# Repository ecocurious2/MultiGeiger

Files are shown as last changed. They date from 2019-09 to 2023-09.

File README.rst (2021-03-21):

MultiGeiger
-----------

The MultiGeiger is a radioactivity measurement device.
It has a lot of interesting properties, which you can find on the first page of the docs.

Der MultiGeiger ist ein Messgerät für Radioaktivität.
Er hat viele interessante Eigenschaften, die man auf der ersten Seite der Doku nachlesen kann.

Documentation
~~~~~~~~~~~~~

https://multigeiger.readthedocs.org/  (english + deutsch)

There is our new, versioned and translated documentation (see the box at the
lower right there to switch languages and documentation versions)!

Dort ist unsere neue, versionierte und übersetzte Doku (siehe die Box
rechts unten, mit der man Sprache und Version umschalten kann)!

Quicklinks
~~~~~~~~~~

* Default Wifi-Password: "ESP32Geiger"
* Multigeiger map / Karte:

  https://multigeiger.citysensor.de/

* Übersichtsseite bei Ecocurious / Ecocurious project overview page (German):

  https://ecocurious.de/projekte/multigeiger-2/

* Online Multigeiger event room with some instruction videos (German) to discover / Online Multigeiger-Raum mit einigen Anleitungsvideos zum Entdecken:

  https://play.wa.binary-kitchen.de/_/global/raw.githubusercontent.com/ecocurious2/rc3_2020/main/main.json

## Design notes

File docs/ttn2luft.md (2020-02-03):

# TTN --> Luftdaten
rxf 2020-02-03

### Payload der LoRa-Sendung

Port | ByteNr | Wert [hex]| Beschreibung | Beispiele
-----|--------|------|------------- | ---------
1    | 0/1/2/3 | 00000107 | Anzahl der Impulse (counts) | => 263
1    | 4/5/6   | 0249F0 | Messzeit [ms] für diese Impulse (sample\_time\_ms) | => 150000
1	   |	  7/8  | 10C0   | Software-Version (software_version)| 1.12.0 (siehe unten)
1	   |	   9   |  16    | Bezeichnung des Zählrohres (tube) |Si**22**G
||||
2	   |	  0/1   | 0107   | BME280 Temperatur in 0.1° (temperature)| 0x107 => 26.3°
2	   |	   2    | 9A     | BME280 Feuchte in 0.5% (humidity)|0x9A => 77.0%
2	   |	  3/4   | 26E0   | BME280 Luftdruck in 0.1 hPa (pressure) | 0x26E0 => 995.2 hPa

Erläuterung zur Software-Version: Die obersten 4 Bit sind die Major-Version (hier 1, max. 15), die folgenden 8 Bit die Minor-Version (hier 0x0C => 12) und die untersten 4 Bit der Patchlevel (hier 0).

Bezeichnung der z. Zt. implementierten Zählrohre:  

Name | Nummer [hex]
-----|-------
SBM-19 | 0x13
SBM-20 | 0x14
Si22G	 | 0x16

Die Daten des BME280 werden nur gesendet, wenn auch ein BME280 vorhanden ist.

### Payload-Decoder
Wir verwenden **keinen** Payload-Decoder.
Sollte es nötig sein, die Daten irgendwie umzuwandeln, dann muss die HTTP-Integration das machen - also das Programm, das da dahinter sitzt.

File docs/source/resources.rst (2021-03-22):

.. include:: global.rst.inc
.. _resources:

Resources
=========

This is a collection of additional resources that are somehow related to MultiGeiger.

Hardware / Parts
----------------
MultiGeiger supported counter tubes:
 -  Si22G, SBM-20, SBM-19

MultiGeiger supported ESP32 boards:

- Heltec WiFi Kit 32 (WiFi-only, infos from board manufacturer)
  https://heltec.org/project/wifi-kit-32/

- Heltec Wireless Stick (WiFi+LoRa, infos from board manufacturer)
  https://heltec.org/project/wireless-stick/

Software
--------

- Windows driver for the USB -> UART chip CP2102:
  http://esp32.net/usb-uart/#SiLabs

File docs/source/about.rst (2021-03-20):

About
-----

The **MultiGeiger** is a project of Ecocurious, your community for environment, nature and technology, see https://ecocurious.de/projekte/multigeiger/.

The goal is to establish a citizen measurement network for radioactivity in Germany.

The **MultiGeiger** hardware and software was designed by Jürgen Böhringer (http://www.boehri.de).

Reinhard/rexfue has further developed the software, the board, and is taking care of the integration of the sensors into our map https://ecocurious.de/multigeiger-karte/.

We have started the first workshops where you can assemble the components and the case with our support.

Workshop dates can be found here:
 * https://www.meetup.com/de-DE/Ecocurious-deine-Umwelt-Natur-und-Technik-Community/
 * https://ecocurious.de/events/

Does this sound interesting to you? Then join us, we cordially invite you!

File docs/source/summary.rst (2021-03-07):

Overview
========

What is MultiGeiger?
--------------------

The MultiGeiger is a radioactivity measurement device.

Main features
~~~~~~~~~~~~~

**multiple use cases supported**

 * fixed location stations (data transfer via network)
 * mobile operations (using the OLED display and speaker)
 * (more are planned)

**multiple 400V Geiger-Mueller tubes supported**

 * big, sensitive tubes, like the Si21g or Si22g (for measurement stations)
 * smaller, less sensitive tubes, like the SBM21 (good for finding hot spots)

**Hardware**

 * low parts count, simple to assemble
 * inexpensive, but still good parts
 * using ESP32, a modern and fast 32bit micro controller
 * with WiFi (WPA2) or with WiFi + LoRA
 * with OLED display

**Firmware**

 * implemented in C
 * using the popular arduino API
 * over-the-air firmware updates

**Network and Community**

 * this is an Ecocurious citizen science project
 * web-based geo map for publishing measurements
 * web-based archive of historic radiation data

**Free and Open**

 * GPL v3 licensed
 * open development and issue tracking on GitHub

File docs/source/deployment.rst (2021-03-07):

.. include:: global.rst.inc
.. highlight:: none
.. _deployment:

Deployment
==========

When deploying the MultiGeiger measurement station, you need to consider some things.

Of course, for us private persons, there rarely will be a 100% perfect deployment place.
But still, we can be aware of the parameters which may have a negative impact.

Requirements for the deployment place
#####################################

+--------------------------------------------------------------------------------------------+--------------------+
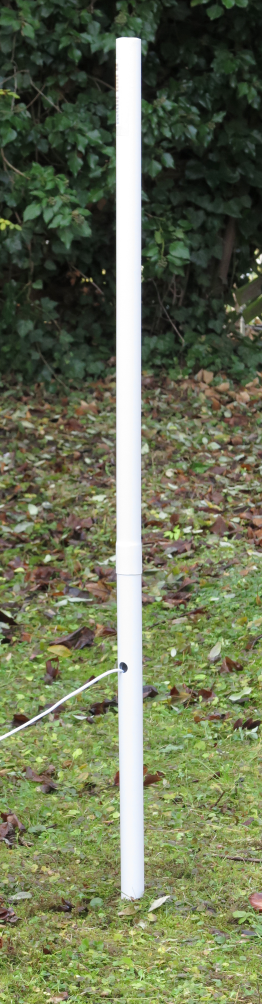
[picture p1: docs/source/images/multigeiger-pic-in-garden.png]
| In any case we need this at the deployment place:                                          |         |
|                                                                                            |                    |
| - WiFi or LoRa reception for data transmission (A)                                         |                    |
|                                                                                            |                    |
|   WiFi can come from inside the house, LoRa from some TTN LoRa gateway.                    |                    |
|                                                                                            |                    |
| - Power: 5 V / ~ 100 mA (B)                                                                |                    |
|                                                                                            |                    |
|   Power can come from inside the house via a 5V cable or from other power supply.          |                    |
|                                                                                            |                    |
| - Irrigation area (C)                                                                      |                    |
|                                                                                            |                    |
|   E.g. some lawn, meadow or similar that gets some rainfall, potentially including fallout.|                    |
+--------------------------------------------------------------------------------------------+--------------------+



Choosing a deployment place
###########################

We want to measure radioactive substances (dust), also known as "fallout".
They come from e.g. nuclear explosions or reactor desasters.

In a very weak variant, they also naturally come from the atmosphere due to the decay of the radioactive noble gas radon.
This "radon fallout" causes a small, but measurable peak on our devices, which degrades with a half life of 45 minutes.

With the help of these "radon peaks", we can see whether our device is deployed to a good place and is sensitive also for "real" fallout.

Irrigation area
---------------

We need a bigger irrigation area in the direct vicinity of the measurement station.
This area should also have the capability to hold and store radioactive particles.

A lawn or a meadow is perfect for this.

On the other hand, some asphalt can not do that, because particles are washed away directly after raining down. 

Wind direction
--------------

The area should be unobstructed from the main wind direction by other buildings, bushes or trees.

Sun light
---------

The power supply cable as well as the MultiGeiger device itself, should be in the shadows most of the time.

Direct sunlight can have two negative influences:

- Heat:
  The temperature inside the device can rise to up to 60 deg celsius in direct sunshine (45 deg celsius in the shadows).
  We did practical temperature tests showing that the device works ok up to 70 deg celsius.
  But the GM tube is only specified to up to 50 deg celsius.

- UV damage:
  Over time, the cable and case can be damaged by UV radiation and get porous.

Examples
########

Examples of good and bad deployment places:

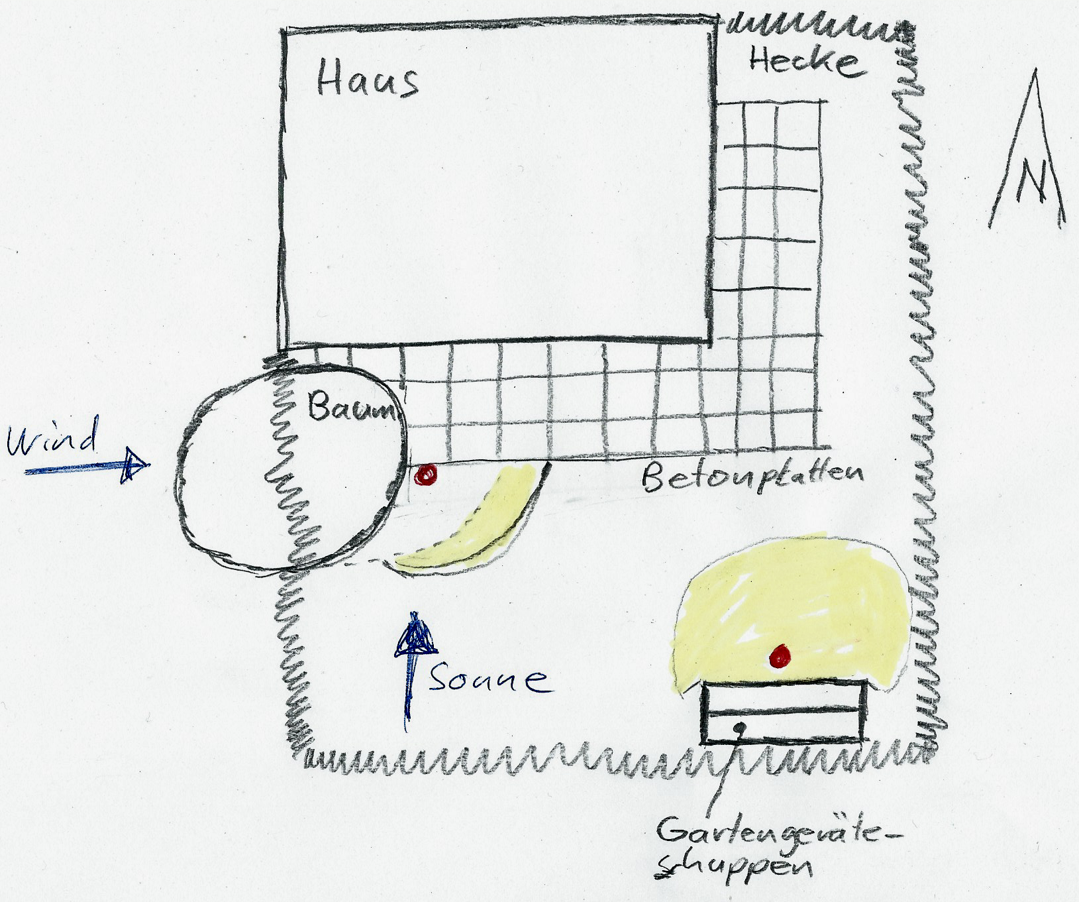
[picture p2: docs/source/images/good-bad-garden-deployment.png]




Comparison of two deployment places. Yellow is the "usable irrigation area".

Bad deployment place (red dot at the left)

Reasons:

- Meadow: a bit part of the area around the GM device is made of concrete platter. Incapable of holding/storing fallout.
- Wind: the main wind direction is from the west and the tree obstructs fallout raining down close to the device.
- Sun: Sunlight comes primarily from the south and strongly shines on the devices.

Good deployment place (red dot at the right) 

Reasons:

- Meadow: a big part of the area around the GM device is meadow, which can hold/store fallout.
- Wind: no obstruction
- Sun: the GM device is in the shadow due to the garden shack.

More Information
################

Description of the BFS-ODL measurement network (german):

- `Messnetz <https://www.bfs.de/SharedDocs/Downloads/BfS/DE/broschueren/ion/radioaktivitaetsmessnetz.pdf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>`_
- `ODL-Sonde <https://odlinfo.bfs.de/DE/themen/wie-wird-gemessen/odl-sonde.html>`_

Video interview about the BFS-ODL measurement network (german):

- `Interview über das BFS-ODL-Netzwerk <https://www.bfs.de/SharedDocs/Videos/BfS/DE/kt-interview-umweltueberwachung.html>`_

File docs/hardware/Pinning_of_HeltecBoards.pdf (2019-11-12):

### Table 1

PIN | Wifi Kit 32 (new) | Wireless Stick | WirelessStick Lite | Legend
0 | SPEAKER | SPEAKER | SPEAKER
1 | NOT AVAILABLE | NOT AVAILABLE | NOT AVAILABLE
2 | GMZ_CNT | GMZ_CNT | GMZ_CNT
3 | NOT AVAILABLE | NOT AVAILABLE | NOT AVAILABLE
4 | OLE_SDA | OLE_SDA | free
5 | free | LoRa_SCLK | LoRa_SCLK
6 | NOT AVAILABLE | NOT AVAILABLE | Flash_CLK
7 | NOT AVAILABLE | NOT AVAILABLE | Flash_SD3
8 | NOT AVAILABLE | NOT AVAILABLE | Flash_SD1 | | used by Geiger
9 | NOT AVAILABLE | NOT AVAILABLE | free | | internally used by chip
10 | NOT AVAILABLE | NOT AVAILABLE | free | | pin not broken out
11 | NOT AVAILABLE | NOT AVAILABLE | Flash_SD2 | | unused pins
12 | SPEAKER | SPEAKER | SPEAKER
13 | free | free | Power_Detect
14 | free | LoRa_RST | LoRa_RST
15 | OLED_SCL | OLED_SCL | free
16 | OLED_RST | OLED_RST | Flash_CS
17 | free | free | Flash_SD0
18 | free | LoRa_CS | LoRa_CS
19 | free | LoRa_MISO | LoRa_MISO
20 | NOT AVAILABLE | NOT AVAILABLE | NOT AVAILABLE
21 | free | V_SPI_HD | Vext_Control
22 | HV_CAP_FUL | HV_CAP_FUL | HV_CAP_FUL
23 | HV_FET_OUT | HV_FET_OUT | HV_FET_OUT
24 | NOT AVAILABLE | NOT AVAILABLE | NOT AVAILABLE
25 | LED | LED | LED
26 | free | LoRa_DIO0 | LoRa_DIO0
27 | free | LoRa_MOSI | LoRa_MOSI
28 | NOT AVAILABLE | NOT AVAILABLE | NOT AVAILABLE
29 | NOT AVAILABLE | NOT AVAILABLE | NOT AVAILABLE
30 | NOT AVAILABLE | NOT AVAILABLE | NOT AVAILABLE
31 | NOT AVAILABLE | NOT AVAILABLE | NOT AVAILABLE
32 | XTAL_32 | XTAL_32 | XTAL_32
33 | XTAL_32 | XTAL_32 | XTAL_32
34 | free - IN _ NO_PUP | LoRa_DIO2 | LoRa_DIO2
35 | free - IN _ NO_PUP | LoRa_DIO1 | LoRa_DIO1
36 | GPIO36 - IN _ NO_PUP | GPIO36 - IN _ NO_PUP | GPIO36 - IN _ NO_PUP
37 | GPIP37 - IN _ NO_PUP | GPIP37 - IN _ NO_PUP | GPIP37 - IN _ NO_PUP
38 | GPIO38 - IN _ NO_PUP | GPIO38 - IN _ NO_PUP | GPIO38 - IN _ NO_PUP
39 | GPIO38 - IN _ NO_PUP | GPIO38 - IN _ NO_PUP | GPIO38 - IN _ NO_PUP

1

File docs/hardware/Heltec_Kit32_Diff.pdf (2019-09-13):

# Unterschied Heltec Wifi 32:

Zwei neue Boards mit identischer Bezeichnung wie die alten (Heltec WiFi Kit 32) am 10.9.2019 bei Amazon gekauft. Leider unterscheiden diesen beiden sich von den alten (bei Ali gekauften) Boards:
Alt: | Neu:

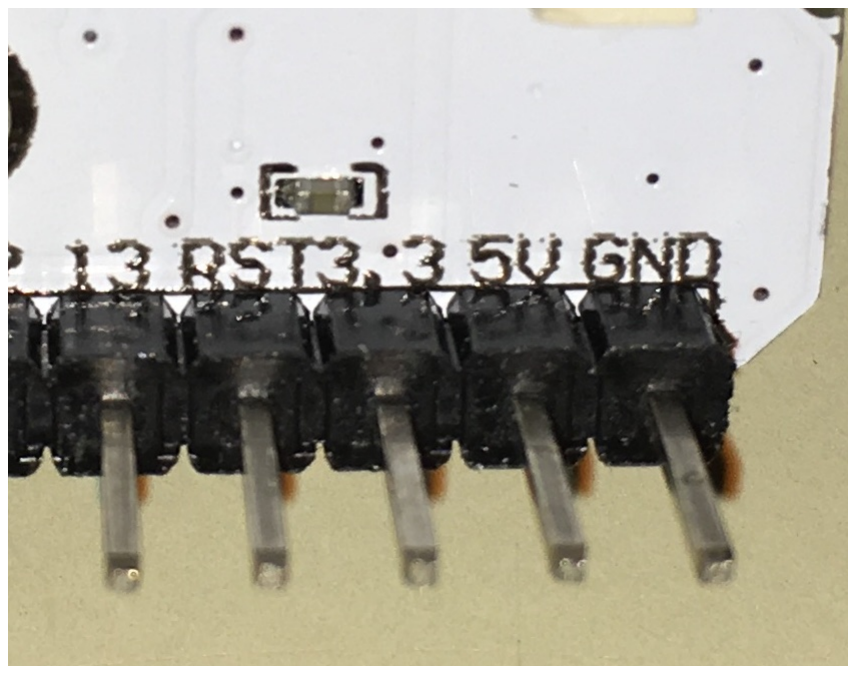
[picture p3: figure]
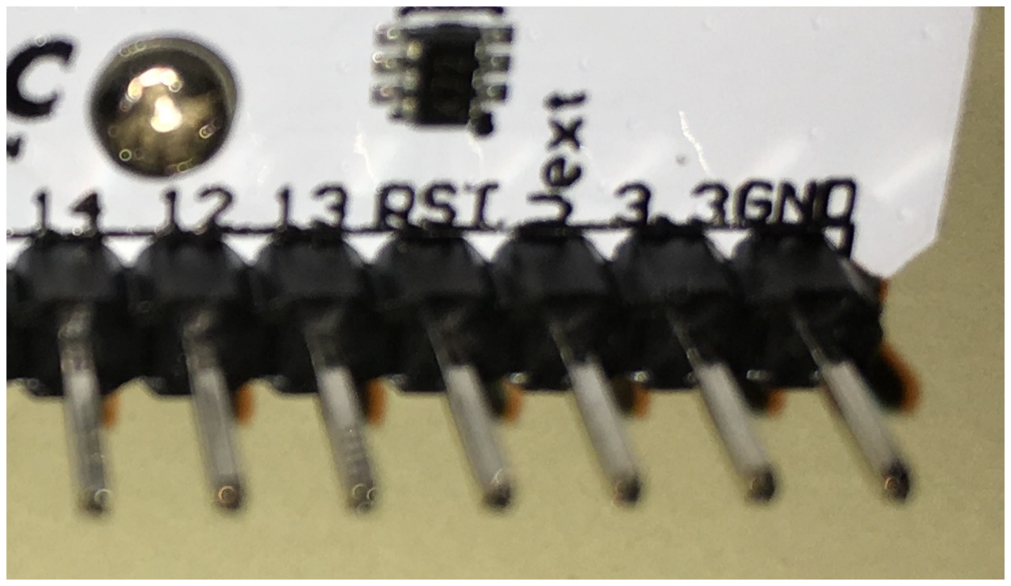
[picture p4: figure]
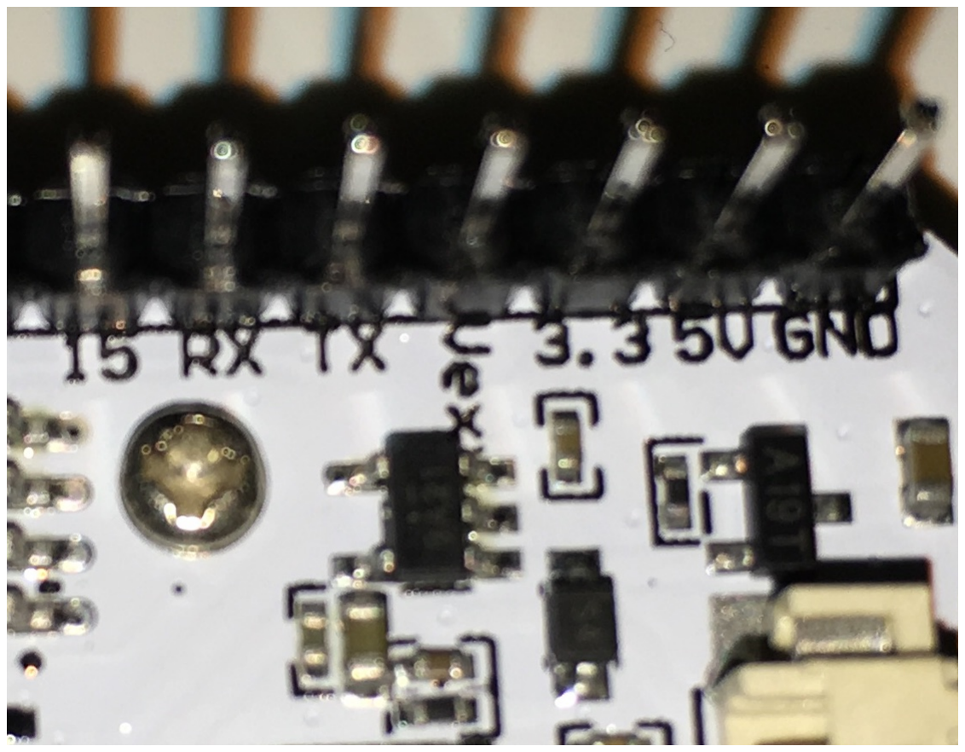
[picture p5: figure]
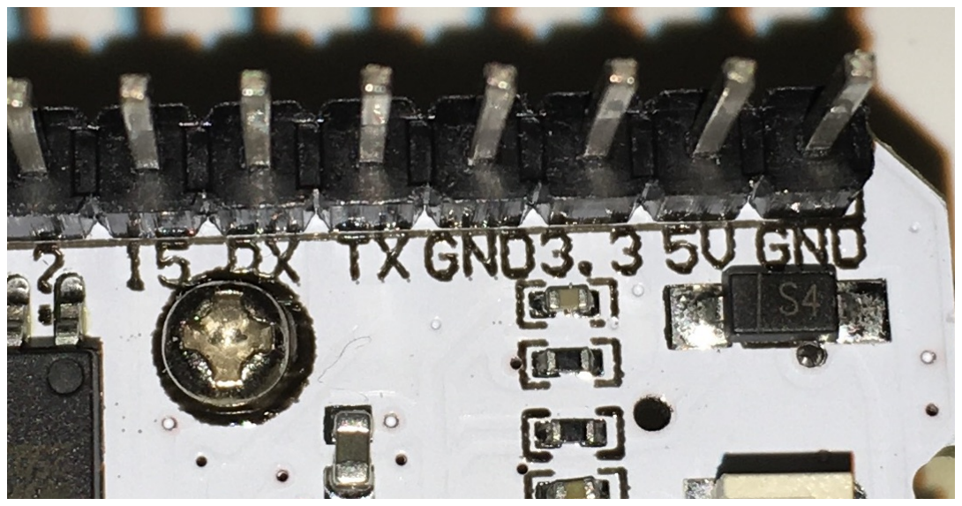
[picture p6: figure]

Die beiden Borads unterscheiden sich in den Power-Anschlüssen. Insbesondere ist der zweite GND-Anschluss am alten Board (Bild unten links neben dem TX-Pin) gefährlich, da damit auf dem neuen Board die Versorgung Vext auf Ground gelegt wird !!!

Das Problem kann durch eine Layout-Änderung behoben werden.

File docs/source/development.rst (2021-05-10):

.. include:: global.rst.inc
.. highlight:: bash
.. _development:

Development
===========

This chapter will get you started with |project_name| development.

|project_name| is written in C using Arduino-ESP32.

Contributions
-------------

... are welcome!

Some guidance for contributors:

- discuss about changes on github issue tracker

- make your PRs against the ``master`` branch

- do clean changesets:

  - focus on some topic, resist changing anything else.
  - do not do style changes mixed with functional changes.
  - run the automatic code formatter before committing
  - try to avoid refactorings mixed with functional changes.
  - if you need to fix something after commit/push:

    - if there are ongoing reviews: do a fixup commit you can
      merge into the bad commit later.
    - if there are no ongoing reviews or you did not push the
      bad commit yet: edit the commit to include your fix or
      merge the fixup commit before pushing.
  - have a nice, clear, typo-free commit comment
  - if you fixed an issue, refer to it in your commit comment

- make a pull request on github and check on the PR page
  what the CI system tells about the code in your PR

- wait for review by other developers

Building a development environment
----------------------------------

TODO

Automatic Code Formatter
------------------------

We use astyle_ for automated code formatting / formatting checks.

Run it like this:

::

  astyle --options=.astylerc 'multigeiger/\*'

.. _astyle: http://astyle.sourceforge.net/

Documentation
-------------

Building the docs with Sphinx
~~~~~~~~~~~~~~~~~~~~~~~~~~~~~

Documentation is written in English and translated to other languages from that source (initially German).

The documentation (in reStructuredText format, .rst) is in ``docs/source/``,
``index.rst`` is the starting point there.

To build the docs, you need to have Sphinx_ installed and run:

::

  cd docs/
  make html

Then point a web browser at ``docs/build/html/index.html``.

The website is updated automatically by ReadTheDocs through GitHub web hooks on the
main repository.

After changes of the (english) master docs, the translation master files (``*.pot``)
need updating (adding/removing/updating strings in there):

::

  cd docs/build/gettext
  sphinx-build -b gettext ../../source .

Then, these changes need to get pushed to transifex, so translators can comfortably
translate on the web:

Translation is organised via [transifex](https://www.transifex.com/thomaswaldmann/multigeiger/), 
you need to have an account or at least login there and fire a "join team" request. 
Then translate the missing parts and notify the developers (e.g. via issue tracker).

::

  tx push --source

Later, after translators did their part, updated translations need to get pulled
from transifex:

::

  tx pull --all --force

Now we have changes in our git workdir and we need to commit them:

::

  git add locales/
  git commit -m "updated translations"
  git push

This will trigger a build of the docs and their translation(s) on readthedocs.io.

.. _Sphinx: https://www.sphinx-doc.org/

Flashing devices / creating binaries
------------------------------------

Arduino IDE:

- do a git checkout of the wanted release, e.g. ``git checkout V1.13.0``
- use the default userdefines.h (available as userdefines-example.h)
- IDE settings:

  - Device: Heltec WiFi Stick  (always use this, even if you have a WiFi Kit 32)
  - Flash size: 4MB (32Mb)
  - Partition scheme: minimal SPIFFS (large APPS with OTA) - this fits onto 4MB devices.
- ``Arduino IDE -> Sketch -> Upload``

  This is to test whether the compiled code actually works after USB-flashing to your device.
- ``Arduino IDE -> Sketch -> Export compiled binary``

  This creates a .bin file for OTA updating. Test whether OTA updating using that file works.

.. _releasing:

Creating a new release
----------------------

Checklist:

- make sure all issues for this milestone are closed or moved to the
  next milestone
- check if there are any pending fixes for severe issues
- check whether some CA certificate (see ``ca_certs.h``) will expire soon and
  whether we already can add their next valid cert.
- find and fix any low hanging fruit left on the issue tracker
- close release milestone on Github
- update ``docs/source/changes.rst``, based on ``git log $PREVIOUS_RELEASE..``
- ``bump2version --new-version 1.23.0 release`` - this will:

  - update versions everywhere
  - auto-create a git tag
  - auto-create a git commit
- review the automatically generated changeset
- create a github release for this tag:

  - create a binary (see above) and attach to the github release
  - add a link to the relevant ``changes.rst`` section to the github release

- ``bump2version --no-tag --current-version 1.23.0 minor`` - this will:

  - update versions everywhere (now to: 1.24.0-dev)
  - not quite correctly update changes.rst, will need manual fixing afterwards
  - after fixing: git commit --amend

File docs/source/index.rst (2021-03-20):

.. MultiGeiger documentation master file, created by
   sphinx-quickstart on Sat Jan 18 21:31:55 2020.
   You can adapt this file completely to your liking, but it should at least
   contain the root `toctree` directive.

.. include:: global.rst.inc
.. highlight:: none

MultiGeiger Documentation
=========================

.. include:: summary.rst

.. toctree::
   :maxdepth: 2

   about
   assembly
   setup
   setup_lora
   usage
   deployment
   faq
   resources
   changes
   development
   authors

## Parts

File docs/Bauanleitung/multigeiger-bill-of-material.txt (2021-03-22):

TEIL	ANZAHL 	BESCHREIBUNG	Artikelbezeichnung	LINK
T1	1	N-MOS-Transistor BSP125,	BSP125H6433XTMA1	https://www.digikey.ch/product-detail/de/BSP125H6433XTMA1/BSP125H6433XTMA1CT-ND/8416918
R1	1	kOhm Widerstand, braun-schwarz-orange-gold, Kohleschicht, 0411, 500 mW, 5%	z.B. RD12JN103T52	https://www.reichelt.de/ch/de/widerstand-kohleschicht-10-kohm-0411-500-mw-5--k-o-rd12jn103t52-p237431.html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
R2, R5	2	1,0 Mohm Widerstand, braun-schwarz-grün-gold, Kohleschicht, 0207, 250 mW, 5%	z.B. CFR-25JT-52-1M	https://www.reichelt.de/ch/de/widerstand-kohleschicht-1-0-mohm-0207-250-mw-5--1-4w-1-0m-p1316.html?&nbc=1
R3, R4	2	4,7 Mohm Widerstand, gelb-violett-grün-gold,  Kohleschicht, 0207, 250 mW, 5%	z.B. CFR-25JT-52-4M7	https://www.reichelt.de/ch/de/widerstand-kohleschicht-4-7-mohm-0207-250-mw-5--1-4w-4-7m-p1426.html?&nbc=1
D1, D2	2	Z-Diode, ZY 200	ZY200 oder BZX85C200	https://www.reichelt.de/ch/de/zenerdiode-200-v-2-w-do-41-zy-200-dio-p219675.html?&nbc=1 oder https://www.reichelt.de/ch/de/zenerdiode-200-v-2-w-do-204al-do41-zy-200-p23258.html?&nbc=1
D3	1	Z-Diode, 3,3 V, 0,5 W, DO-35	BZX55C3V3	https://www.reichelt.de/ch/de/zenerdiode-3-3-v-0-5-w-do-35-bzx-55c3v3-vis-p219425.html?&nbc=1
D4	1	Gleichrichterdiode, 1000 V, 1 A, SOD-57	BYV26E	https://www.reichelt.de/ch/de/gleichrichterdiode-1000-v-1-a-sod-57-byv-26e-p216750.html?&nbc=1
D6	1	Gleichrichterdiode GP10Y, 1.6 kV, 1 A	GP10Y-E3/54	https://www.digikey.ch/product-detail/de/GP10Y-E3%2f54/GP10Y-E3%2f54GICT-ND/3026056
C1	1	ELKO Elektrolytkondensator 100 uF, 16 V	SKR101M1CE11VM	https://www.reichelt.de/ch/de/elko-radial-100-f-16-v-rm-2-5-85-c-20--jam-skr101m1ce11-p229977.html?&nbc=1
C2	1	Folienkondensator, 10nF, 100V, FKP2-100 10N, "0.01  100-"	FKP2D021001I00HSSD	https://www.reichelt.de/ch/de/folienkondensator-10nf-100v-rm5-fkp2-100-10n-p172454.html?&nbc=1
C3	1	Folienkondensator, 100nF, 630V, MKP4-630 100N, "0.1  630-"	MKP4J031004D00KSSD	https://www.reichelt.de/ch/de/folienkondensator-100nf-630v-rm15-mkp4-630-100n-p173032.html?&nbc=1
C4	1	Folienkondensator, 100pF, 1000V, FKP2-1000 100P, "100/1000-"	FKP2O101001D00HSSD	https://www.reichelt.de/ch/de/folienkondensator-100pf-1000v-rm5-fkp2-1000-100p-p31949.html?&nbc=1
L1	1	Spule, 150 uH, "154J"	11P-154J-50	https://www.reichelt.de/ch/de/stehende-induktivitaet-11p-ferrit-150m-l-11p-150m-p73012.html?&nbc=1
Pz1	1	Piezo-Lautsprecher	AL-60SP05	https://www.reichelt.de/ch/de/elektromagnetischer-summer-summer-tdb-05-p35918.html?&nbc=1
X1, X2	2	Zählrohrhalter		
	1	Zählrohr SBM-20, SBM-19 oder Si22G, (andere möglich, wobei Umrechnungsfaktor muss in Firmware angepasst werden muss)	 SBM-20, SBM-19 oder Si22G	diverse, z.B. ebay, häufig russische oder ukranische Verkäufer
	2	Buchsenleiste, Fassung für Microcontroler-Modul

Optional Parts
TEIL	ANZAHL 	BESCHREIBUNG	Artikelbezeichnung	LINK
S2	1	DIP-Schalter, 4-polig, Piano-Dip Ausführung	DP 04	https://www.reichelt.de/index.html?ACTION=446&LA=0&nbc=1&q=dp%2004

R6, R7, R8, R9	4	10k Ohm SMD Widerstand, 0805	RND 0805 1 10K	https://www.reichelt.de/smd-widerstand-0805-10-kohm-125-mw-1--rnd-0805-1-10k-p183251.html?&trstct=pos_12&nbc=1

I2C	1	Stiftleiste Micro JST 1.5mm, ZH 4-Pin,

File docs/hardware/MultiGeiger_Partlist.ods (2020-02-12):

Reference-Designator | Quantity | Name | Order-No | Source | Notes
 | 1 | Heltec-Module „WIFI KIT 32“ with 0.96”OLED Bluetooth | WIFI KIT 32 | https://heltec.org/project/wifi-kit-32/
 | 0 | Heltec-Module „Wireless Stick (Gecko Board)“, 868 MHz | Wireless Stick (Gecko Board), 868 MHz | https://heltec.org/project/wireless-stick/ | alternatively: if LoRa-WAN is required
 | 1 | Platine Multigeiger V 1.4 jb/rxf 2019-09 |  | Reinhard
Ro1 | 1 | Geiger Tube, our Standard | SI-22G = CI-22G | EBAY (gut: "any-devices", "alexer1", “sovtube“): oftmals sind Röhren defekt – jedoch wird das Geld auf anfrage zurückerstattet!
 | 2 | Fassung für uC-Modul, Buchsenleiste | BL 1X20G8 2,54 | www.reichelt.de
X1, X2 | 2 | Sicherungshalter für 6,3 x 32 mm | SCH 80400001 . Alternativ: EBAY, Sicherungshalter Clip für 6,3x32mm Feinsicherungen/Glassicherungen, liebstoeckl-2015 Alternativ: www.pollin.de, Nummer: 94-260594 | www.reichelt.de
Pz1 | 0 | Piezo-Signalgeber 98 dB | 1365793 - 62 | conrad.de | alternatively: bigger - but cheper
Pz1 | 1 | Piezo-Signalgeber 98 dB | SUMMER EPM 121 | www.reichelt.de
L1 | 1 | Stehende-Induktivität, 11P, Ferrit, 150M | L-11P 150M | www.reichelt.de | L=150 mH
T1 | 1 | N-MOS-Transistor BSP125 |  | EBAY, Shop: elektronikposten, rs-components.de
D1, D2 | 2 | Zenerdiode, 200 V, 2 W, DO-41 | ZY 200 | www.reichelt.de
D3 | 1 | Zenerdiode, 3,3 V, 0,5 W, DO-35 | BZX 55C3V3 VIS | www.reichelt.de
D4 | 1 | BYV 26E | BYV 26E | www.reichelt.de | in Glas Housingboth Diodes in series, D4 a towards the Coil
D6 | 1 | GP10Y | 567595 (Conrad-Nr.) | www.conrad.de, EBAY, rs-components.de EBAY: pollinelectronic | in Plastic Housing, both Diodes in series, , D4 b towards the Capacitor
R1 | 1 | 1/4W 10K Widerstand, Kohleschicht, 10 kOhm, 0207, 250 mW, 5% | 1/4W 10K | www.reichelt.de
R2, R5 | 2 | 1/4W 1,0M Widerstand, Kohleschicht, 1,0 MOhm, 0207, 250 mW, 5% | 1/4W 1,0M | www.reichelt.de
R3, R4 | 2 | 1/4W 4,7M Widerstand, Kohleschicht, 4,7 MOhm, 0207, 250 mW, 5% | 1/4W 4,7M | www.reichelt.de
C1 | 1 | Elko radial, 100 uF, 16 V, 105°C, low ESR | RAD FR 100/16 | www.reichelt.de
C2 | 1 | Folienkondensator, 10nF, 100V, RM5 | MKP2-100 10N | www.reichelt.de
C3 | 1 | Folienkondensator, 100nF, 630V, RM15 | MKP4-630 100N | www.reichelt.de
C4 | 1 | Folienkondensator, 100pF, 1000V, RM5 | FKP2-1000 100P | www.reichelt.de
 | 1 | CE-zertifiziertes Netzteil mit Hohlstecker (5,5 / 2,1 mm) | SNT 1000 5V | www.reichelt.de
 | 1 | 10 m Verlängerungskabel Hohlstecker (5,5 / 2,1 mm) | DC CAB 21 10M | www.reichelt.de
 | 1 | Adapter Hohlstecker (5,5 / 2,1 mm) => Micro-USB | RPI DC-MICRO USB | www.reichelt.de
 | 1 | Installationsrohr starr M40 grau 3m | EAN 8027788360043 | www.hornbach.de
 | 0,25 | Tehalit Kabelkanal 20x35 mm reinweiß 2m | EAN 4012740327541 | www.hornbach.de
 | 0,1 | Silikon-Kleber Fix All Crystall 80 Gramm | EAN 5411183085084 | www.hornbach.de
 | 0,03 | Haupa 262604 Kabelbinder UV-beständig 142x2,5 mm Nylon schwarz 100 Stück | Art. 7459016 EAN: 4011923099107 | www.hornbach.de
 | 0,02 | Haupa 262618 Kabelbinder UV-beständig 250x4,8 mm Nylon schwarz 100 Stück | Art. 6094001 EAN: 4011923099190 | www.hornbach.de
 | 2 | aponorm® Schraubdeckel-Dose 30 g / 35 ml | ??? | Apotheke / Pharmacy
 | 1 | Warnaufkleber Hochspannung |  | Juergen
 |  | Lötzinn
 |  | etwas Flexible Litze (für Masseanschluss des Zählrohrs)

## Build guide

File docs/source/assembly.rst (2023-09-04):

.. include:: global.rst.inc
.. _assemblyguide:

Assembly
========

.. Die erste Version dieser Anleitung stammte von einem Handout von Jürgen Böhringer mit dem Titel ``Wie baue ich einen Multigeiger?`` (damals: HW-Version V1.4 jb/rxf 2019-09  -  Handout-Version 2021-03-03)

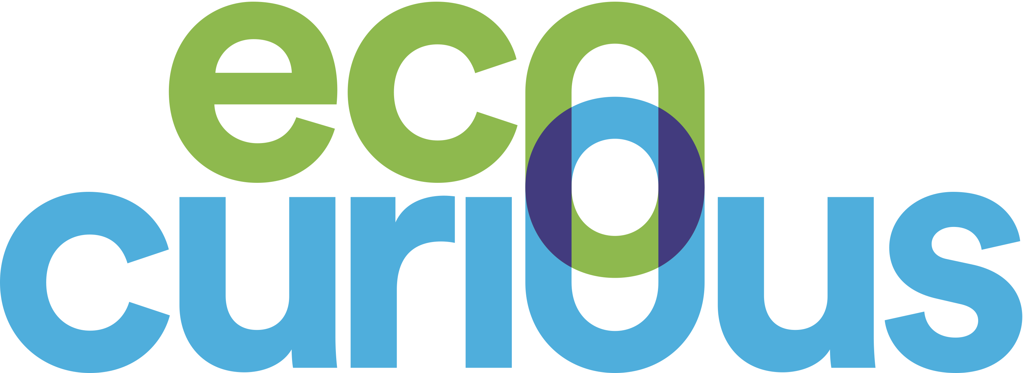
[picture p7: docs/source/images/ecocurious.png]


Ergebnis
########
Das Multigeigerprojekt ist eine Idee der `Ecocurious-Initiative <https://ecocurious.de/projekte/multigeiger-2/>`_.
Das dazugehörige Open-Source Multigeigermessgerät zum Messen radioaktiver Gammastrahlung wird von der Community entwickelt.
Die Echtzeitdaten der stationären Geräte werden per LoRaWAN oder WiFi/WLAN an einen Server gefunkt und auf einer `Karte <https://ecocurious.de/multigeiger-karte/>`_ visualisiert.
So entsteht ein Radioaktivitätsmessnetz in Bürgerhand, das wir hiermit aufbauen wollen.
Herzliche Einladung zum Mitmachen!

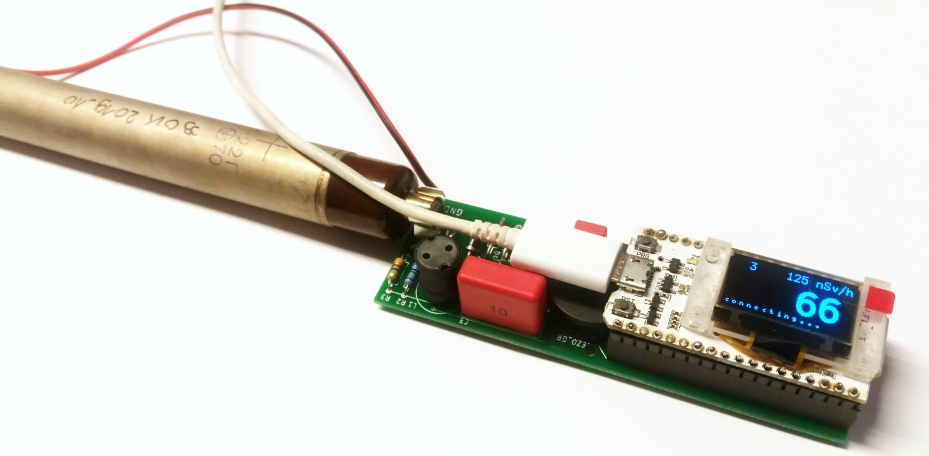
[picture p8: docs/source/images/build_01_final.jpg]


Bauteile
########

Elektronikbauteile aus (s. `Stückliste <https://github.com/ecocurious2/MultiGeiger/blob/master/docs/hardware/MultiGeiger_Partlist.ods?raw=true>`_) zunächst sortieren und auf Vollständigkeit prüfen:



































+-------+---+------------------------------------+------------------------------------------+
| ID(s) | # | Bild                               | Typ                                      |
+=======+===+====================================+==========================================+
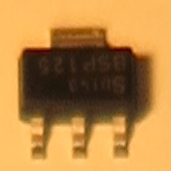
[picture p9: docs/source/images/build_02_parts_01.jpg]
| T1    | 1 |                           | N-MOS-Transistor BSP125                  |
+-------+---+------------------------------------+------------------------------------------+
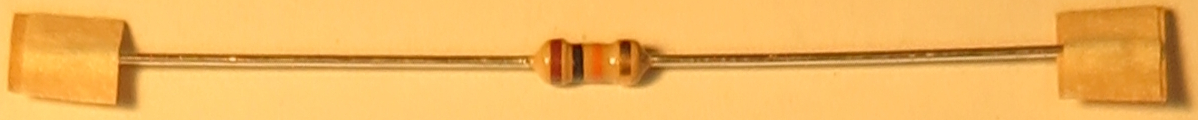
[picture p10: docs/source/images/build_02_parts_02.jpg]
| R1    | 1 |                           | 10K Widerstand braun-schwarz-orange-gold |
+-------+---+------------------------------------+------------------------------------------+
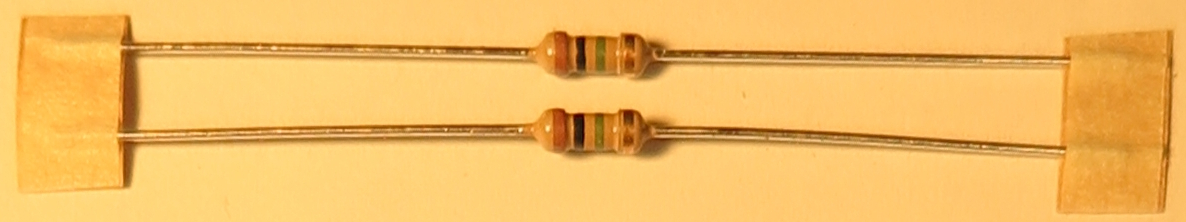
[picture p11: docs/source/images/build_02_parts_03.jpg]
| R2 R5 | 2 |                           | 1,0M Widerstand braun-schwarz-grün-gold  |
+-------+---+------------------------------------+------------------------------------------+
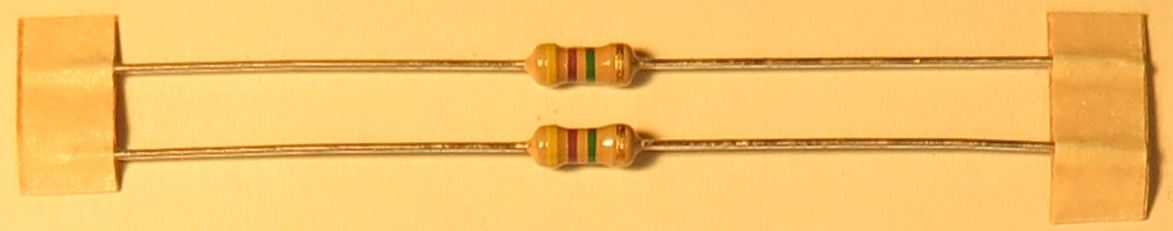
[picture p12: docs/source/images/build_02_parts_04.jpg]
| R3 R4 | 2 |                           | 4,7M Widerstand gelb-violett-grün-gold   |
+-------+---+------------------------------------+------------------------------------------+
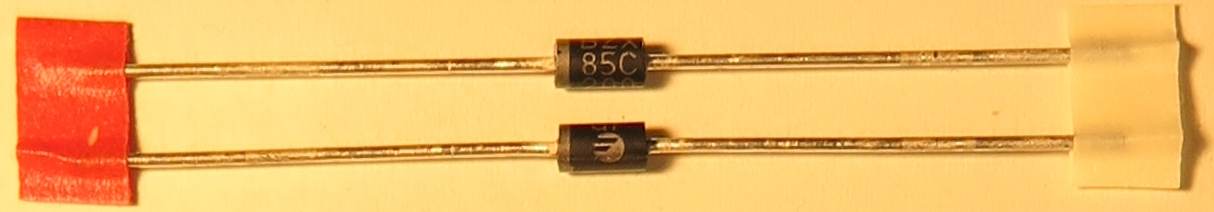
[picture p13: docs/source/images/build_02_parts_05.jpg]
| D1 D2 | 2 |                           | Z-Diode ZY 200                           |
+-------+---+------------------------------------+------------------------------------------+
| D3    | 1 |                           | Z-Diode BZX55C3V3                        |
+-------+---+------------------------------------+------------------------------------------+
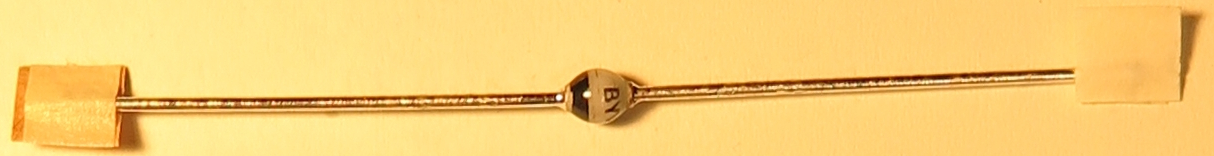
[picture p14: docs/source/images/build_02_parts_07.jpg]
| D4    | 1 |                           | Gleichrichterdiode BYV 26E               |
+-------+---+------------------------------------+------------------------------------------+
| D6    | 1 |                           | Gleichrichterdiode GP10Y                 |
+-------+---+------------------------------------+------------------------------------------+
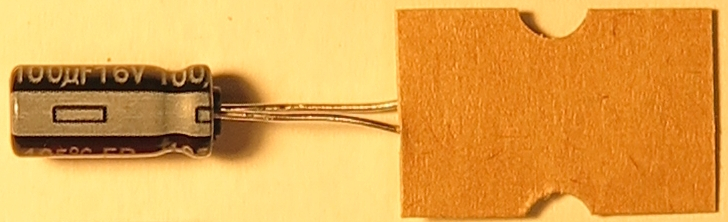
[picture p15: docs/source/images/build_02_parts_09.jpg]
| C1    | 1 |                           | ELKO Elektrolytkondensator 100 uF, 16 V  |
+-------+---+------------------------------------+------------------------------------------+
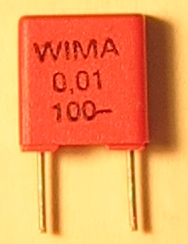
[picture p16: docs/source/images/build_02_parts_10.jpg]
| C2    | 1 |                           | Folienkondensator 10nF, 100V 0.01  100-  |
+-------+---+------------------------------------+------------------------------------------+
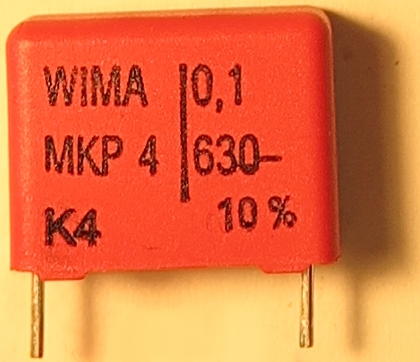
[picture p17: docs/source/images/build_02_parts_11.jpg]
| C3    | 1 |                           | Folienkondensator 100nF, 630V 0.1  630-  |
+-------+---+------------------------------------+------------------------------------------+
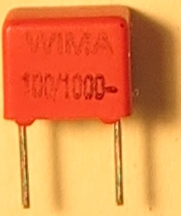
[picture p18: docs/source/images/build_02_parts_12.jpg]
| C4    | 1 |                           | Folienkondensator 100pF, 1000V 100/1000- |
+-------+---+------------------------------------+------------------------------------------+
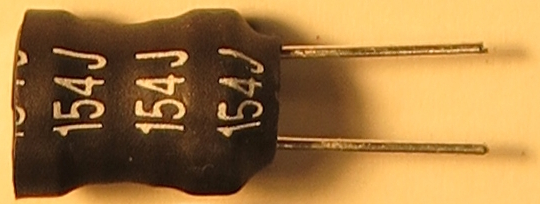
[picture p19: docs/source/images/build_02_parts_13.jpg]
| L1    | 1 |                           | Spule 150mH 154J                         |
+-------+---+------------------------------------+------------------------------------------+
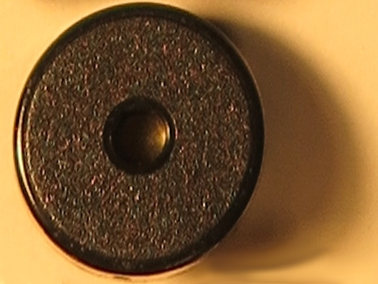
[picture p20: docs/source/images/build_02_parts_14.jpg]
| Pz1   | 1 |                           | Piezo-Lautsprecher                       |
+-------+---+------------------------------------+------------------------------------------+
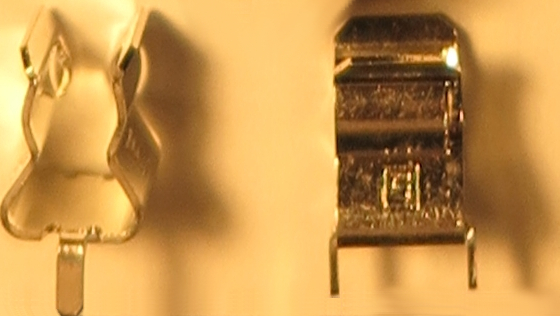
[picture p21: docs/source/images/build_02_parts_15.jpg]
| X1 X2 | 2 |                           | Zählrohrhalter                           |
+-------+---+------------------------------------+------------------------------------------+
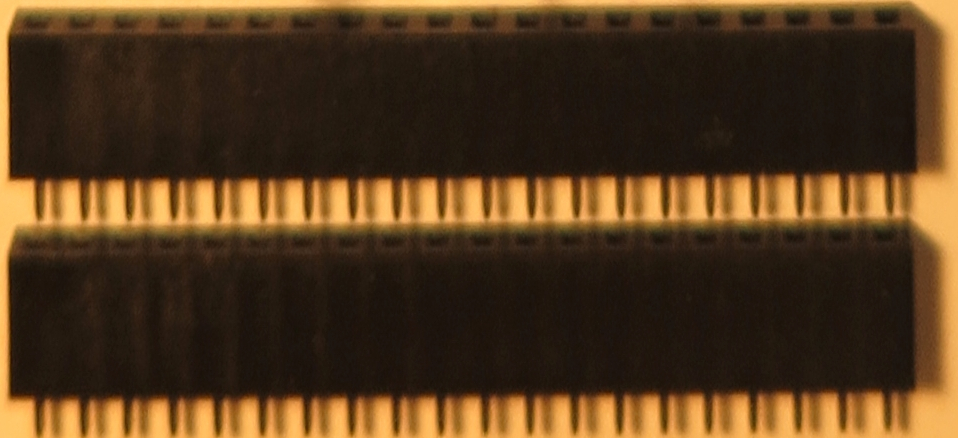
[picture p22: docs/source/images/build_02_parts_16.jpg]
|       | 2 |                           | Buchsenleiste Microcontroler-Modul       |
+-------+---+------------------------------------+------------------------------------------+
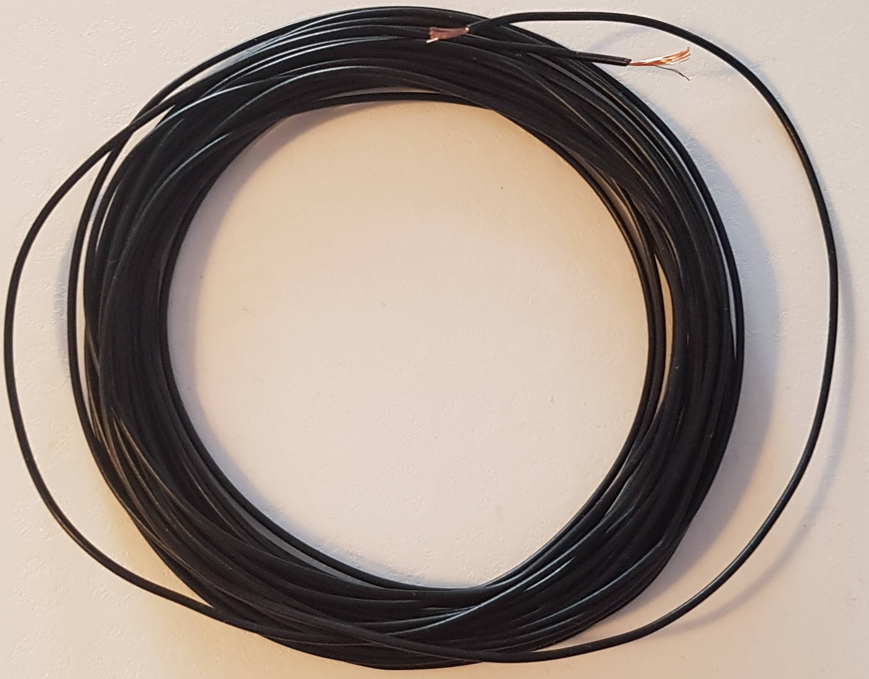
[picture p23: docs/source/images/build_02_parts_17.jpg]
|       | 2 |                           | Je 30 cm isolierte Kupferlitze           |
+-------+---+------------------------------------+------------------------------------------+
|       | 1 |                                    | Micro-USB Stromversorgung                |
+-------+---+------------------------------------+------------------------------------------+

Lötarbeiten
###########

Feldeffekt-Transistor T1
------------------------

Als erstes Bauteil wird das einzige Bauteil im SMD-Bauform montiert.
Mit Klebeband (Kreppband hat sich bewährt) wird er so auf die Platine geklebt, so dass die drei Pins sichtbar sind.
Dann werden die vorderen Anschlüsse verlötet, das Klebeband vorsichtig entfernt und der hintere Anschluss verlötet.

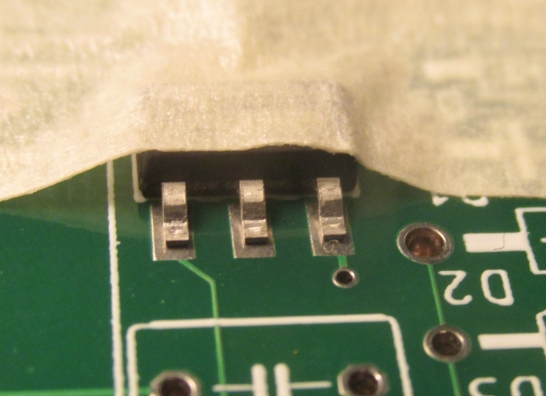
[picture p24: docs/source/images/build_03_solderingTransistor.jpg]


Widerstände und Dioden
----------------------

Die Widerstände und Dioden werden alle in einer Abbiegevorrichtung (oder entsprechend mit der Hand oder einer kleinen Zange) gebogen.
Die Breite ist immer vier Einheiten – sprich ca. 10 mm.

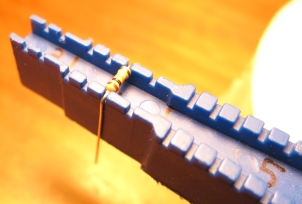
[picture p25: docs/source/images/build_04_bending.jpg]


Anschließend wird die Platine mit den Widerständen und Dioden bestückt.
Bei den Dioden unbedingt auf die Polarität achten! Die Kathode (Minus-Pol) ist mit einem Strich auf Platine und Bauteil markiert.

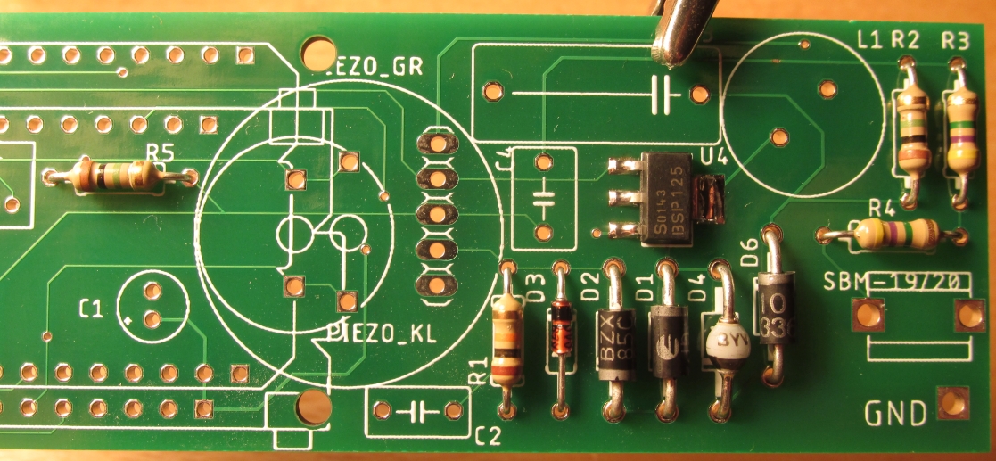
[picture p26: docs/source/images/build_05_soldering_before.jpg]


Vor dem Löten der Unterseite werden die Bauteile auf der Oberseite mit Klebeband fixiert, oder die Beinchen der Bauteile durch leichtes Auseinanderbiegen verklemmt.
Dann Bauteile anlöten, Klebeband entfernen und überschüssigen Draht abschneiden.

.. note:: Verletzungsgefahr: Beim Abschneiden darauf achten, dass der davonfliegende Draht niemanden verletzten kann.
   Möglichst festhalten beim Abschneiden!

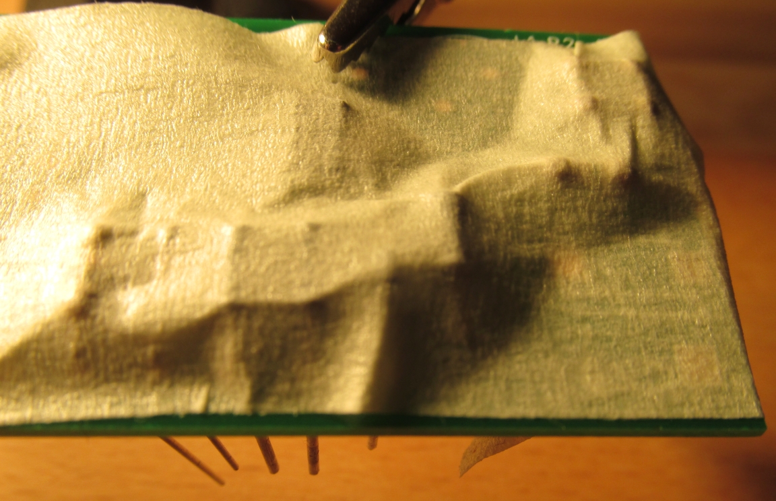
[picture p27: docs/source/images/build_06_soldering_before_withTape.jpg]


Kondensatoren und restliche Bauteile
------------------------------------

Der Elektrolytkondensator (Elko) wird vorher mit einer Flachzange angewinkelt. Beim Elko unbedingt auf die Polung achten:
Auf dem Elko ist der „–“-Pol markiert, auf der Platine der „+“-Pol. Die Beschriftungen müssen sich gegenüber liegen.
Der Zählrohrhalter muss so herum eingesetzt werden, dass das Zählrohr nach außen steht kann – am besten testen!
Dann die Bauteile mit Klebeband fixieren, anlöten und den überschüssigen Draht abschneiden.

Kondensatoren, Zählrohrhalter, Spule, Piezo-Lautsprecher sind bestückt:

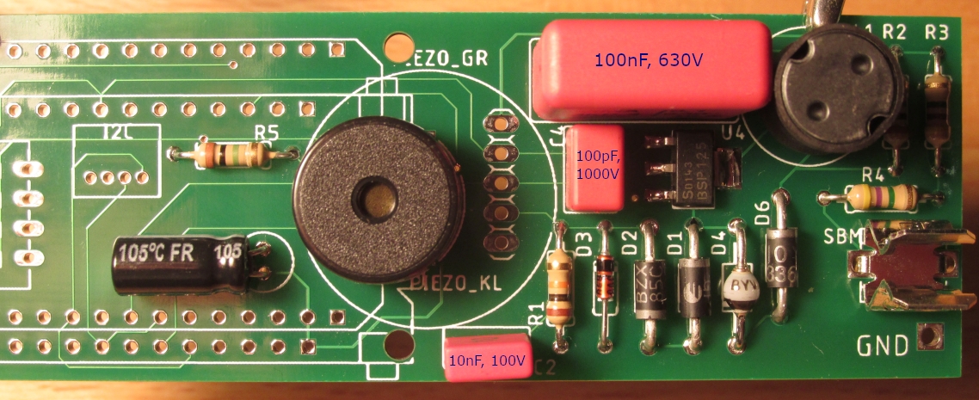
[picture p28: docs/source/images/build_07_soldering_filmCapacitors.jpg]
Kondensatoren, Zählrohrhalter, Spule, Piezo-Lautsprecher sind bestückt


Buchsenleisten und Mikrocontroller-Modul
----------------------------------------

Die Buchsenleiste muss vorher evtl. noch gekürzt werden.

.. note:: Dabei muss der Seitenschneider genau auf dem **letzten nicht mehr benötigten Kontakt** angesetzt werden – **nicht dort wo man ihn eigentlich kürzen will** – ansonsten kann sie splittern.
   Beim Abschneiden wegfliegende Teile möglichst festhalten!

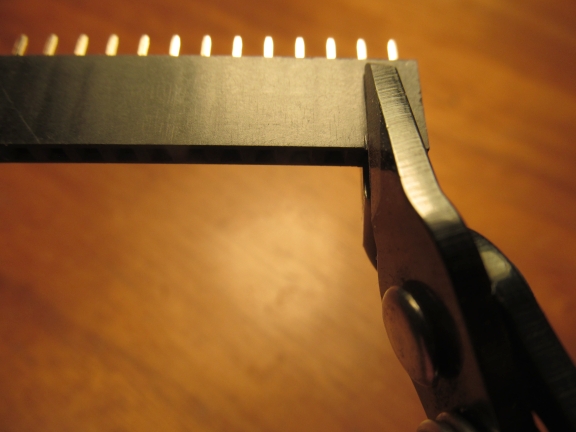
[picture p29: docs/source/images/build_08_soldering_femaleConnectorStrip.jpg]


Wird der große Piezo-Lautsprecher verwendet, so sollte die Buchsenleiste mit einer Feile etwas abgefeilt werden (vorher ausprobieren).
Am einfachsten geht das an der originalen, nicht bearbeiteten Seite der Buchsenleiste.
Je nachdem, welches Mikrocontroller-Board verwendet wird, müssen die Buchsenleisten an den entsprechenden Stellen bestückt werden.

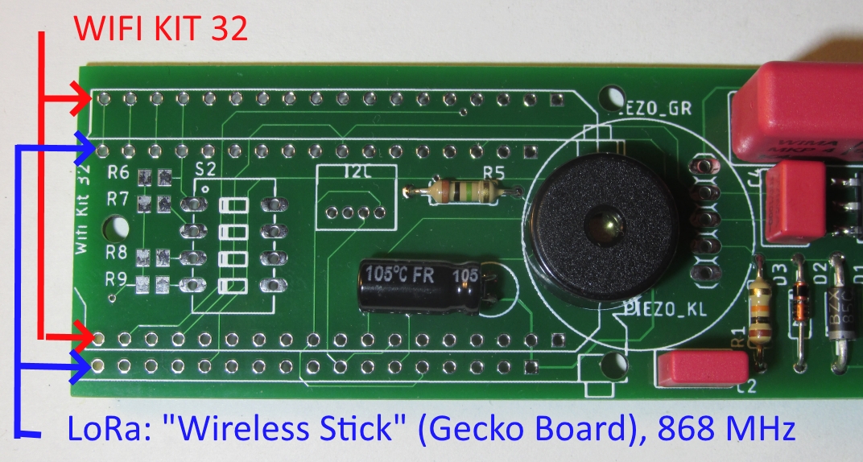
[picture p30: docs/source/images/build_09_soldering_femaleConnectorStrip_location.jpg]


Die Winkel der Buchsenleiste sollten genau stimmen. Daher am besten so vorgehen:

* Die erste Buchsenleiste einstecken.
* Von unten her eine Lötstelle in der Mitte löten, die Lötstelle nochmals heiß machen und gleichzeitig die Buchsenleiste justieren (rechter Winkel, alle Pins richtig).
* Die zweite Buchsenleiste einstecken.
* In beide Buchsenleisten die Stiftleiste aus dem Mikrocontroller-Modul-Set einstecken, so dass deren längerer Teil der Stiftleiste in der Buchsenleiste steckt.
* Das Mikrocontroller-Modul aufstecken, so dass das Display sichtbar ist und die Mikro-USB-Buchse über dem Piezo-Lautsprecher liegt.
* Alles mit einem schmalen Klebeband fixieren (siehe Bild unten), so dass alle Lötstellen zugänglich sind.
* Nun können alle Kontakte gelötet werden.

.. note:: Das OLED-Grafikdisplay ist über eine dünne Flex-Leitung angeschlossen, die nicht zu heiß werden darf.
   Im Zweifel lötet man die Pins in der Nähe der Flex-Leitung nicht an – sie werden nicht benötigt.

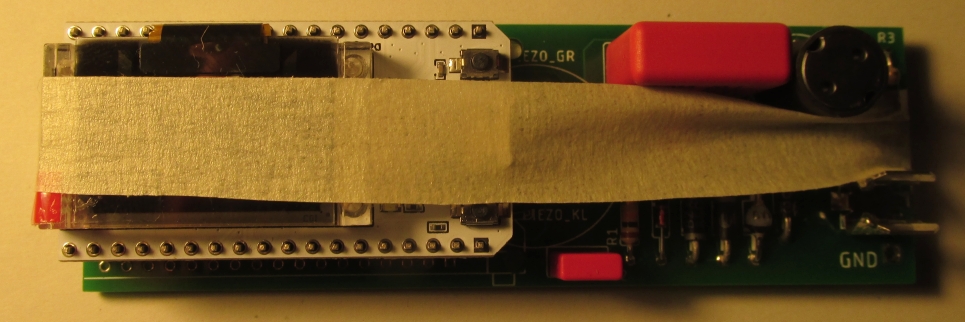
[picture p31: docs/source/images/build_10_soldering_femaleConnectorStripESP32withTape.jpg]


Nach dem Löten kann das Mikrocontroller-Modul mit wippenden Bewegungen vorsichtig abgezogen werden.

* Beim Mikrocontroller-Modul sind Pin-Beschriftungsaufkleber mit dabei.
  Diese können jetzt seitlich aufgeklebt werden.
  Welcher Pin wo ist, steht auf der Unterseite des Mikrocontroller-Moduls.
* Das Kabel für den Anschluss der Zählrohr-Kathode (Minus-Anschluss) an Klammer und Platine anlöten.
* Kabel mit jeweils einem Tropfen Heißkleber sichern (Zugentlastung).
* Sichtkontrolle (hast du Lötstellen vergessen, sind Lötbrücken entstanden, ...).
* Mikrocontroller-Modul wieder aufstecken.
* Zählrohr anklemmen: der Plus-Pol (Anode) ist markiert und muss in Richtung Platine zeigen.
* Eine erste Funktionskontrolle ist nun möglich, s. `Inbetriebnahme`_.

Fertige Geigerzähler- und Mikrocontrollerplatine:

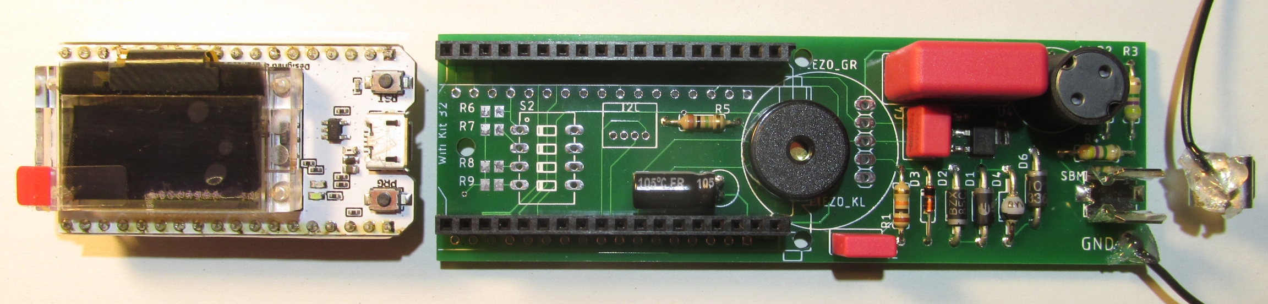
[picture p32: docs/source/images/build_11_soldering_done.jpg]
Fertige Geigerzähler- und Mikrocontrollerplatine


.. note:: Das dünne Glas des OLED-Grafikdisplays ist empfindlich.
          Bitte keine Kraft auf das Display ausüben, sondern nur auf die Mikrocontrollerplatine!

.. warning:: Verletzungsgefahr: Auf der Geigerzählerplatine wird eine **Spannung von 400 Volt** erzeugt.
   Diese hält sich auch noch längere Zeit **nach dem Ausschalten des Geräts**.
   Bei Berührung kann es zu kleineren Stromschlägen kommen, die normalerweise harmlos sind.
   Dennoch sollten sie vermieden werden!

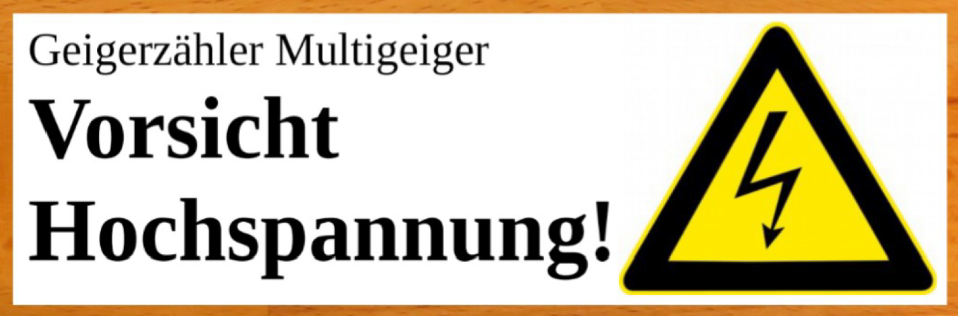
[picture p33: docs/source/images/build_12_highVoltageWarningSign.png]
   

   **Man sollte vor dem Arbeiten an der Schaltung den Kondensator entladen.**
   Am einfachsten macht man dies mit einer zweiten, ca. 30 cm langen Leitung, mit der man Anode und Kathode des Zählrohrs für etwa eine Sekunde kurzschließt.
   Dies schützt nicht nur vor unangenehmen Stromschlägen, sondern schützt auch die empfindliche elektronische Schaltung.

Optional: I2C Schnittstelle
---------------------------

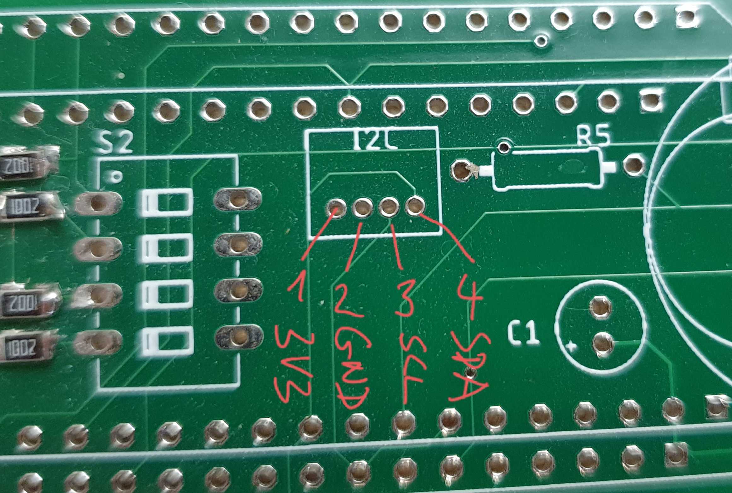
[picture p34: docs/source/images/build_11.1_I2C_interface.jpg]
Platinenausschnitt mit Beschriftung der I2C-Schnittstelle


Optional kann der MultiGeiger über die I2C-Schnittstelle mit zusätzlichen Sensoren ausgestattet werden.

.. table:: Belegung
   :widths: auto
   :align: center

   === ======== ===================
    #   Kürzel   Beschreibung
   === ======== ===================
    1   3V3      Spannung 3.3 Volt
    2   GND      Masse
    3   SCL      I2C clock
    4   SDA      I2C data
   === ======== ===================

Aktuell unterstützt werden

* `Bosch BME280 <https://www.bosch-sensortec.com/products/environmental-sensors/humidity-sensors-bme280/>`_: Temperatur (°C), relative Luftfeuchtigkeit (%), Luftdruck (Pa)
* `Bosch BME680 <https://www.bosch-sensortec.com/products/environmental-sensors/gas-sensors/bme680/>`_: Temperatur (°C), relative Luftfeuchtigkeit (%), Luftdruck (Pa), Indoor Air Quality (IAQ) Index (25 gut .. 500 schlecht)

Gehäuse
#######

Funktionen des Gehäuses
-----------------------

* Es schützt die Elektronik vor Umwelteinflüssen (z. B. Regen) und Insekten (daher sollte kein Zugang von außen zur Elektronik größer sein als 0,5 mm).
* Es hält das Zählrohr in einer Höhe von 1 m über der Wiese – somit sind unsere Messwerte (bestmöglich) vergleichbar zu denen des amtlichen `ODL-Messnetzes <https://odlinfo.bfs.de/DE/index.html>`_.

Rohre
-----

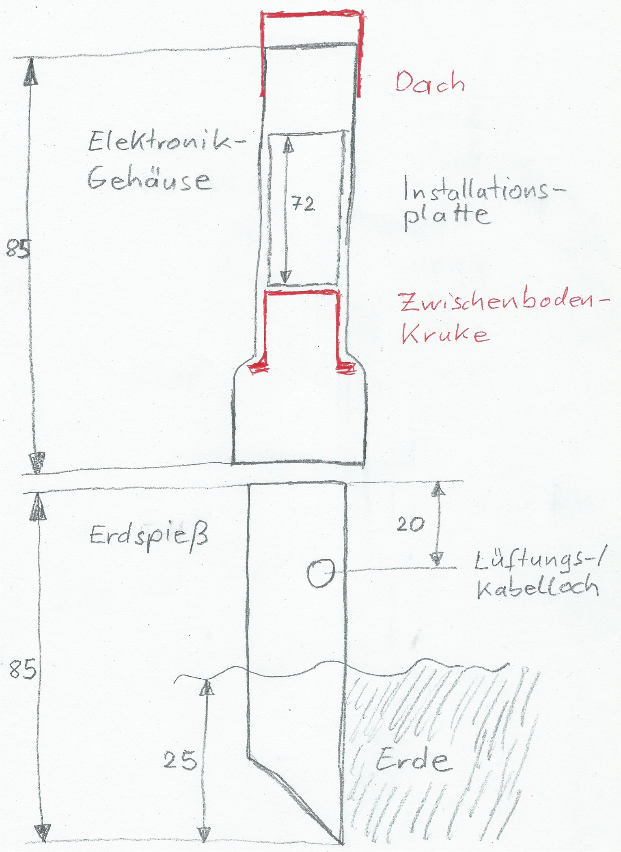
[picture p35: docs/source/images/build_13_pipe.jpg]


* Rohr für das Elektronikgehäuse: Zunächst wird das Rohr mit einer Säge auf entsprechende Länge abgesägt.
  Die Muffe (Aufweitung) zeigt nach unten.
* Rohr für den Erdspieß: Der noch umgesägte Teil des Restes ist das obere Ende des Erdspießes.
  Unten wird der Erdspieß auf entsprechende Länge abgesägt im 45-Grad-Winkel.
  Mit diesem schrägen Anschnitt lässt sich der Erdspieß später mit leichten Drehbewegungen gut in die Erde bohren.
  Alternativ kann man diesen Teil des Rohrs kurzhalten (ca. 15 cm) und in einem verzinkten Sonnenschirmhalter mit Erdspieß (Ø40mm) festklemmen.
* Lüftungs-/Kabelloch bohren: Mit einem Reißnagel o. ä. wird das Loch seitlich im Erdspieß vorgestochen.
  Anschließend wird es aufgebohrt. Zuletzt wird es mit einem großen Bohrer / Schälbohrer auf etwa 17 mm Durchmesser aufgebohrt.

.. note:: Verletzungsgefahr: Mit der Klinge/dem Bohrer immer nach außen, d. h. vom Körper weg, schneiden oder bohren!

Dach und Zwischenboden
----------------------

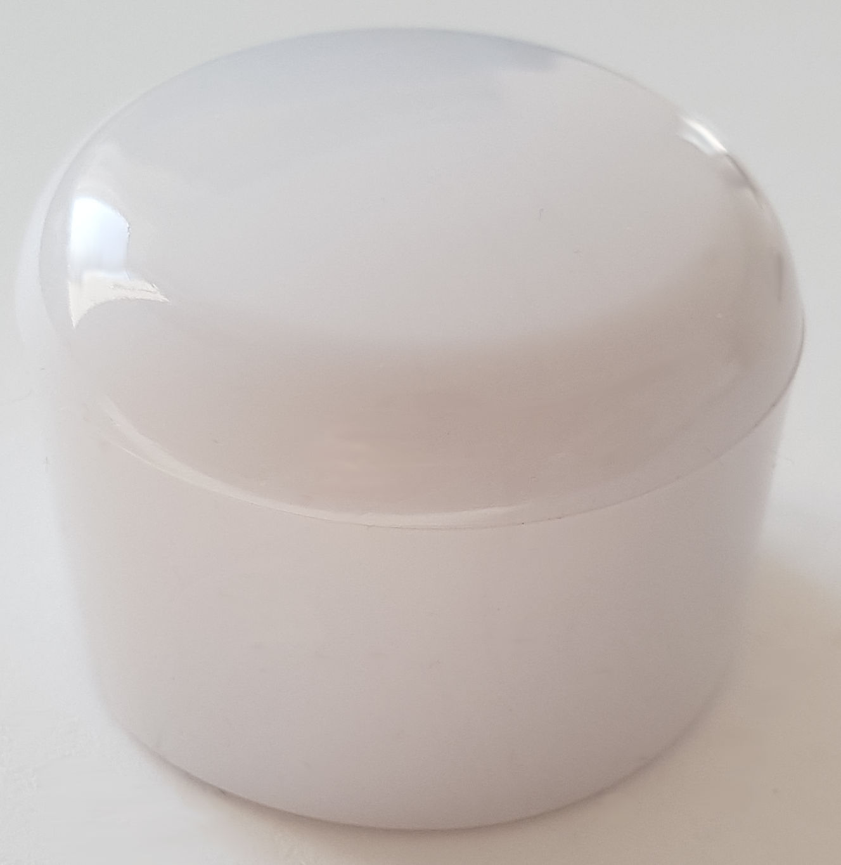
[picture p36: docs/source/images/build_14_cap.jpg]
Deckel


Für das Dach kann man einen Rohrabschlussstopfen oben vorsichtig über das Rohr schieben, s. Bild rechts.

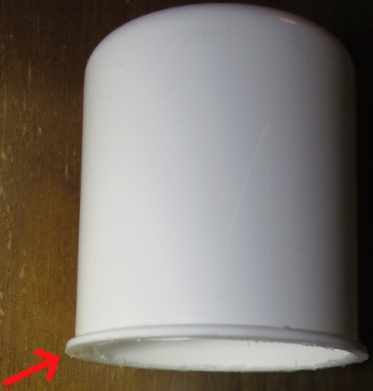
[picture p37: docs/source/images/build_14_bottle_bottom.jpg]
Zwischenboden


Als Zwischenboden verwenden wir eine Kruke, also eine Plastikdose, die in Apotheken zum Abfüllen von Salben verwendet wird.
Der rote Deckel kann als Material für eine kabeldurchführungsverkleinernde Zwischenbodenauflage dienen.

Für den Zwischenboden wird lediglich das Gewinde vorsichtig mit der Säge abgesägt, s. Bild links.
Der „Kragen“ muss bestehen bleiben, da er als Anschlag dient.

In den Zwischenboden wird in der Mitte ein Loch zur Kabeldurchführung mit 10 mm gebohrt.
Der Stecker des Kabels muss durch das Loch passen.

.. Auskommentiert, da die Variante mit Deckel viel einfacher ist
  Bei Verwendung einer Kruke als Dach wird der „Kragen“ unter dem Gewinde mit abgesägt, so dass die Dachkruke oben genau in das Rohr hineinpasst:

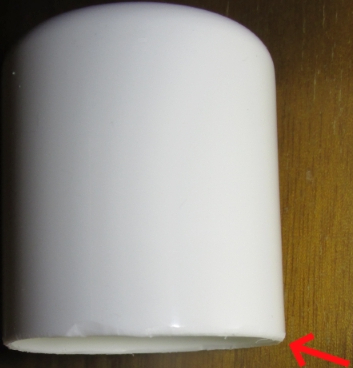
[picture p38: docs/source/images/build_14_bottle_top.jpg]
Deckel zum Einkleben
  

  Das obere Viertel der Dachkruke wird seitlich mit Silikonklebstoff benetzt und in das obere Teil des Elektronikgehäuses geschoben.
  Die Fuge wird weiterhin mit Silikonklebstoff abgedichtet.

  Auch der obere Rand der Dachkruke wird mit Klebstoff benetzt (s. Skizze).
  Um ein Hereinrutschen zu verhindern, kann man sie von unten mit einem langen Gegenstand fixieren.
  Die Silikonfuge kann man glätten, indem man einen Finger mit Spülmittel benetzt und damit das „Dach“ glättet.

.. Ab hier nicht mehr auskommentiert die Anleitung zur Auflage:

Eine Zwischenbodenauflage dient zum Schutz vor Insekten, da sie das Loch der Kabeldurchführung verkleinert.
Man kann dafür z. B. den roten Deckel der Kruke oder ein ähnliches Stück Kunststoff verwenden.

Es wird die Mitte markiert und dort ein Loch mit dem Durchmesser des Stromkabels (ca. 5 mm) gebohrt.
Anschließend werden die Ecken abgeschnitten.
Zusätzlich wird ein Verbindungsschlitz von außen zum Loch geschnitten.

Aufbau der Zwischenbodenauflage (in zwei Arbeitsschritten):

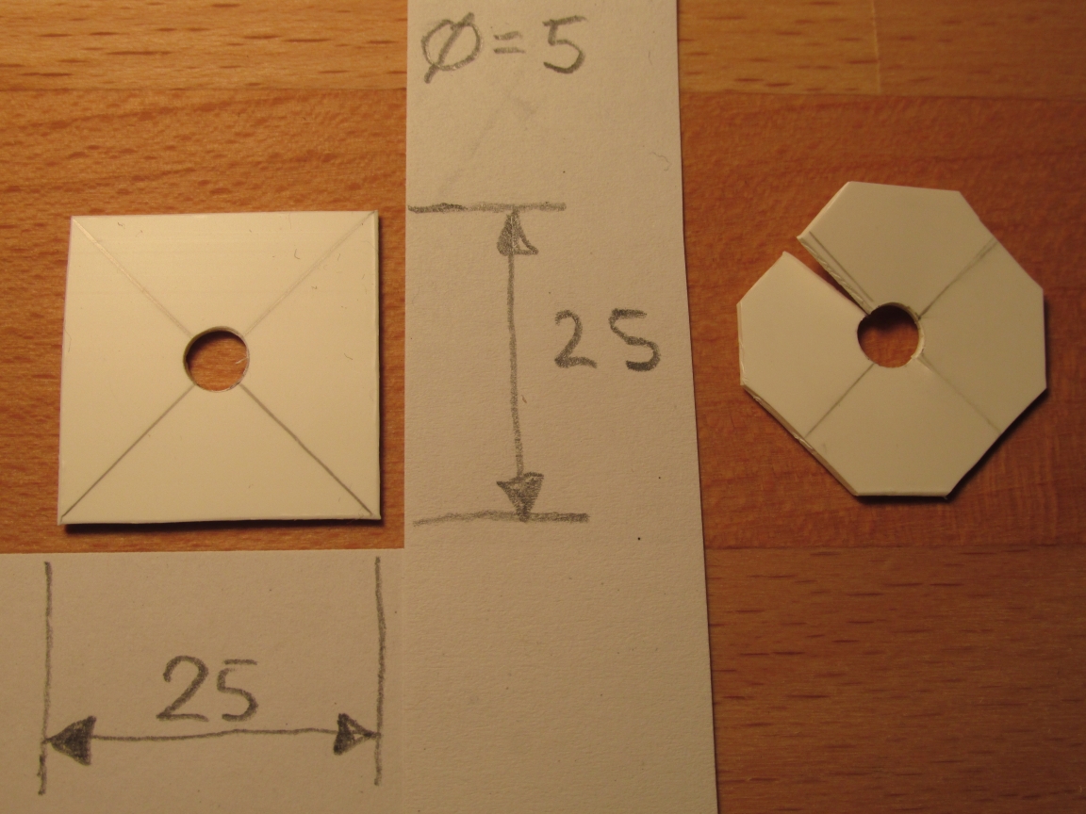
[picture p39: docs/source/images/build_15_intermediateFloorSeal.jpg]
Aufbau der Zwischenbodenauflage (in zwei Arbeitsschritten)


Installationsplatte
-------------------

* Die Installationsplatte kann aus dem Ober- oder Unterteil eines Kabelkanals gefertigt werden.
  Dazu werden die Seitenteile vorsichtig mit einem Messer abgeschnitten.
  Danach wird der dadurch entstandene, biegsame Kunststoffstreifen auf die richtige Länge gebracht.
  Hierzu kann eine starke Schere verwendet werden.
* Löcher durch Installationsplatte bohren: Elektronik und Zählrohr werden so mit Kabelbindern auf Installationsplatte fixiert, dass das Zählrohr sich auf 1 m Höhe befindet, wenn der Erdspieß 25 cm in der Erde steckt.
  Das Zählrohr zeigt nach unten.
  Die Löcher werden mit dem Reißnagel vorgestochen und dann auf 3 mm aufgebohrt, s. Bild „Bohrplan Installationsplatte“.
* Die Platine wird lediglich mit einem Kabelbinder auf der Platte montiert, der durch beide Löcher gezogen wird.
  Er verläuft unterhalb des USB-Steckers.

Bohrplan Installationsplatte:

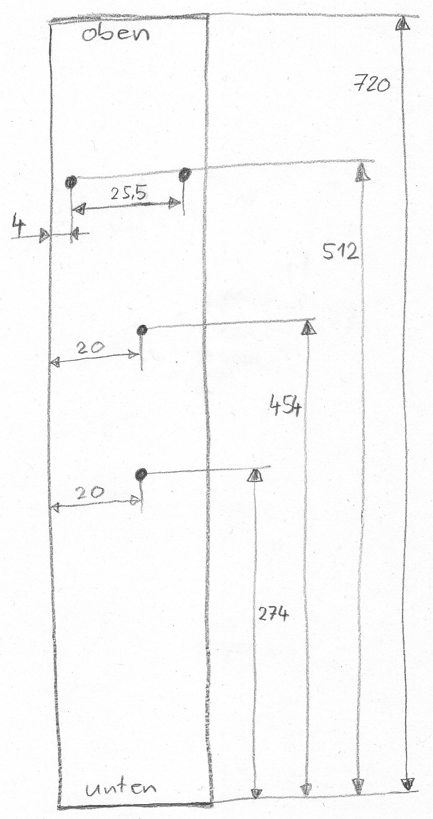
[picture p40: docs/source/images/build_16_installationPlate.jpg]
Bohrplan Installationsplatte


Einbau
------

Einbau des Geräts (die roten Pfeile markieren Kabelbinder):

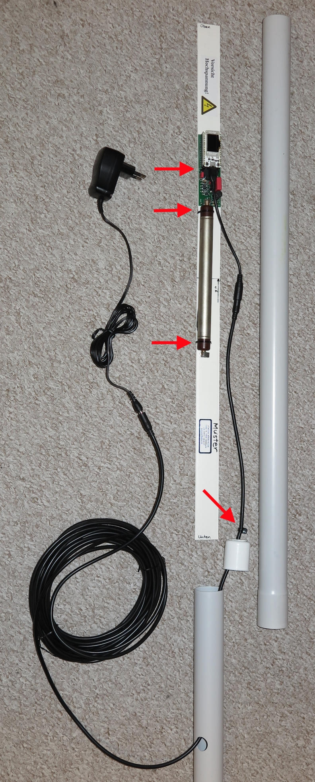
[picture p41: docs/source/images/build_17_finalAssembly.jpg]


* Platine und Zählrohr werden mit Kabelbinder auf die Installationsplatte montiert.
* In die Micro-USB-Buchse wird der passende Adapter gesteckt.
* Das „10 m Verlängerungskabel“ wird richtig herum zunächst durch den Erdspieß und dann durch den Zwischenboden gefädelt.
  Anschließend wird er mit dem Adapter verbunden.
* Danach wird die Zwischenbodenauflage oberhalb des Zwischenbodens vorsichtig auf das Kabel geschoben.
* Oberhalb der Zwischenbodenauflage wird ein Kabelbinder auf das Kabel gezurrt, so dass eine Zugentlastung entsteht.
* Erster Test des Gehäuses: Wir schieben erst vorsichtig die Installationsplatte in das Elektronikgehäuse.
  Anschließend folgen Zwischenboden und der Erdspieß.
* Wenn alles passt wird noch die Zwischenbodenauflage mit Silikon-Kleber auf den Zwischenboden geklebt und mit Kreppband (bis zum Aushärten) fixiert.
* Der Warn-Aufkleber „Vorsicht Hochspannung“ wird auf die Installationsplatte geklebt.

Inbetriebnahme
##############
WLAN-Variante: Das Gerät baut einen eigenen WLAN-Accesspoint (AP) auf.
Die SSID des AP lautet ESP32-xxxxxxxx, wobei die xxx die Chip-ID des WLAN-Chips sind (Beispiel: ESP32-51564452).
Bitte diese Nummer notieren, sie wird später für die Anmeldung benötigt, z. B. bei https://devices.sensor.community/.
Der Access-Point bleibt für 30 s aktiv. Danach versucht das Gerät, sich mit dem (früher) eingestellten WLAN zu verbinden.
Dieser Verbindungsversuch dauert ebenfalls 30 s. Kommt keine Verbindung zustande, wird wieder der eigene AP für erzeugt.
Das standardmäßig vergebene WLAN-Kennwort ist „*ESP32Geiger*“ und sollte zeitnah geändert werden.

Weitere Informationen: :ref:`deployment` und :ref:`usage`.

**Wir wünschen viel Freude mit dem neu gebauten Gerät und hoffen dass es niemals unnatürliche bzw. gesundheitsschädliche Ausschläge messen wird!**

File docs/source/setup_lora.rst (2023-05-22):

.. include:: global.rst.inc
.. _setup_lora:

Setup (LoRA)
------------

The MultiGeiger can be connected with the followng steps to TTN_V3 (“The
Things Network”):

-  Create the TTN device in your profile at *The Things Network*
-  Transfer the parameters to the MultiGeiger
-  Login at *sensor.community*
-  Webhook integration

Creating a TTN device
~~~~~~~~~~~~~~~~~~~~~

The device must be registered with TTN. To do this, an account must
first be created at TTN (if one does not already exist).

Create TTN account
^^^^^^^^^^^^^^^^^^

At https://account.thethingsnetwork.org/register you must enter a
**USERNAME**, the **EMAIL ADDRESS** and a **PASSWORD**. Then click on
**Create account**.  After that you can log in to
the console with the new data at
https://account.thethingsnetwork.org/users/login.

Create application
^^^^^^^^^^^^^^^^^^

After logging in click on your name (upper right corner) and select **Console**.
On the next screen select **Europe 1** and click on **Continue as <your name>**. Then select **Applications** from the top menue, 
after that click on **+ Add application** (right blue button).

The following fields must be
filled in:

**Owner:**
  This is prefilled with your login name and need not to be changed.
**Application ID:**
   Any name for this application, but it must not yet exist in the
   network (e.g.: geiger_20220105).
**Application name**  
  Choose an arbitrary name for your application.
**Description:**
   Any description of the application can be entered here.

Now create the application by clicking the **Create application** button.

Create device
^^^^^^^^^^^^^

On the next page you can now create a new device.  Press the button **+ Add end device**.
Now select **Manually** from the menue directly under **Register end device**.
Then the following fieds must be filled in:

**Frequency plan**
  Select **Europe 863-870 MHz (SF9) for RX2 - recommended)**.
**LoRaWan version**
  Select **MAC V1.02**.
**Regional Parameters version**
  Select **PHY V1.0.2 REV B**.

For each of the next three entries select **Generate** or **Fill with zeros**. Please write down these three values, 
you will need them later on.

The last field (**End device ID**) will be filled in automatically.
Now press **Register end device**.

Enter the LoRa parameters into the MultiGeiger
~~~~~~~~~~~~~~~~~~~~~~~~~~~~~~~~~~~~~~~~~~~~~~

-  After the registration was completed, the LoRa parameters need to be entered into the form on the MultiGeiger configuration
   page (see above).
-  Now go through the configuration on the configuration page until the settings of the LoRa  parameters are displayed
   and enter them here. Type in the 3 parameters from the TTN console (**APPEUI, DEVEUI, APPKEY**). 
   
   Enter the HEX values  **without** spaces as they appear in the TTN. Example:

The TTN console reads

::

   Device EUI    00 D0 C0 00 C3 19 7C E8

Then the following must be entered:

::

   00D0C000C3197CE8

This is also applies to **APPEUI** and **APPKEY**.
After entering these parameters, please restart the Multigeiger.

Logging data to sensor.community
~~~~~~~~~~~~~~~~~~~~~~~~~~~~~~~~
If you want to transfer the data from Multigeiger to sensor.community, you have to 
register at sensor.community. The registration process is similar to the description 
above ("Login to sensor.community").  In the following, only the changes are
explained:

**Sensor ID:**
   Enter the last 4 bytes of the DEVEUI in left to right order (e.g. if
   the DEVEUI is *00 D0 C0 00 C3 19 7C E8*, so enter *C3197CE8*), but
   converted to decimal, not in HEX (finally: 3273227496).
**Sensor Board:**
   Select **TTN**, to select use the small arrow on the right.

Webhook integration
~~~~~~~~~~~~~~~~~~~~

To get the data via TTN to *sensor.community*, the Webhook integration at TTN has to be activated.

At the Application tab select **Integrations** from the left menue. Select **Webhooks**, then **+ Add webhook**. 
Scroll down and select **Custom webhook**.

Fill in the following fields:

**Webhook ID**
  Enter an arbitrary name for this hook
**Webhook format**
  Select **JSON**
**Base URL**
  Enter **https://ttn2luft.citysensor.de**
**Downlink API key**
  This remains empty

Then click at **+ Add header entry** to add a special Header. Enter **X-SID** in the left field and your 
sensor id (the number, you received from sensor.community, **not** the chip ID) in the right field.
Enable **Uplink message**, all other selections remain disabled. Now click **Add webhook** (or **save changes**).

TTN payload (example)
~~~~~~~~~~~~~~~~~~~~~

In order to get readable values in the TTN console instead of solely data bytes, a small script can be inserted as payload decoder.
Go to the TTN website, log in, click **Applications** to find the application you created above. 
From the left menu select **Payload formatters** and then **Uplink**.

At **Formatter type** select **Javascript** and in **Formatter paramater** paste following code (replace existing code):

::

  function decodeUplink(input) {
    var data = {};
    if(input.fPort === 1) {
      var minor = ((input.bytes[7] & 0xF) << 4) + (input.bytes[8] >> 4) ;
      data.counts = ((input.bytes[0] * 256 + input.bytes[1]) * 256 + input.bytes[2]) * 256 + input.bytes[3];
      data.sample_time = (input.bytes[4] * 256 + input.bytes[5]) * 256 + input.bytes[6];
      data.tube = input.bytes[9];
      data.sw_version = "" + (input.bytes[7] >>4 ) + "." + minor + "." + (input.bytes[8] & 0xF);
    }
    if(input.fPort === 2) {
      var t = input.bytes[0] * 256 + input.bytes[1];
      if (input.bytes[0] & 0x80) {
        t |= 0xFFFF0000;
      }
      data.temp = t / 10 + "°C";
      data.humidity = input.bytes[2] / 2 + "%";
      data.press = ((input.bytes[3] * 256 + input.bytes[4]) / 10 ) + "hPa";
    }
    return  {
      data: data,
      warnings: [],
      error: []
    };
  }

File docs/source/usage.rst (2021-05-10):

.. include:: global.rst.inc
.. highlight:: none
.. _usage:

Usage
=====

OLED display
############

Top line
--------

Left: Time since power-on (not shown on small displays).

Right: Overall average radiation since power-on.

Middle area
-----------

Current CPM (counts per minute) displayed using a rather big font.

Bottom line
-----------

This is a status display with 8 positions, numbered 0..7:

Rules of thumb:

- ``.`` usually means "off" or "unused".
- if you see some *number* (``0`` .. ``7``) within the status display line, something went wrong.

Positions:

- 0: WiFi

  - ``A``: AccessPoint active
  - ``w``: WiFi client trying to connect
  - ``W``: WiFi client connected
  - ``0``: some error happened
- 1: sensor.community transmission

  - ``.``: off (not configured, not enabled)
  - ``?``: init (enabled, before 1st transmission)
  - ``S``: sending
  - ``s``: idle (shown after successful sending)
  - ``1``: sending failed (shown after trying to send)
- 2: madavi transmission

  - ``.``: off (not configured, not enabled)
  - ``?``: init (enabled, before 1st transmission)
  - ``M``: sending
  - ``m``: idle (shown after successful sending)
  - ``2``: sending failed (shown after trying to send)
- 3: TTN ("The Things Network")

  - ``.``: off (not configured, not enabled, no LoRa hardware)
  - ``?``: init (enabled, before 1st transmission)
  - ``T``: sending
  - ``t``: idle (shown after successful sending)
  - ``3``: sending failed (shown after trying to send)
- 4: BLE (Bluetooth® Low Energy)

  - ``.``: off (not enabled)
  - ``?``: init (enabled, before setup of BLE service)
  - ``B``: connected and sending notifications, if requested by connected device
  - ``b``: connectable (advertising and ready to connect)
  - ``4``: BLE error
- 5: unused
- 6: unused
- 7: High-Voltage Capacitor charging

  - ``H``: OK
  - ``7``: failure to charge HV capacitor

ESP32 buttons
#############

The MultiGeiger ESP32 microcontroller board has 2 buttons:

- RST: reset (restarts device)
- PRG: program (press and hold PRG, press RST momentarily, upload firmware)

Often, using PRG is not needed for flashing firmware, because it "just works" when using the right tools.

DIP Switches
############

Optionally, the MultiGeiger can be equipped with a 4-contact DIP switch under the ESP32 microcontroller board.

The firmware makes use of these 4 switches as defined in the ``Switches`` data type in ``switches.h``:

- SW0: Speaker on
- SW1: Display on
- SW2: LED on
- SW3: BLE on

BLE - Bluetooth® Low Energy
###########################

BLE Heart Rate Service
----------------------

The MultiGeiger provides a Bluetooth® Low Energy (BLE) service to allow the collection of the Geiger-Mueller count rate via a `GATT Heart Rate Service <https://www.bluetooth.com/specifications/gatt/services/>`_ (Service UUID 0x180D). The following characteristics are used:

- 0x2A37 ('Heart Rate Measurement Characteristic'):

  - The first byte is a collection of status flags, according to the service's standard
  - 'Heart Rate Measurement' as 16 bit value (little endian), corresponds to Geiger-Mueller counts per minute (CPM)
  - 'Energy Expenditure' as 16 bit value (little endian), represents a rolling packet counter
- 0x2A38 ('Heart Rate Sensor Position Characteristic')

  - 'Sensor Position' as 8 bit value, corresponds to TUBE-TYPE, allowing the conversion of CPM to radiation rate
- 0x2A39 ('Heart Rate Control Point Characteristic')

  - Write characteristic, required by service's standard to reset Energy Expenditure to 0. Writing 0x01 resets the rolling packet counter to 0.

Testing BLE
-----------

Any decent Bluetooth® scanning app should be able to connect to the device and show the notification values.

The `MultiGeiger companion app <https://github.com/t-pi/multigeiger_companion>`_ was specifically made for the MultiGeiger.

There are also some generic apps:

- `nordic® nRF Connect app <https://www.nordicsemi.com/Software-and-Tools/Development-Tools/nRF-Connect-for-mobile>`_
- `HRM heart rate monitor app <https://f-droid.org/de/packages/st.wow.git.hrm/>`_

Any other heart monitor app / device should be able to connect to the MultiGeiger, too.

- Figure 1: Connect to the MultiGeiger with the name 'ESP32-<id>', where <id> should be the same ID (7 to 8 digits) as with the access point to set the device up initially.

- Figure 2: Find the correct service (UUID 0x180D) and, if needed, load / open characteristics.

- Figure 3: Find the Heart Rate Measurement Characteristic (UUID 0x2A37) and click on the icon to start notifications.

While testing, please keep in mind that an update packet is sent only every ~10s (along with a display refresh, if enabled). If a WiFi transmission is blocking display and BLE updates, the interval may be even longer. So it might take a while until a reaction with actual data can be seen in the app.





+----------+----------+----------+
| *Fig. 1* | *Fig. 2* | *Fig. 3* |
|          |          |          |
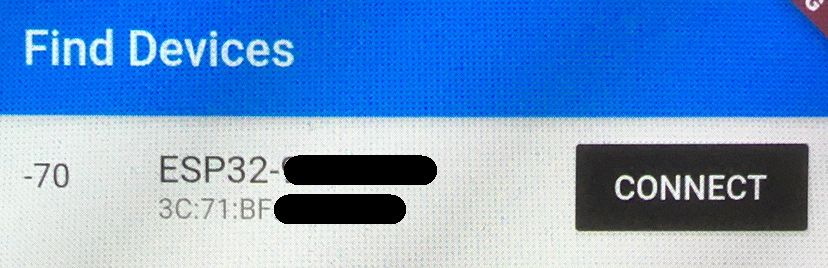
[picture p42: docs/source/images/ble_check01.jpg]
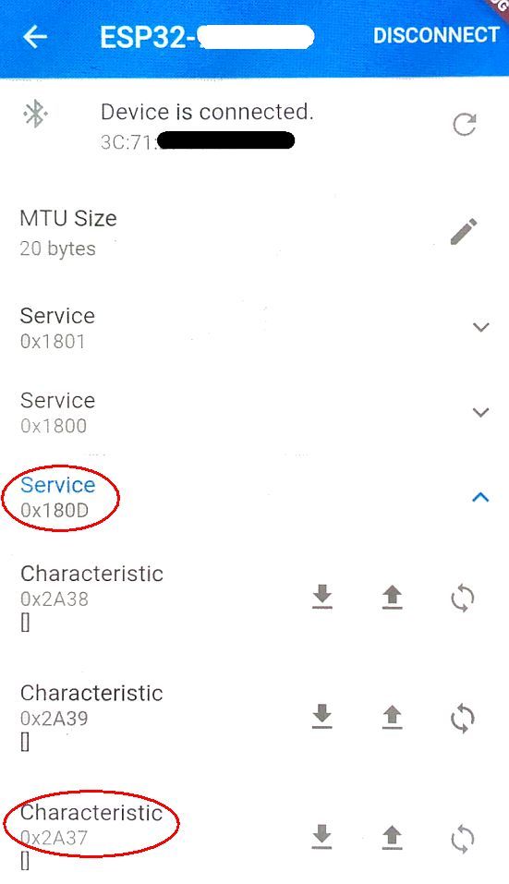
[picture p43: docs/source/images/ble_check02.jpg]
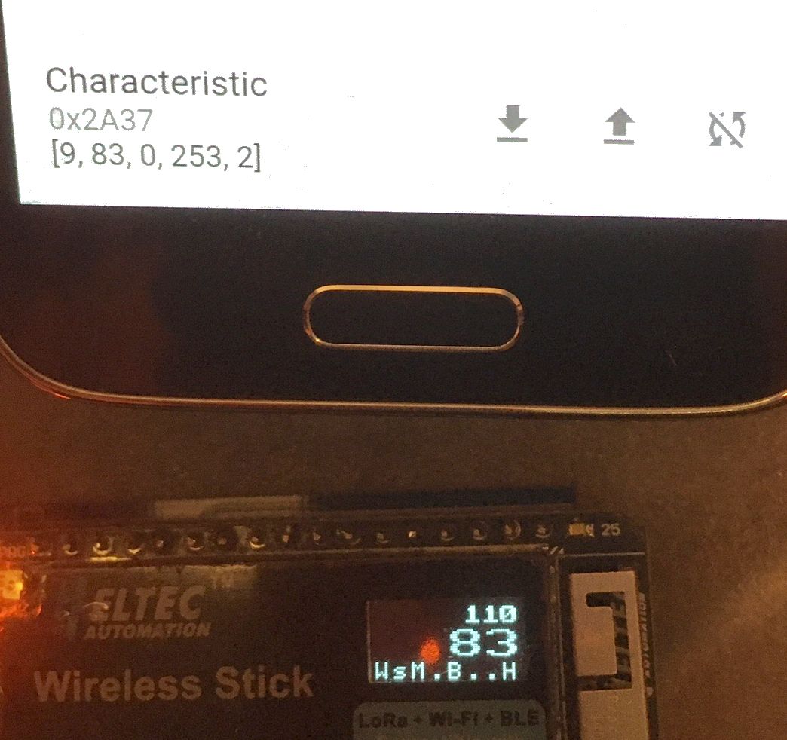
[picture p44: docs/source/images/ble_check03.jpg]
|    |    |    |
+----------+----------+----------+

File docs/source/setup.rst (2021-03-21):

Setup
-----

Download and unpack the latest release from GitHub (
https://github.com/ecocurious/MultiGeiger/releases ) as source code
(zip) or source code (tar.gz). In the new directory, open the directory
*multigeiger* and load the file *multigeiger.ino* with the Arduino IDE.

The board supports two different Heltec devices, different counting
tubes and optionally a sensor for ambient temperature, air pressure, and
humidity (BME280 or BME680). The software can send data via network to
different services.

-  **Heltec WiFi Kit 32** This MCU has WiFi, a large display and plugged
   into the longer female connectors on the board.

-  **Heltec Wireless Stick** This MCU has a very small display, and
   provides LoRa beside WiFi. It must be plugged into the shorter female
   headers on the board.

To select the Heltec boards in the Arduino IDE, the following steps must
be taken: 

-  Add the file: https://raw.githubusercontent.com/espressif/arduino-esp32/gh-pages/package_esp32_dev_index.json in Preferences->Additional Boards Manager URLs. 
-  Then, the ESP32 boards (name “esp32 by Espressif Systems”) can be installed under Tools->Board->Boards Manager. Choose the correct Heltec board under Tools->Board.  
-  Select the **Heltec wireless Stick** for **both** boards. 
-  If you use arduino-esp32 >= 1.0.5, you might need to apply a patch to get back the "partition scheme" menu
   needed in the next step, see the ``misc/arduino-esp32/paritition-menu-*.*`` files in our git repo.
-  Select under Tools **Flash size: “4MB(32Mb)”** and **Partition Scheme: “Minimal SPIFFS (Large APPS with OTA)”**. The software recognizes automatically which board is equipped.

Various software settings can be made via the following files (see
comments inside):

-  **./multigeiger/userdefines.h** (always necessary, an example is
   provided in userdefines-example.h)
-  **./platformio.ini** (only for platformio, an example is provided in
   platformio-example.ini)

All external libraries are required, which are listed in the file

::

   platformio-example.ini

under the section

::

   lib-deps =

Please install the latest version via platform.io / Libraries.

**Caution:** If the Arduino IDE is used, please check that in the file project_config/lmic_project_config.h (in the top level in this library) the correct configurations are set. The file must look like this:

::

   // project-specific definitions
   #define CFG_eu868 1
   //#define CFG_us915 1
   //#define CFG_au921 1
   //#define CFG_as923 1
   // #define LMIC_COUNTRY_CODE LMIC_COUNTRY_CODE_JP /* for as923-JP */
   //#define CFG_in866 1
   #define CFG_sx1276_radio 1
   //#define LMIC_USE_INTERRUPTS

The specified versions of the libraries are the minimum requirements. We
always test with the latest versions too, so please always install and
use the latest versions. If the compiler reminds other libraries, please
install them in the Arduino IDE via *Sketch -> Include Library -> Manage
Libraries ..*.

Procedure after startup
#######################

The device establishes its own WiFi access point (AP). The SSID of the AP is **ESP32-xxxxxx**, where the xxx are the chip ID (or MAC address) of the WiFi chip (example: **ESP32-51564452**). **Please write down this number, it will be needed later.** 
This access point remains active for 30 sec. After that the device tries to connect to the (previously) defined WiFi netwword. 
This connection attempt also takes 30sec. If no connection could be established, the own AP is created again and the process starts again and again.

Configuring the device via WiFi
###############################

After the WiFi AP of the device appears on your cell phone or computer, connect to it. The connection asks for a password, it is **ESP32Geiger**. 
The start page of the device opens usually **automatically**.
If the start page does not appear, you have to call the address **192.168.4.1** with a browser. The start page appears, where you can’t miss the link to the **configure page** , click on it and you enter the settings page.

The settings page has the following lines: 

-  Geiger accesspoint SSID
   This is the SSID of the built-in AP and can be changed. If the sensor was already registered with this number at sensor.community, a new registration is mandatory.
-  Geiger accesspoint password
   This is the password for the built-in AP. It **MUST** be changed the first time. If desired, the default password **ESP32Geiger** can be used again. The field must not be left blank. Save the password to your favourite password manager.
-  WiFi client SSID
   Here you have to enter the SSID of the WLAN you want to connect for network/internet access. 
-  WiFi client password And here the corresponding password.

For more security, it is recommended to use a separate WiFi network (e.g. guest network) to ensure an isolated communication from the normal network.

If everything is entered, press **Apply** and the data are stored in the internal EEPROM. Leave this page via **Cancel**, because only in this way the program closes the Config-Mode and connects to the local WiFi network.
If there is no **Cancel** Button, go back to the WiFi settings
of the device and type in the normal home network parameters again.

**CAUTION**. **When updating to version 1.13, the WiFi settings must be
re-entered**. In future versions this step shall become obsolete.

Furthermore, the following options can be defined on the settings page:

-  Start melody, speaker tick, LED tick and display on/off.
-  Send data to sensor.community or/and to madavi.de
-  If LoRa hardware is available: the LoRa parameters (DEVEUI, APPEUI
   and APPKEY) can be entered here.

The firmware on the MultiGeiger can be updated with the link **Firmware update** at the End of the settings page. Download the .bin file, select it via **Browse…** and click **Update**. It will take roughly 30sec for uploading and flashing the firmware. If you see **Update Success! Rebooting…**, the MultiGeiger will reboot and the new firmware will be active.

If **Update error: …** appears, the update did not work. The previous firmware is still active.

The settings page can be called up from your own WiFi at any time. To do this, just enter in the address bar of the browser: http://esp32-xxxxxxx (xxxxx is the chip ID – see above). 
If it does not work with this hostname, use the IP address of the Geiger counter instead. The Ip address can be found in the devices list in your router.
If successful, the login page appears. 
Enter **admin** as username and the chosen password (see above). Now you will see the settings page as described.

Server for measured data
########################

The pulses are counted for one measuring cycle at a time, from which the “counts per minute” (cpm) are calculated. After each cycle the data is sent to the servers at *sensor.community* and at *madavi.de*.

At *sensor.community* the data is stored and made available for retrieval the next day as CSV file.
This file can be found at http://archive.sensor.community/DATE/DATE_radiation_si22g_sensor_SID.csv), where DATE = date in format YYYY-MM-DD (both times equal) and SID is the sensor number of the sensor (**not** the ChipID). For other sensors, replace the counting tube name **si22g** with the corresponding name (e.g.: sbm-20 or sbm-19).

At *madavi* the data is stored in a RRD database and can be accessed directly as a graph via this link: https://www.madavi.de/sensor/graph.php?sensor=esp32-CHIPID-si22g.
Here CHIPID is the ChipId (the digits of the SSID of the internal access point).

During the transmission of the data to the servers, the name of the server is briefly shown in the status line (bottom line) of the display.

Login to sensor.community
#########################

In order to send the measuered data to sensor.community, it is mandatory to have a valid account and the sensor is registered. Both can be done at https://devices.sensor.community. Create an account if you do not have one via the *Register* button and log in. To register a new sensor click *Register new sensor*. Fill in the form: 

-  Sensor
   ID: Enter the number (only the numbers) of the SSID of the sensor (e.g. for the sensor ESP-51564452 enter 51564452).
-  Sensor Board: Select *esp32* (by the small arrows on the right)
-  Basic information:
   Enter the address and the country. The internal name of the sensor can be assigned arbitrarily, but must be entered. Please check **Indoor sensor** as long as the sensor operates not outdoor.
-  Additional information:
   Can be left blank, but its nice to provide further information. 
-  Hardware configuration:
   Select the sensor type **Radiation Si22G** (or accordingly). The value for the second sensor can remain DHT22, as it is irrelevant in this context.
-  Position:
   Please enter the coordinates as accurate as possible. You can use the right button to calculate the coordinates. They are needed to show your sensor on the map.

Finish the settings by clicking *Save settings*. At the overview page for this sensor go to *Data*. Here you see amongst others the ID of the sensor. Please remember: the ID mandatory for the queries at
sensor.community or multigeiger.citysensor.de.

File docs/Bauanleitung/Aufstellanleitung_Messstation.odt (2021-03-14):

Aufstellung der

Multigeiger-Messstation

Dies ist nicht die aktuellste Version dieser Anleitung.
Die aktuellste Version findet sich auf: https://multigeiger.readthedocs.io/

Jürgen Böhringer, 2020-01- (https://multigeiger.readthedocs.io/)25 (https://multigeiger.readthedocs.io/)

(https://multigeiger.readthedocs.io/)

Bei der Aufstellung der (https://multigeiger.readthedocs.io/)Multigeiger-Messtation (https://multigeiger.readthedocs.io/)sind einige Punkte zu beachten. (https://multigeiger.readthedocs.io/)Natürlich wird es, bei uns Privatleuten, selten einen 100 %ig perfekten Aufstellort geben. Dennoch sollten wir uns bewusst sein welche Parameter (https://multigeiger.readthedocs.io/)negative Einflüsse haben können. (https://multigeiger.readthedocs.io/)

(https://multigeiger.readthedocs.io/)

(https://multigeiger.readthedocs.io/)

(https://multigeiger.readthedocs.io/)

Versorgung mit WLAN und Strom (https://multigeiger.readthedocs.io/)


(https://multigeiger.readthedocs.io/)

Auf jeden Fall brauchen wir am Aufstellort: (https://multigeiger.readthedocs.io/)

- WLAN-Versorgung: (https://multigeiger.readthedocs.io/)z. B. (https://multigeiger.readthedocs.io/) aus dem Haus heraus (https://multigeiger.readthedocs.io/)(Fritzbox o. ä.) (https://multigeiger.readthedocs.io/). (https://multigeiger.readthedocs.io/)Aus Sicherheitsgründen sollte man den Multigeiger in das s. g. „Gastnetz“ hängen. Dies kann in der Fritzbox eingeschaltet werden (https://multigeiger.readthedocs.io/) (https://multigeiger.readthedocs.io/)=========================> (https://multigeiger.readthedocs.io/)

(https://multigeiger.readthedocs.io/)

(https://multigeiger.readthedocs.io/)

(https://multigeiger.readthedocs.io/)

(https://multigeiger.readthedocs.io/)

(https://multigeiger.readthedocs.io/)

(https://multigeiger.readthedocs.io/)

(https://multigeiger.readthedocs.io/)

(https://multigeiger.readthedocs.io/)

(https://multigeiger.readthedocs.io/)

- Stromversorgung: 5 V / (https://multigeiger.readthedocs.io/)ca. (https://multigeiger.readthedocs.io/)100 mA, (https://multigeiger.readthedocs.io/)z. B. (https://multigeiger.readthedocs.io/) (https://multigeiger.readthedocs.io/)aus dem Haus durch (https://multigeiger.readthedocs.io/)5 V-Leitung (https://multigeiger.readthedocs.io/)=========================> (https://multigeiger.readthedocs.io/)

(https://multigeiger.readthedocs.io/)

(https://multigeiger.readthedocs.io/)

(https://multigeiger.readthedocs.io/)

(https://multigeiger.readthedocs.io/)

- Abregnenfläche: z. B. (https://multigeiger.readthedocs.io/)Rasen, Wiese o. ä. (https://multigeiger.readthedocs.io/)=========================> (https://multigeiger.readthedocs.io/) (https://multigeiger.readthedocs.io/)

Wahl des Aufstellungsorts (https://multigeiger.readthedocs.io/)

(https://multigeiger.readthedocs.io/)

Was wir mit unserem Gerät nachweisen wollen sind radioaktive (https://multigeiger.readthedocs.io/)Stoffe (Stäube) (https://multigeiger.readthedocs.io/), die man auch "Fallout" nennt. Sie entstehen (https://multigeiger.readthedocs.io/)z. B. (https://multigeiger.readthedocs.io/)bei Atombomben-Explosionen und Reaktor-Katastrophen. (https://multigeiger.readthedocs.io/)

(https://multigeiger.readthedocs.io/)

In sehr schwacher Form entstehen sie natürlicherweise auch in der Atmosphäre auch durch den (https://multigeiger.readthedocs.io/)Zerfall (https://multigeiger.readthedocs.io/) des radioaktiven Edelgases Radon. Auch dieser "Radon-Fallout" erzeugt bei unseren Geräten einen kleinen, (https://multigeiger.readthedocs.io/)aber messbaren, Ausschlag (https://multigeiger.readthedocs.io/), der sich (https://multigeiger.readthedocs.io/)in etwa (https://multigeiger.readthedocs.io/) mit einer Halbwertszeit von (https://multigeiger.readthedocs.io/)45 (https://multigeiger.readthedocs.io/) Minuten wieder abbaut. Anhand diese (https://multigeiger.readthedocs.io/)r (https://multigeiger.readthedocs.io/) (https://multigeiger.readthedocs.io/)s. g. (https://multigeiger.readthedocs.io/)„Radon-Peaks“ können wir sehen (https://multigeiger.readthedocs.io/)ob (https://multigeiger.readthedocs.io/) unser Gerät gut aufgestellt ist und auch für „ (https://multigeiger.readthedocs.io/)echten“ (https://multigeiger.readthedocs.io/) Fallout empfindlich ist. (https://multigeiger.readthedocs.io/)

(https://multigeiger.readthedocs.io/)

(https://multigeiger.readthedocs.io/)

Abregenfläche (https://multigeiger.readthedocs.io/)

Wir (https://multigeiger.readthedocs.io/)brauchen in direkter Umgebung der Messtation eine (https://multigeiger.readthedocs.io/)größere (https://multigeiger.readthedocs.io/) Fläche auf die (https://multigeiger.readthedocs.io/)es (https://multigeiger.readthedocs.io/)abregnen kann. Diese Fläche sollte auch die Möglichkeit haben radioaktive Partikel (https://multigeiger.readthedocs.io/)fest (https://multigeiger.readthedocs.io/)zuhalten. Rasen oder Wiese (https://multigeiger.readthedocs.io/)ist hierfür perfekt (https://multigeiger.readthedocs.io/). (https://multigeiger.readthedocs.io/)Eine (https://multigeiger.readthedocs.io/)Asphaltfläche (https://multigeiger.readthedocs.io/)dagegen kann dies nicht (https://multigeiger.readthedocs.io/), da die Partikel direkt nach dem Abregnen (https://multigeiger.readthedocs.io/)sofort abgespült (https://multigeiger.readthedocs.io/) werden. (https://multigeiger.readthedocs.io/)

(https://multigeiger.readthedocs.io/)

(https://multigeiger.readthedocs.io/)

Windrichtung (https://multigeiger.readthedocs.io/)

Das Gelände sollte von der Hauptwindrichtung her unverbaut sein. Auch Büsche/Bäume sollten sich dort keine befinden. (https://multigeiger.readthedocs.io/)

(https://multigeiger.readthedocs.io/)

(https://multigeiger.readthedocs.io/)

Sonnenlicht (https://multigeiger.readthedocs.io/)

Sowohl das 5 V-Kabel, als auch das Gerät selbst, sollten sich (https://multigeiger.readthedocs.io/)möglichst (https://multigeiger.readthedocs.io/)die meiste Zeit des Tages (https://multigeiger.readthedocs.io/)im Schatten befinden. (https://multigeiger.readthedocs.io/)Denn d (https://multigeiger.readthedocs.io/)irektes Sonnenlicht (https://multigeiger.readthedocs.io/)kann gleich (https://multigeiger.readthedocs.io/)zweierlei negative Auswirkungen haben: (https://multigeiger.readthedocs.io/)

- Erwärmung des Geräts: (https://multigeiger.readthedocs.io/)Die Temperatur im Gerät kann in der Sonne auf bis zu 60 (https://multigeiger.readthedocs.io/)° (https://multigeiger.readthedocs.io/)C ansteigen (bei 45 (https://multigeiger.readthedocs.io/)° (https://multigeiger.readthedocs.io/)C im Schatten) warm werden. Zwar haben unsere Temperaturtests gezeigt dass das Gerät bei 70 (https://multigeiger.readthedocs.io/)° (https://multigeiger.readthedocs.io/)C noch einwandfrei funktioniert. Jedoch ist das Zählrohr nur bis 50 (https://multigeiger.readthedocs.io/)° (https://multigeiger.readthedocs.io/)C spezifiziert. (https://multigeiger.readthedocs.io/)
- Schädigung des (https://multigeiger.readthedocs.io/)Kabels und des (https://multigeiger.readthedocs.io/)Gehäuses durch UV-Strahlung: Direktes (https://multigeiger.readthedocs.io/)S (https://multigeiger.readthedocs.io/)onnenlich (https://multigeiger.readthedocs.io/)t (https://multigeiger.readthedocs.io/) kann unser Gehäuse im (https://multigeiger.readthedocs.io/)L (https://multigeiger.readthedocs.io/)aufe der (https://multigeiger.readthedocs.io/)Jahre (https://multigeiger.readthedocs.io/) porös machen und (https://multigeiger.readthedocs.io/)dadurch (https://multigeiger.readthedocs.io/)schädigen. (https://multigeiger.readthedocs.io/)

(https://multigeiger.readthedocs.io/)

(https://multigeiger.readthedocs.io/)

(https://multigeiger.readthedocs.io/)

(https://multigeiger.readthedocs.io/)

Beispiel Aufstellort (https://multigeiger.readthedocs.io/)

Hier ein Beispiel (https://multigeiger.readthedocs.io/)hafter Vergleich (https://multigeiger.readthedocs.io/) ein (https://multigeiger.readthedocs.io/)es (https://multigeiger.readthedocs.io/) gute (https://multigeiger.readthedocs.io/)n (https://multigeiger.readthedocs.io/) und (https://multigeiger.readthedocs.io/)eines (https://multigeiger.readthedocs.io/)schlechte (https://multigeiger.readthedocs.io/)n (https://multigeiger.readthedocs.io/) Aufstellungsort (https://multigeiger.readthedocs.io/)s (https://multigeiger.readthedocs.io/): (https://multigeiger.readthedocs.io/)

(https://multigeiger.readthedocs.io/)


Vergleich zweier Aufstellorte. Gelb ist die „Nutzb (https://multigeiger.readthedocs.io/)a (https://multigeiger.readthedocs.io/)re Abregenfläche“ (https://multigeiger.readthedocs.io/)

(https://multigeiger.readthedocs.io/)

(https://multigeiger.readthedocs.io/)

Links: Schlechter Aufstellungsort (https://multigeiger.readthedocs.io/)(roter Punkt) (https://multigeiger.readthedocs.io/),
Gründe: (https://multigeiger.readthedocs.io/)

- Wiese: Ein Großteil der Fläche um den Geigerzähler (https://multigeiger.readthedocs.io/)besteht (https://multigeiger.readthedocs.io/) aus Waschbetonplatten. Hier kann kein abgeregneter Fallout gespeichert werden. (https://multigeiger.readthedocs.io/)
- Wind: Die (https://multigeiger.readthedocs.io/)Hauptwindrichtung (https://multigeiger.readthedocs.io/) ist West der Baum erschwert dass bei Wind der Fallout in der Nähe des Zählrohr abgeladen werden kann. (https://multigeiger.readthedocs.io/)
- Sonne: Die Sonne kommt hauptsächlich von Süden und bestrahlt das den (https://multigeiger.readthedocs.io/)Multigeiger (https://multigeiger.readthedocs.io/) stark. (https://multigeiger.readthedocs.io/)

(https://multigeiger.readthedocs.io/)

(https://multigeiger.readthedocs.io/)

Rechts: Guter Aufstellungsort (https://multigeiger.readthedocs.io/)(roter Punkt) (https://multigeiger.readthedocs.io/),
Gründe: (https://multigeiger.readthedocs.io/)

- Wiese: Ein Großteil der Fläche um den Geigerzähler (https://multigeiger.readthedocs.io/)besteht (https://multigeiger.readthedocs.io/) aus Wiesenfläche, die gut abgeregneten Fallout speichern kann. (https://multigeiger.readthedocs.io/)
- Sonne: Der Geigerzähler wird gut vom Gartengeräteschuppen verschattet. (https://multigeiger.readthedocs.io/)

(https://multigeiger.readthedocs.io/)

Weitere (https://multigeiger.readthedocs.io/)Literatur / Info-Material des BFS: (https://multigeiger.readthedocs.io/)

Beschreibung des BFS-ODL-Netzes: (https://multigeiger.readthedocs.io/)

- https://www.bfs.de/SharedDocs/Downloads/BfS/DE/broschueren/ion/radioaktivitaetsmessnetz.pdf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 (https://multigeiger.readthedocs.io/)
- https://odlinfo.bfs.de/DE/themen/wie-wird-gemessen/odl-sonde.html (https://multigeiger.readthedocs.io/)

(https://multigeiger.readthedocs.io/)

Video, Beschreibung des BFS-ODL-Netzes: (https://multigeiger.readthedocs.io/)

- https://www.bfs.de/SharedDocs/Videos/BfS/DE/kt-interview-umweltueberwachung.html (https://multigeiger.readthedocs.io/)

(https://multigeiger.readthedocs.io/)

(https://multigeiger.readthedocs.io/)

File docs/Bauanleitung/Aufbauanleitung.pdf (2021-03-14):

Dies ist nicht die aktuellste Version dieser Anleitung.
Die aktuellste Version findet sich auf: https://multigeiger.readthedocs.io/

HW-Version V1.4 jb/rxf 2019-09 - Handout-Version 2021-03-03 - Lizenz: CC BY-NC-SA 3.0 DE

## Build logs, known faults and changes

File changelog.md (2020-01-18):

# Change Log

### V1.12.0 2020-01-18
* simple OTA (Over-The-Air) updates via web browser based upload, #120
* use less charge pulses in loop() for timing, more in setup() for initial charging, #134
* output error msg on Serial if HV charging fails
* tag log output with "GEIGER: ", #85
* add TUBE_UNKNOWN 0 to have a specific value for experimenting
* adapted platformio.ini to pull all dependencies
* send CR and LF on serial
* changed default tube from sbm-20 to si22g
* semantic versioning, version numbers now like x.y.z
* changed building of revString and lora_version
* docs updated / improved
* explain SBM-19/SBM-20 conversion factor
* removed IotWebconf bundled&patched code, used as a lib now.

### V1.11.1 2019-12-16 rxf
* change luftdaten.info to sensor.community

### V1.11.0 2019-12-16 rxf
* defaults in userdefines-example.h changed
* Software version for LoRa now 2 Bytes
* Display start screen for Wireless stick fixed
* changed to semantic versioning

### Version 1.10 2019-12-13
* conversion factor for Si22G tube fixed
* char variables changed to int
* isr routines shielded with portMUX
* debug serial out formatting improved
* sequence of counting and dispaying and hv charging improved
* speaker and led tick fixed
* many calls to millis() consolidated

### Version 1.9 2019-11-12
* structure for different counter tubes
* LoRa payload changed again
* hv pulse every second
* calculate and display cpm value every 10 seconds
* fixed div by 0 if there's no tube
* Readme corrected

### Version 1.8 2019-11-04
* indentation/spacing, refactor OLED functions, fix conversion factor
* MEASUREMENT_INTERVAL 150sec
* changed LoRa payload

### Version 1.7 2019-10-21
* PINs rearranged, so we can use new Wifi-Kit-32 and WiFi Stick Light
* Hardware-Layout V1.4 and up
* use switch for speaker tick and display off

### Version 1.61 2019-09-30
* default measuring interval is now 2.5min

### Version 1.6 2019-09-13
* some rearrangement of files
* userdefine.h for user changable #defines
* test with dip-switch (needs pullup resistors!)
* Hardware layout V1.3 and lower - OLD Wifi-Kit-32!

### Version 1.5 2019-09-11
* added BME280 (uses same I2C as display)
* Support for display on Wireless Stick
* For LoRa-Devices added LoRa functionality

### Version 1.4 2019-09-03
* default configuration with measurement interval of 10min

### Version 1.3 2019-09-03
* building of ESP-ID out of MAC address is now identical to 'Feinstaubsensor'

### Version 1.2 2019-09-02
* sending to madavi corrected

### Version 1.1 2019-09-01
* Library IoTWebConfig changed -> function 'setThingName' added
* Move this (IoTWebConfig) library to source path
* building the SSID from the MAC corrected: first 3 Bytes of MAC build SSID
* LoRa autodetection removed

### Version 1.0 2019-08-19 rxf
* added detection of LoRa device
* WiFiManager to enter WLAN data and other configs
* send to luftdaten.info every 2.5 min

### Version 0.3 2019-05-12 Juergen Boehringer
* added bug fix for the "Double-Trigger-Problem". This was caused
  by the rising edge falsly triggering an other pulse recording.
  The Problem is that there is no Schmitt-Trigger available in the controller.
* simplified serial printing modes
* made seconds in Display as inverse to be able to separate it from minutes
* cleaned up the code
* Fixed overflow bug in Minute-Count+

### Version 0.2 2019-04-26 Juergen Boehringer
* added 1 Minute RS232 (USB) logging mode

### Version 0.1 2019-03-25 Juergen Boehringer
* first version for ESP32 board

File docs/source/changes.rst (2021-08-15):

.. _changelog:

Changelog
=========

V1.17.0-dev 2021-xx-xx
----------------------

New features:

* ...

Fixes:

* ...

Other changes:

* ...

V1.16.0 2021-08-15
------------------------------

New features:

* local radiation alarm sound, #427

Fixes:

* audio isr fixes, #436
* fix occasional reboots (hopefully), #314

Other changes:

* logging related improvements / code cleanups:

  - emit log header now and then for better readability
  - add UTC timestamp to log output
  - unify radiation and t/h/p log output into single line,
    use "DATA" to mark these lines.
* BLE support now implemented via NimBLE-Arduino lib
* upgrade libs to current versions
* use arduino-esp32 1.0.6

V1.15.1 2021-05-13
------------------

New features:

* None

Fixes:

* initialize sound and LED to "off", #398

Other changes:

* explicitly turn ticking off before melody/init
* cosmetic: don't touch LED in pauses between melody notes
* upgrade to Adafruit BME680 Library >=2.0.0
* add root cert "Amazon CA 1"
* docs:

  - bluetooth: fix app links, fix reST formatting
  - fix typo in sensor.community domain
  - fixed switch numbering, #349
  - add supported counter tubes
  - create multigeiger-bill-of-material.txt
  - developer docs: bump master branch version to -dev after release
  - developer docs: update pulling translations from transifex
  - update translations

V1.15.0 2021-03-21
------------------

New features:

* add bluetooth (BLE) support, #78

Fixes:

* improve LoRaWAN stability (work around LMIC bug #677, add LMIC polling
  from loop()), #373
* do async NTP/clock setup, #316
* speaker: init "duty_mode" member in MCPWM config
* avoid using IotWebConf 3.0.0 for now, #357, PR #370

Other changes:

* patch: restore partition scheme menu for arduino-esp32 1.0.5
* move CI from travis CI to github workflow
* start screen cleanups, #335
* code / naming style fixes
* remove dates in file names, commit relevant versions to git
* add drill files, #354
* docs:

  - use transifex / sphinx / readthedocs.org for translatons (en/de for now)
  - document docs/translation workflow in development docs
  - added assembly and deployment guide
  - document esp32 board buttons, #129
  - document dip switch usage, #128
  - move README-{de,en}.* contents into the .rst docs
  - BLE usage documentation update with some images, #338
  - added links to map, ecocurious, assembly room
  - markup, rendering, spelling fixes, cleanups
  - fix unclear version / date in Aufbauanleitung, #110
  - moved links to docs -> resources, #223
  - add xkcd about radiation doses to FAQ, #310

V1.14.0 2020-05-16
------------------

New features:

* implement status line on OLED display (see docs), #257
* also support BME680 sensor for temperature, humidity, pressure
* display time up to 60s / 60m / 24h / 99d, then roll over
* speaker/LED: timer-driven sequencer, hw PWM sound, #35
* TLS support

  - add clock module, use NTP to set the clock
  - use persistent per-server HTTPClient instances
  - use connection: keep-alive for web requests
  - add https capability (can be used for sending data)
  - note: transmission to sensor.community and madavi is still using http!

Fixes:

* fixed GM pulse debouncing, #248
* pulse counting: deal with microseconds uint32 overflow, #273
* check WiFi status before trying to transmit
* fix race condition, #286

Other changes:

* dip switches: only read once at boot time, #207
* new font (u8x8 uses 8px width anyway)
* slow down main loop
* toilet -> custom server, add comments about toilet usage, #214
* refactor/simplify pulse counting ISR, bookkeeping in main loop, #220
* refactor big main loop into smaller functions with local bookkeeping.
* misc. other code cleanups
* loraWan: removed unused/not needed code, #212, #234
* removed meeting notes, #294
* docs:

  - README improvements (board name, flash size, partition scheme, passwords,
    LoRa)
  - update development/release docs (create/test binaries, IDE settings, ...)

V1.13.0 2020-04-14
------------------

* auto-detect hardware (STICK vs. WIFI) by hardware pin
* use config web page for more values (userdefines.h has the defaults), #140
* try both adresses of BME280
* LoRa payload changes, e.g. to fulfill 'TTN Fair Access Policy'
* send additional data to servers
* send to MADAVI in one single request both geiger and thp data
* new logging with DEFAULT_LOG_LEVEL configuration
* integrated travis-ci:

  - for compile checks (platformio, wifi and stick build)
  - for style checks (using the "astyle" CPP checker)
* source: modularization, cleanups, less globals, ...
  (quite huge internal changes, please help testing!)
* building:

  - platformio-based build: suppress lmic_project_config.h usage
  - arduino-ide-based build: you still need to edit that file
* use bump2version tool for project version bumps, #169
* docs:

  - added upgrade hints for 1.13 in README on github
  - https://multigeiger.readthedocs.io/ == the beginning of
    new (sphinx / reST-markup based) online docs, #163
  - add a basic, short README in English (also for online docs)
  - include infos about project name, #121
  - moved changelog.md to docs/source/changes.rst
  - updated/fixed development docs, #46
  - update docs about new 5V power supply / cabling, #122
  - description of LoRa Payload updated
  - other docs improvements / fixes

V1.12.0 2020-01-18
------------------

* simple OTA (Over-The-Air) updates via web browser based upload, #120
* use less charge pulses in loop() for timing, more in setup() for initial charging, #134
* output error msg on Serial if HV charging fails
* tag log output with "GEIGER: ", #85
* add TUBE_UNKNOWN 0 to have a specific value for experimenting
* adapted platformio.ini to pull all dependencies
* send CR and LF on serial
* changed default tube from sbm-20 to si22g
* semantic versioning, version numbers now like x.y.z
* changed building of revString and lora_version
* docs updated / improved
* explain SBM-19/SBM-20 conversion factor
* removed IotWebconf bundled&patched code, used as a lib now.

V1.11.1 2019-12-16 rxf
----------------------

* change luftdaten.info to sensor.community

V1.11.0 2019-12-16 rxf
----------------------

* defaults in userdefines-example.h changed
* Software version for LoRa now 2 Bytes
* Display start screen for Wireless stick fixed
* changed to semantic versioning

V1.10 2019-12-13
----------------

* conversion factor for Si22G tube fixed
* char variables changed to int
* isr routines shielded with portMUX
* debug serial out formatting improved
* sequence of counting and dispaying and hv charging improved
* speaker and led tick fixed
* many calls to millis() consolidated

V1.9 2019-11-12
---------------

* structure for different counter tubes
* LoRa payload changed again
* hv pulse every second
* calculate and display cpm value every 10 seconds
* fixed div by 0 if there's no tube
* Readme corrected

V1.8 2019-11-04
---------------

* indentation/spacing, refactor OLED functions, fix conversion factor
* MEASUREMENT_INTERVAL 150sec
* changed LoRa payload

V1.7 2019-10-21
---------------

* PINs rearranged, so we can use new Wifi-Kit-32 and WiFi Stick Light
* Hardware-Layout V1.4 and up
* use switch for speaker tick and display off

V1.61 2019-09-30
----------------

* default measuring interval is now 2.5min

V1.6 2019-09-13
---------------

* some rearrangement of files
* userdefine.h for user changable #defines
* test with dip-switch (needs pullup resistors!)
* Hardware layout V1.3 and lower - OLD Wifi-Kit-32!

V1.5 2019-09-11
---------------

* added BME280 (uses same I2C as display)
* Support for display on Wireless Stick
* For LoRa-Devices added LoRa functionality

V1.4 2019-09-03
---------------

* default configuration with measurement interval of 10min

V1.3 2019-09-03
---------------

* building of ESP-ID out of MAC address is now identical to 'Feinstaubsensor'

V1.2 2019-09-02
---------------

* sending to madavi corrected

V1.1 2019-09-01
---------------

* Library IoTWebConfig changed -> function 'setThingName' added
* Move this (IoTWebConfig) library to source path
* building the SSID from the MAC corrected: first 3 Bytes of MAC build SSID
* LoRa autodetection removed

V1.0 2019-08-19 rxf
-------------------

* added detection of LoRa device
* WiFiManager to enter WLAN data and other configs
* send to luftdaten.info every 2.5 min

V0.3 2019-05-12 jb
------------------

* added bug fix for the "Double-Trigger-Problem". This was caused
  by the rising edge falsly triggering an other pulse recording.
  The Problem is that there is no Schmitt-Trigger available in the controller.
* simplified serial printing modes
* made seconds in Display as inverse to be able to separate it from minutes
* cleaned up the code
* Fixed overflow bug in Minute-Count+

V0.2 2019-04-26 jb
------------------

* added 1 Minute RS232 (USB) logging mode

V0.1 2019-03-25 jb
------------------

* first version for ESP32 board

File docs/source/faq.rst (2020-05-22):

.. include:: global.rst.inc
.. highlight:: none
.. _faq:

Frequently Asked Questions
==========================

General
#######

Radiation doses, are there practical examples?
----------------------------------------------

There's a great XKCD about that, see there:

https://xkcd.com/radiation/

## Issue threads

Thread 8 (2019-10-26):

division by zero bug

ThomasWaldmann, 2019-10-26:
I tested the software from current master branch only with the esp32 board, without it being pugged into the (not yet assembled) multigeiger board.

Thus, cpm is 0.

It tries to divide by 0 somewhere (maybe related to cpm == 0?).

Would be nice to avoid that.

```
Gemessen: cpm= 0
SW0: 1  SW1: 1  SW2: 1  SW3: 1
Guru Meditation Error: Core  1 panic'ed (IntegerDivideByZero). Exception was unhandled.
Core 1 register dump:
PC      : 0x400d52d5  PS      : 0x00060430  A0      : 0x800e0ea0  A1      : 0x3ffb1f60
A2      : 0x00000000  A3      : 0x00000000  A4      : 0x3ffc1564  A5      : 0x3ffbebf8
A6      : 0x00000000  A7      : 0x00000001  A8      : 0x800d529c  A9      : 0x3ffb1f40
A10     : 0x0001d4c0  A11     : 0x00000000  A12     : 0x00000000  A13     : 0x3ffb1e90
A14     : 0x00000000  A15     : 0x3ffb0060  SAR     : 0x0000000a  EXCCAUSE: 0x00000006
EXCVADDR: 0x00000000  LBEG    : 0x4000c2e0  LEND    : 0x4000c2f6  LCOUNT  : 0xffffffff

Backtrace: 0x400d52d5:0x3ffb1f60 0x400e0e9d:0x3ffb1fb0 0x4008930d:0x3ffb1fd0

Rebooting...
```

rexfue, 2019-10-27:
OK, will be changed at next version.

ThomasWaldmann, 2019-11-07:
PR #30 says to have fixed this.

ThomasWaldmann, 2019-11-12:
Merged, so hopefully fixed now in master.

ThomasWaldmann, 2019-11-24:
```
Guru Meditation Error: Core  1 panic'ed (IntegerDivideByZero). Exception was unhandled.
Core 1 register dump:
PC      : 0x400d69cf  PS      : 0x00060430  A0      : 0x800e4428  A1      : 0x3ffb1f30
A2      : 0x00000000  A3      : 0x00000096  A4      : 0x00000000  A5      : 0x000003dc
A6      : 0x3ffbec04  A7      : 0x3ffc1630  A8      : 0x800d6990  A9      : 0x3ffb1f10
A10     : 0x00049474  A11     : 0x00000001  A12     : 0x00000000  A13     : 0x3ffc1f00
A14     : 0x3ffb1ecc  A15     : 0x3ffcf434  SAR     : 0x0000000a  EXCCAUSE: 0x00000006
EXCVADDR: 0x00000000  LBEG    : 0x400014fd  LEND    : 0x4000150d  LCOUNT  : 0xffffffff

Backtrace: 0x400d69cf:0x3ffb1f30 0x400e4425:0x3ffb1fb0 0x4008932d:0x3ffb1fd0

Rebooting...
```

Seen with current master branch, no GM tube connected, BME280 connected.

ThomasWaldmann, 2019-12-05:
time_difference has still some issues.

Note the integer not float type:
```
unsigned long time_difference;
```
This should be `if/else` and the `if` needs to compare with 0 (not 0.0):
```
Count_Rate = 0;
if (time_difference != 0.0) {
  Count_Rate = (float)GMC_counts*1000.0 / (float)time_difference;
}
```

Here is a not yet fixed divison-by-zero candidate:
```
current_cpm = (int)(GMC_counts_2send*60000 / time_difference);
```

rexfue, 2019-12-08:
OK, will be fixed

rexfue, 2019-12-08:
Why else? Count_Rate is 0.o, that's ok, I guess.

ThomasWaldmann, 2019-12-08:
yes, it is ok, but it should be in the else branch.

rexfue, 2019-12-08:
why? it's less code this way.

ThomasWaldmann, 2019-12-08:
because you are doing an assignment that has no effect in the if-case (only in the else-case)

Closed 2019-12-09.

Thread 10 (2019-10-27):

Correct resistors for SI22G GM tube

ThomasWaldmann, 2019-10-27:
The current kit expects to solder 4 resistors into the place of 2 (R3/R4) to make: 2m7+2m7+2m7+1m

There is already a remark on paper to replace this with 4m7+4m7 so it fits better into the PCB.

ThomasWaldmann, 2019-11-12:
Was not an issue in recent kits any more.

Closed 2019-11-12.

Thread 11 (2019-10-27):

wrong kit contents or wrong schematic?

ThomasWaldmann, 2019-10-27:
The schematic says:

- C2 10nF
- C4 100pF

My kit contains:

2x WIMA 100/1000 (red 5mm raster foil capacitor, "2,5" printed on the back)

So, what's correct?

rexfue, 2019-10-27:
Also related to wrong (old) PCB version. Sorry for that.

ThomasWaldmann, 2019-10-27:
OK, keep issue open for a while in case someone else also has old PCB.

ThomasWaldmann, 2019-10-27:
Closing, there were only 3 of these boards and their location is known.

ThomasWaldmann, 2019-10-27:
I still think there is an issue.

If you look there, you do not see any 2 capacitors with same value.

So, was my kit contents wrong? Only mine?

rexfue, 2019-10-27:
The Kit-Content is wrong (blame Jürgen :-)  ). Tjalf had the same issue I guess: C2 was missing at his kit.

ThomasWaldmann, 2019-11-09:
OK, guess the inital kit assembling is done by now (and the last kits I received didn't have this issue, so I guess this was a singular mistake). Closing.

Closed 2019-11-09.

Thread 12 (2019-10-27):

PCB: adjust pin distance for D4 to 12.5mm

ThomasWaldmann, 2019-10-27:
D4 BYV26E (glass) seems to have already 90deg bent wires fitting into 12.5mm raster.

The PCB v1.1 jb/rxf has 10mm raster, so one needs to re-adjust the diode wires to that raster.
Consider the diode is glass package, one needs to be careful not to damage it.

Would be better if the PCB fitted to default BYV26E raster of 12.5mm.

PCB v1.1 jb/rxf 2019-06

rexfue, 2019-10-27:
Related to wrong PCB - first test version. Version 1.4 is the actual version.

ThomasWaldmann, 2019-10-27:
Workaround: Can be re-bent using some pliers, be careful, glass!

ThomasWaldmann, 2019-11-23:
Juergen said the diodes usually have straight wires, just these were already bent for some reason.

So this is not a general issue, closing.

Closed 2019-11-23.

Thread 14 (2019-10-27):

LND712 GM tube - can it be used for MultiGeiger?

ThomasWaldmann, 2019-10-27:
From another GM kit (offline only, without WiFi, without LoRa) I have a LND712 (alpha, beta, gamma) which could be put online using multigeiger maybe?

Tube specs: https://www.lndinc.com/products/geiger-mueller-tubes/712/

LND712: 500V (recommended. 450V-650V overall), 10M Anode resistor.

Si22G: 400V (recommended. 360-440V overall).

So, just change the Z-diodes to a sum of 500V?

What I wondered: is putting Z-diodes in series and adding the voltage a valid method?

ThomasWaldmann, 2019-10-29:
answering my z-diode in series question:

https://toshiba.semicon-storage.com/us/design-support/faq/diode/is-it-ok-to-connect-multiple-zener-diodes-in-series.html

ThomasWaldmann, 2019-10-29:
Idea:

Currently, 2x 200V Z-Diodes are used to define a fixed 400V "full" voltage.

Alternatively, 4 Z-Diodes with all-different voltages could be used to adapt to different GM tubes by positioning 2 jumpers left or right on 2x 3-Pins.

upper-left: 180V, upper-right: 240V
lower-left: 220V, lower-right: 260V

That would give: 400V, 440V, 460V, 500V.

Just as an example, Z-D voltages should be selected for availability (same Z-diode manufacturer / type, zener current) and GM tube voltage requirements.

ThomasWaldmann, 2019-10-29:
Hmm, anode resistors also need to adapt.

rexfue, 2019-10-29:
OK, but I think, there is no need to change the GM after building the device. And who wants to do it anyway can change the diodes and the resistor. i guess, this will be a seldom case.

rexfue, 2019-10-29:
I asked Jürgen: We think, the LND712 could be used.

ThomasWaldmann, 2019-10-29:
OK, maybe the jumpers are overkill. Just solder in whatever is needed.

BTW, is there a parts list somewhere? In the schematic, there are sometimes specific part numbers, but iirc the Z-Ds were not specified.

I tried searching some Z-Ds on mouser.com, but the huge amount of choices is confusing...

What are the design criteria to select for? Guess <= 500mW, zener current = ?, tolerance = ?, price, through hole, ...?

rexfue, 2019-10-29:
Alles wird gut => Stückliste ist noch veraltet, Jürgen macht ne Neue und stellt sie dann auf GitHub.
Z-Dioden z.B. BZX85C200, die kleine mit 4V7 ist ziemlich beliebig.

rexfue, 2019-10-29:
mistake: no 4v7, use a 3V3 Z_Diode

ThomasWaldmann, 2019-10-29:
Just had a look at reichelt.de's Z-D offers: nothing above 200V.

So, a nice feature of a future pcb could be to offer 3 places for Z-Ds, so 500V can be made e.g. by 200+200+100. Also more freedom for other desired voltages.

rexfue, 2019-11-03:
Yes, sounds like a good idea. There should be space left for one additional diode.

ThomasWaldmann, 2019-11-26:
See also #86 - it seems the LND712 somehow works (although I am not sure about whether the CPMs seen are as they should be - it's hard to compare with the bigger / different tubes and also I do not have a conversion factor yet for the LND712).

ThomasWaldmann, 2020-05-16:
After a long idle time for the LND712, I pulled that out again, flashed current firmware and it works!

It uses the standard PCB and parts, just with 1 addtl. 100V Z diode in series with the 2 on the board, so the tube gets ~500V as required.

It's ticking happily at:
- ~25 CPM (natural background)
- ~500 CPM (with some radiation source)

OK, so I guess the only stuff that is missing is:
- a reasonably calibrated entry in the "tubes" array + #define for the index
- a spec how to send this to sensor.community / madavi so it does not get mixed up with the Si22G

rexfue, 2020-05-16:
sensor.community will not be a problem, we just have to tell Rajko to take in the LND712

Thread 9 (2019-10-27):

PCB: holes for L1 are too narrow diameter

ThomasWaldmann, 2019-10-27:
when trying to put L1 inductivity through the respective PCB holes, it does not fit, the holes are too narrow (or the wires of that L1 model are too thick).

L1: "154J" black, ferrite.
PCB v1.1 jb/rxf 2019-06

ThomasWaldmann, 2019-10-27:
Workaround: use a sharp cutter knife to thinnen the wires a bit.

rexfue, 2019-10-27:
Also related to wrong (old) PCB version. Sorry for that.

ThomasWaldmann, 2019-10-27:
OK, keep issue open for a while in case someone else also has old PCB.

ThomasWaldmann, 2019-10-27:
Closing, there were only 3 of these boards and their location is known.

Closed 2019-10-27.

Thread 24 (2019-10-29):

PCB: make cut between uC and GM high voltage part possible

ThomasWaldmann, 2019-10-29:
I mean a straight vertical cut just to left-hand side of the JP1 5pin GM-part-of-the-pcb connector.

https://github.com/ecocurious/MultiGeiger/blob/master/docs/Board_V1.4.pdf

The PCB v1.4 is already made in a way so this is **almost** possible.

Just C2 is a bit in the way, so a bit more space for cutting in between the ESP32 part and the GM part would be good.

That way, we could reuse the GM part of the PCB when wanting to use a different uC (now or one day when the esp32 is considered obsolete).

Would also open the doors for people prefering other uCs right now or having already working measurement systems and just not wanting to design their own PCB for the GM part.

rexfue, 2019-10-29:
I agree. You can cut left of C2 using the two mounting holes.
I cannot shift all pieces to the right because the max width of the board can only be 100mm!

ThomasWaldmann, 2019-10-29:
Ah, right, didn't think about the 100mm standard size.

OK, guess cutting there works. Thanks!

Closed 2019-10-29.

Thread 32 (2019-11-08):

use other pins to not need external pullup resistors?

ThomasWaldmann, 2019-11-08:
From the ESP32 docs:
```
GPIO34-39 can only be set as input mode and do not have
software pullup or pulldown functions.
```

That's were PCB 1.4 has the dip switches and the external 10k pullup resistors.

If we could use some other pins, we could use internal (sw configurable) pullups and no need to buy / solder / have PCB space for 4 resistors.

ThomasWaldmann, 2019-11-08:
https://esp32.com/viewtopic.php?t=5111

Internal: about 50kOhm (between 10k and 100k).

ThomasWaldmann, 2019-11-08:
When considering what the lora heltec device uses for other purposes, these GPIOs seem still completely unused:

1 io
3 io
13 io
17 io
32 i
33 i

rexfue, 2019-11-09:
OK, good idea. But wrong!

We want to use 3 Chips: Heltec Wifi Kit 32, Heltec Wireless Stick and Heltec Wireless Stick lite.
And among these 3 there is NO Pin free (see attached Excel sheet).

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

rexfue, 2019-11-09:
Ups sorry, missed the Excel file.

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

ThomasWaldmann, 2019-11-09:
OK, I only looked at the Heltec Wifi and Wifi/Lora uC boards.

ThomasWaldmann, 2019-11-09:
Still would be interested in the spreadsheet. :-)

rexfue, 2019-11-09:
BTW: the switch is only optional- That means, the average user has no need to solder / buy  the the switch and the resitsiors.

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

rexfue, 2019-11-09:
should be on the way (sent 22:33)

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

ThomasWaldmann, 2019-12-17:
Link:

https://github.com/ecocurious/MultiGeiger/blob/master/docs/hardware/Pinning_of_HeltecBoards.pdf

Closed 2019-11-09.

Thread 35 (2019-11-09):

use pwm for sound?

ThomasWaldmann, 2019-11-09:
There is some code toggling GPIOs by software to make the tick sound and some startup sound.

The ESP32 has PWM hardware that can be programmed with frequency, ratio and then runs completely in hardware without using the CPU for toggling pins or doing delays.

Currently, the piezo is connected to 2 GPIOs that are driven inverted to each other to cleverly double the amplitude (by going from hi/lo to lo/hi). Is that needed to be loud enough or would half of that also suffice?

Not sure if we could easily have 2 PWMs that are offset so that they come out inverted.

Note: we could use single PWM even with the current PCB, wasting 1 IO pin by just pulling it low permanently while the other is doing PWM.

rexfue, 2019-11-11:
Good idea.
I will test it, but think it doesn't have any advantage (concerning code size).
At the moment, we don't want to change the software (beside fixing bugs), because want to hold a workshop at the beginning of December.

ThomasWaldmann, 2019-11-11:
OK, fixing just issues for now is fine for me.

So let's delay this until later.

WwwBoehriDe, 2019-12-06:
I think if you only use one pin the Audio-Power would be 1/4 and it would be not loud enough. And acctually I was pretty amazed how good and precise my simple frequency genartor loop worked. The ESP32 is, regarding speed, really a rocket  :-)

ThomasWaldmann, 2020-05-03:
Note: when trying to slow down the fast-spinning main loop (about once per 1-2ms), i noticed that it currently can not be really slow because the tick/blink is generated there. the slower it spins, the less random sounding the ticks get (and also it does not tick once per GM event any more).

If the ticking would not depend on mainloop spinning, but would somehow "run in the background", the main loop could spin way slower (like once per second or so).

If the tick sound would be generated by PWM, maybe the ISR could enable the sound and set a timer which disables the sound a bit later again.

WwwBoehriDe, 2020-05-03:
I think using the PWM-Generator is not possible because this is not able to drive two pins complementary (as far as i know). But two pins complementary pins are required to have enough speaker volume.

I am not sure how this module could run in background. But probalby that is a good idea if it is possible. But then the Interprocess-Communication should not be cryptic but it should be obvious even to programming starers  :-)

ThomasWaldmann, 2020-05-04:
Some links:
- https://esp32.com/viewtopic.php?t=12654
- https://forum.micropython.org/viewtopic.php?t=3717&start=10
- https://forum.micropython.org/viewtopic.php?f=2&t=7774&start=10

docs:
- https://docs.espressif.com/projects/esp-idf/en/latest/esp32/api-reference/peripherals/mcpwm.html
- https://docs.espressif.com/projects/esp-idf/en/latest/esp32/api-reference/peripherals/ledc.html

I never used mcpwm yet (motor control pwm), but the external motor driver circuit schematic looks like A/B outputs need to be inverted, right? So, just what we need for our speaker?

ThomasWaldmann, 2020-05-04:
https://www.espressif.com/sites/default/files/documentation/esp32_technical_reference_manual_en.pdf

figure 110 on page 426 is about what we need (besides that offset, which is likely an advanced feature we just don't need).

rexfue, 2020-05-04:
It looks like it meets our requirements.
But is it worth the effort? Because of the 3sec sound at the beginning? I would rather delete the sound than write new software.

ThomasWaldmann, 2020-05-04:
I've implemented working PWM sound, see comments in PR #251 about what could be done with it in future.

t-pi, 2020-05-04:
Another suggestion:
The loop timer could be set as a function of speakerTick. If ticks are not activated, the loop could run at the much lower period mentioned above.

ThomasWaldmann, 2020-05-05:
@t-pi yeah, if neither speakerTick nor ledTick are active the main loop could spin slower.

Closed 2020-05-12.

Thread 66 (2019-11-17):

decouple hv charging from display update interval

ThomasWaldmann, 2019-11-17:
```
  #define DISPLAYREFRESH 600000
  #define MAXCOUNTS 10000
  // Check if there are enough pulses detected or if enough time has elapsed.
  // If yes, then it is time to charge the HV capacitor and calculate the pulse rate.
  if ((GMC_counts >= MAXCOUNTS) || ((millis() - time2display) >= DISPLAYREFRESH )) {
    ...
    // charge HV capacitor
    ...
    // compute CPM
    ...
    // ... and display it.
```
The code is arranged a bit strangly - I guess it works ok as long as the DISPLAYREFRESH and MAXCOUNTS are kept about like they are, but I think logically, there are 2 issues here:

- The hv capacitor should be charged when needed and this has nothing to do with the DISPLAYREFRESH time.

- Looks like MAXCOUNTS is used for two purposes (so I guess we need MAXCOUNTRECHARGE and MAXCOUNTDISPLAY instead):

  * to trigger a display update (idea: if we have a high count, we can update more quickly without losing precision). How high that value should be for that purpose is a matter of precision requirement, see #38, so one might want to go to a higher value. (MAXCOUNTDISPLAY)
  * to trigger a hv capacitor recharge. this is independent from the other purpose and might need to be kept low to not let the capacitor discharge by too many gm pulses.  (MAXCOUNTRECHARGE)

ThomasWaldmann, 2019-11-17:
There is likely a similar issue with logging, which is also done inside that block (and thus coupled into that although it shouldn't be).

rexfue, 2019-11-18:
A view lines above of the referred lines, there you see  the charging of the cap. That happens every second. And that is independent of display or calculation time.
So I think, we should delete the two lines in the display/calulation block, that charge the capacitor:
    HV_pulse_count = jb_HV_gen_charge__chargepules();         // charge HV capacitor
    hvpulsecnt2send += HV_pulse_count;                        // count for sending
I'll do that in the next PR.
Concerning logging: I guess it should be in that block: every time, we calc a new value, we log it to serial out, why not?

ThomasWaldmann, 2019-11-18:
I didn't do voltage measurements, but I understood the code like that charging the hv capacitor is needed after some pulses because they discharge the capacitor more and more.

If the pulse rate is high, that once per second charge might not be enough maybe.

But that has nothing to do with the display update, that is my point.

Also, the logging should be outside of that block. Just imagine the case that the display would only update once ever 2 minutes. If you want to log more frequently, you can't do it in that every-2-minutes block. If you want to recharge, you can't do it in that block.

rexfue, 2019-11-18:
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

That has to be discussed with Jürgen. We can easily charge more often.

> But that has nothing to do with the display update, that is my point.
>
>
Where do you see the dependency?
> Also, the logging should be outside of that block. Just imagine the case that the display would only update once ever 2 minutes. If you want to log more frequently, you can't do it in that every-2-minutes block. If you want to recharge, you can't do it in that block.
>
>
If we calculate only every 2 min, then we also can log only every 2 min.
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

ThomasWaldmann, 2019-11-18:
The dependency in the current code comes from nesting unrelated stuff into the same if-block. Guess we need multiple if-conditions/blocks for different purposes.

Hmm, yeah, the 2min example was maybe not the best one. :-)

But there is a lot of different logging, so it should just depend on the calculation / availability of stuff to log, not necessarily on the display update. Just decouple stuff that should not be coupled.

ThomasWaldmann, 2019-12-09:
note: guess for decoupling, we also need different GMC counters as we will want to reset them to 0 as soon as we "do something" when reaching some threshold or some other criteria.

maybe instead of adding even more counters to the ISR, we could reduce there to 1 counter and maintain the other counters only in the main loop. that would make the critical sections shorter/quicker.

ThomasWaldmann, 2019-12-09:
removing this from "freiburg workshop" milestone as it is too close and this change has some risk to destabilize the code temporarily.

ThomasWaldmann, 2020-05-11:
fixed by #247. display update is now decoupled from charging.

Closed 2020-05-11.

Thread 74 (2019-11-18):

fix ISRs

ThomasWaldmann, 2019-11-18:
Read a comment that arduino's interrupts/nointerrupts()` is not implemented for esp32.

Assuming this is still the case, we need to do it like there (also note the IRAM_ATTR):

https://github.com/espressif/arduino-esp32/blob/master/libraries/ESP32/examples/Timer/RepeatTimer/RepeatTimer.ino

rexfue, 2019-11-18:
Thank you for commenting this. This seems to be really a problem an I will fix it in the next PR. I guess , it should be considered a bug.

ThomasWaldmann, 2019-11-24:
https://github.com/espressif/esp-idf/blob/master/components/freertos/include/freertos/portmacro.h#L210

So it looks like from inside the ISR function, we need to call `portENTER_CRITICAL_ISR`.

From inside main code, we need to call `portENTER_CRITICAL`.

This is required for portability and only on ESP32 both do the same, but this is not required to be the case elsewhere.

ThomasWaldmann, 2019-11-24:
Also, `mux` is an abbreviation for `mutually exclusive` (or `mutual exclusion`), so we need these calls always when accessing a resource shared by ISR and main code - on both "sides".

Only doing it on one side would mean it can not work, because there is no mutual exclusion happening.

ThomasWaldmann, 2019-11-24:
https://techtutorialsx.com/2017/09/30/esp32-arduino-external-interrupts/ they also use it like I mentioned in previous comment.

rexfue, 2019-11-24:
Only for compatibility reasons I agree. And I will put them in. I hope, they are not too expensive.

But i don’t really think it is necessary in our case. If in mainloop interrupt is disabled by portEnter, no interrupt can access our data. If there is an interrupt at the same time, it is pending until mainloop executes portEXIT and then it will be executed. And the other cpu (the second core) never touches our data! So no task switching  corrupts our data.

Closed 2019-11-26.

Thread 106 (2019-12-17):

RFC: idea: connect a WS2812 LED

ThomasWaldmann, 2019-12-17:
If the geiger is deployed outside in its grey plastik casing, there is little use for:

- the small onboard LED (pin 25 on all controllers)
- onboard OLED display
- maybe also the onboard piezo (except if one is very close with ones ears)

So, what remains is whatever it publishes on the internet.

For the geiger operator (and everybody else close-by) it would be nice to have a more direct display / feedback mechanism - this is how the WS2812 idea came up.

These LEDs are RGB programmable and exist as single LEDs (I got some 8mm ones) and also as LED strips (all with only 1 data input). Links (only to illustrate):

- https://www.sparkfun.com/products/12877
- https://www.sparkfun.com/products/12661

They need: Vcc (5V), GND, DATA_IN (usually works with high level from 3.3V output)
They provide: DATA_OUT for next LED, if any

So, for outside geigers, we could connect Pin25 to one WS2812B LED and let it shine in whatever colour or pulse pattern we like. So the geiger would have a nice shiny upper end. :-)

Mounting options:

- the (single) LED could stick through a whole in the upper end cap and get sealed by the glue that gets put on there anyway. The end cap would stay inside the grey tube and only the LED would stick out a little at the top.

- maybe even more pretty / noticable: let the white end cap stick out from the grey tube a bit and keep the single LED completely inside, so it will illuminate the end cap as a whole from the inside. the glue sealing would only happen on the side of the end cap in that case (not on the top). no drilling required.

The required software should be readily available via a library, these LEDs are quite popular - so our part is quite easy.

What do you think about it?

ThomasWaldmann, 2019-12-17:
(I already used such strips from micropython, was quite easy.)

ThomasWaldmann, 2019-12-17:
https://github.com/adafruit/Adafruit_NeoPixel

Not sure if it helps much for 1 LED, but for a whole strip, this might be less expensive on the CPU as it uses the RMT hardware:

https://github.com/bertmelis/esp32WS2811

rexfue, 2019-12-18:
Really funny idea. I know these RGB devices and use them at the moment in my 'word clock'.
But I don't think that people want to have a flashing or colourful lighting stick in their garden.
So you are welcome to build and implement this, but we won't do it in our project - IMHO.
You can switch off LED, speaker and display by software or by the DIP switch if you populate the board with it.

ThomasWaldmann, 2020-01-19:
Pinout:
- Din
- +5V
- GND (long pin)
- Dout

(need to verify this myself first)

ThomasWaldmann, 2020-02-02:
BTW, I did some first experiments:

Seems like some simple status showing code + the `NeoPixelBus` library would add only about 5kB to our compiled code size and it can be switched on/off via some `#define STATUS_LED 0/1` in `userdefines.h`.

Also, the end caps we use are semi transparent, so they have a nice glow when they have such a 8mm LED inside.

rexfue, 2020-02-02:
I measured the level at pin 25: It's  3.3V, so that shouldn't be a problem.

ThomasWaldmann, 2020-02-02:
OK, now locating the pins to connect the WS2812 LED to:

```
o o o o o o o o o o ...
Prg
USB                             OLED
Rst
o o o o o o o o o o ...
1 2 3 4 5 6 7 8 9 10 ...

1 == GND
2 == +5V
10 == LED
```

ThomasWaldmann, 2020-02-02:
OK, it somehow works, mostly.

Guess I need some serial damping resistor (to avoid reflections) or a capacitor (to stabilize voltage) at the LED or a thicker 5V wire, sometimes it shows wrong colors.

ThomasWaldmann, 2020-03-05:
@rexfue said 13 and 17 are free on current hardware.

jensliebau, 2020-04-07:
> Really funny idea. I know these RGB devices and use them at the moment in my 'word clock'.
But I don't think that people want to have a flashing or colourful lighting stick in their garden.
So you are welcome to build and implement this, but we won't do it in our project - IMHO.

If you place a multigeiger in your garden close to a window you can hear "speakerTick". On the pro side it easy to detect power failure, but depending on how close it is placed to your window it's a little annoying, too. Now than we can disable "speckerTick" in the upcoming release, it would be nice to have some LED for monitoring for state and power failures.

-> So I would vote for adding LED support in an future release.

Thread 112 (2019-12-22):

PCB too high for tube case width

ThomasWaldmann, 2019-12-22:
I noticed that when trying to put the 1.4 PCB into the plastik tube, it almost fits, but not quite.

So guess the PCB should be cut some mm less "high" than it is now to fit into the inner tube width.

Also, some components hit the tube casing from the inside, e.g. the inductivity and the microcontroller if the PCB is forced into the tube (e.g. by squeezing the tube a bit, so it is not round any more).

This could be resolved by having the PCB not sit in the middle of the tube, but slightly in the less wider part, so there is more space above the PCB.

Nordrunner01, 2020-01-02:
Moin

Bez. auf: https://github.com/ecocurious/MultiGeiger/blob/master/docs/Bauanleitung/Aufbauanleitung_2019_13_09.pdf Teil3, Seite 8

Was für ein Rohr ist das denn? HT Abflußrohr?
Maßangaben in welcher Größe? (Millimeter)

rexfue, 2020-01-02:
Masse in mm. Das ist ein Elektriker-Installation-Rohr mit 40mm Durchmesser. Abflussrohr ist etwas dicker -> etwas schlechter.

rexfue, 2020-01-02:
Stimmt net, sind cm!

Nordrunner01, 2020-01-02:
Hmmm....
Das wird nicht lange halten. Nicht UV-Stabil.

Oder gibt es gegensätzliche Erfahrungen?

rexfue, 2020-01-02:
m.E. noch nicht. Aber Du hast sicher recht, das ist nicht UV-stabil. Jürgen ist schon auf der Suche nach einer Alternative.

ThomasWaldmann, 2020-01-05:
Bitte die UV und Rohrmaterial-Diskussion in ein separates Ticket verschieben.

Hier geht es darum, dass die Platine schlecht in das Rohr passt.

DeeKey, 2020-01-05:
Where is PCB itself? Is it opensource?

ThomasWaldmann, 2020-01-05:
@DeeKey see `docs\hardware\`.

rexfue, 2020-01-09:
I cannot follow your complaining about pcb not fixing into tube. My pcb and all the pcbs in the workshops fit fine into the tube. Maybe your sockets are the wrong ones and too high?
So for me there's no reason to redesign.

ThomasWaldmann, 2020-01-09:
@rexfue Can you precisely measure the inner diameter of your plastik tube?

ThomasWaldmann, 2020-01-16:
I measured the tube I bought: inner diameter 37.4mm, outer diameter 40.4mm.

ThomasWaldmann, 2020-01-16:
Problem solved:

The old PCB version I have expected that one needs to break off another ca. 3-4mm stripe (besides breaking the 3 PCBs to separate them from each other).

After breaking that stripe off, it'll fit easily.

The newer PCB production does not need the stripe to be broken off, the stripe is not present.

Closed 2020-01-16.

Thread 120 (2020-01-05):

Firmware Updates

ThomasWaldmann, 2020-01-05:
## Need for a practicable firmware upgrade procedure

### Context
- MultiGeiger likely sits in a sealed tube and the USB port can't be accessed easily without disassembling the device / breaking the seal / resealing it.
- We need to also consider users who are not very technical, so doing manual upgrades (no matter how) might be an issue.
- Guess we would like to keep the devices up-to-date with the latest stable compatible firmware version (for bug fixes and features).

### Upgrade options
Considering this, manual upgrades via USB cable or manual via WiFi using a browser are no good options.

What's left are automated upgrades via WiFi from a internet server.

### Ideas

If the update file is cryptographically signed by a release manager, its integrity and its authenticity can be verified after it is downloaded, before it is flashed (it could be even verified again after flashing [reading it from flash] before switching to it to verify the flash procedure).

That way, the security of the transmission channel or of the server does not matter at all (as long as the signing key[s] are kept secret). We would never flash a tampered firmware.

Also, as long as the device sometimes manages to correctly transfer the file, it would work ok. We would never flash a corrupted firmware (but just retry later).

## Priority

Rather high as it is a pain to upgrade the devices by other means (see "Context").

ThomasWaldmann, 2020-01-05:
## Implementation ideas

### ESP IDF based

Does this mix with Arduino stuff?

https://docs.espressif.com/projects/esp-idf/en/latest/security/secure-boot.html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

This pretty much is what we want, I guess.

### Arduino based

WwwBoehriDe, 2020-01-07:
There was the idea to seal the device completly using silica gel to reduce humidity. Currently it looks like if this is not necessary. So the current housing-design is extremly easy to open and not sealed at all. So you have access to the device and its Micro-USB-Connector in just some seconds.

Please check:
https://github.com/ecocurious/MultiGeiger/blob/master/docs/Bauanleitung/Aufbauanleitung_2019_13_09.pdf
Page 8

I think Reinhard has alredy looked into OTA and found out that there are different memory sizes available on the Heltec-PCBs, which is problematic for OTA. But anyway. Probably its worth to check it again.

ThomasWaldmann, 2020-01-08:
Even if you can reach the USB plug, it is still uncomfortable that way (and unlikely that all/most people frequently do that). Of course one does not need to install all the updates, but maintaining a lot of differently outdated or buggy versions likely is also not fun for the developers.

Reinhard told me that the overall code size might be problematic (see also #84 about that) for the 4MB flash size (but not for the 8MB devices) when using dual partitions for OTA.

ThomasWaldmann, 2020-01-09:
Arduino's partition scheme "Minimal SPIFFS" offers 1.9 MB max. "APP" partitions (two of them, for OTA updates) and 190kB SPIFFS.

@rexfue Some questions:

- do we use a significant SPIFFS amount or are 190kB sufficient?
- what is the maximum binary size / app size you've seen yet? I've seen 0.8MB, but I do not have LoRa.

BTW, our own code is no way that large, most of that are libraries and likely that part could be optimized (not sure if that can be done with Arduino framework though).

rexfue, 2020-01-09:
We don't use SPIFFS (at the moment)
Currently program size is a little bit more than 1 MB in both versions, so this partition scheme should work

ThomasWaldmann, 2020-01-09:
I just wondered where it stores the data one enters via the web interface.

rexfue, 2020-01-09:
It will be saved in "NVS" (or "preferences"), starting at 0x9000 and 0x5000 long (this depends on partition scheme). So its enough for our parameters.

ThomasWaldmann, 2020-01-11:
OK, I'll now work on implementing a simple solution based on OTAWebUpdater.

It won't be very secure, but the point is just having anything that does not require plugging into USB.

This won't be the desired state of OTA for MultiGeiger, but a start.

It should be superseded by a server based update mechanism with cryptographically signed firmware.

ThomasWaldmann, 2020-01-12:
The code from #137 was merged into master, so we now have a simple browser based way to update.

ThomasWaldmann, 2020-01-12:
@rexfue noted that IOTWebConf also has an Updater.

I had a look at that and the code looks quite similar, except that they do not have the "progress indication" which requires JQuery and makes troubles if you do not have an internet connect (because your laptop's wifi is connected to the esp32).

rexfue, 2020-01-12:
Nevertheless I would prefer this one, at least until we have something better. Have you looked at the solution of Feinstaubsensor? They use a server based auto update. I think one day we should use the same.

rexfue, 2020-01-12:
New OTA possibility should be mentioned in Readme !

ThomasWaldmann, 2020-01-12:
Are you saying you prefer current master branch over something based on IOTWebConf?
It looks pretty easy, so I might have that ready today (assuming the library code works).

rexfue, 2020-01-12:
No, the other way round. I prefer IotWebConfig. Also because of #140.

ThomasWaldmann, 2020-01-12:
OK, IotWebConf based updater + docs merged into master now (I reverted my previous OTA code).

So starting from V1.12.0, we have OTA capability, yay! \o/

It's still a bit simple and insecure (only protection is the esp32 AP wifi password and there is no cryptographic signature on the binary) - but better than nothing.

rexfue, 2020-01-12:
Super - thanks.

ThomasWaldmann, 2020-01-13:
Unassigning myself for now - maybe it is better to implement a good solution within IotWebConf or within Arduino framework rather than within our project. Let's see...

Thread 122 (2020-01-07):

alternative power supply / cabling idea

ThomasWaldmann, 2020-01-07:
primarily for @WwwBoehriDe to evaluate:

Power supply cabling based on 5.5mm/2.1mm dc connectors:

- power supply 5V 1A to dc plug: https://www.amazon.de/LiNKFOR-5-5x2-1mm-Hohlstecker-Ladeger%C3%A4t-Wandladeger%C3%A4t/dp/B07PHQMM9M/ (real manufacturer: mass power electronic ltd, china, model NBS05B050100VE)

- 10m dc extension cable: https://www.pollin.de/p/dc-verlaengerungskabel-goobay-71400-10-0-m-563066 "goobay 71400 602-676 ean 4040849714009"

- dc to micro usb adapter cable: https://www.amazon.de/MENGS%C2%AE-m%C3%A4nnlichen-weiblichen-Ladeger%C3%A4t-Adapter/dp/B01ER5AFM6/

I am evaluation similar parts for my geiger.

The dc connector of the adapter cable goes through a hole in the lower end cap (might seal tightly as is or can be sealed with addtl. glue / silicon).

The esp32 is right above the lower end cap.

The GM tube is above the esp32.

Note: maybe wait a bit until I have finished my geiger assembly, still working on it....

Nordrunner01, 2020-01-11:
Hmmmm..... Nope.

So aus dem Bauch raus würde ich sagen keine gute Idee.
2 Gründe:
1. Das Kabel ist nicht Wetter/Umweltfest und eigentlich nur für drinnen gedacht.
2. Bei der Kabellänge bezweiflich ich, daß am Ende noch 5V rauskommen.

Wie wäre es mit diesem Kabel für die Energieübertragung? : https://www.pollin.de/p/cat-6a-netzwerkkabel-s-ftp-outdoor-ip66-schwarz-10-m-740664

Und am Einspeisepunkt eine einstellbare Spannungsquelle um Leitungsverluste ausgleichen zu können.

Nordrunner01, 2020-01-11:
Desweiteren würde ich eine ventilierende Kabelverschraubung als Einführung ins Gehäuse vorschlagen. Etwa in dieser Art: https://www.wiska.com/de/143/cat/313/druckausgleich/

Damit hätte man 2 Fliegen mit einer Klappe geschlagen. 1. Es sieht sauber und professionell aus und 2., man hat das Problem mit der auftretenden Kondensfeuchtigkeit erledigt.

ThomasWaldmann, 2020-01-11:
Ich hab das Stromkabel / alle anderen Oeffnungen versiegelt und wuerde wohl auch etwas Trockenmittel noch in den Innenraum einwerfen. Kommt dann auf nen praktischen Versuch an, ob das oder "Ventilation" besser funktioniert.

Gibt es Schaetzwerte, wie lange so ein Kabel im Freien haelt? Wenn das ein paar Jahre haelt und dann irgendwann ersetzt werden muss, haette ich da angesichts des Preises auch kein Problem mit. Nichts haelt ewig...

WwwBoehriDe, 2020-01-12:
Kabel-Widerstand
===============
ich habe das mal durchgerechnet mit dem Kabel (reichelt.de       DC CAB 21 10M). Angenommen das ist Kupfer (was ich mal hoffe) dann komme ich auf 0,68 Ohm (beide Drähte). Somit wäre der Spannungsabfall <100 mV. Das Heltec-Board müssten wir mit einer Spannung bis zu ca. 3,6 V sicher versorgen können. Erst dann bekommt der Spannungsregler auf dem Heltec (https://www.diodes.com/assets/Datasheets/AP2112.pdf) Probleme. Also müsste man sogar 10 solche Kabel in Serie schalten können. Also daher sehe ich kein Problem

UV-Festigkeit
============
nhhh, naja, klar, das ist für Innenraum gedacht. Aber immerhin ist es schon mal schwarz und somit nicht mehr ganz so anfällig für Sonne. Allerdings haben wir das gleiche Problem mit den kompletten Gehäuse. Ich denke das würde ich einfach riskieren. Man kann ja in die Aufbauanleitung schreiben dass man auch das Kabel an stellen verlegen soll wo keine direkte Sonne hinscheint.

Zugentlastung, Belüfung
====================
Die Zugentlastung ist bisher so angedacht das man das Kabel mit Kabelbinder o. ä. an der Zwischenbodenkruke (s.
https://github.com/ecocurious/MultiGeiger/blob/master/docs/Bauanleitung/Aufbauanleitung_2019_13_09.pdf, Seite 8 )
blockiert. Ich denke das müsste auch reichen.
Die Belüftung ist so geregelt dass das ganze nach unten offen ist und so kein Wasser reinkommen kann. Ein Schutz vor Insekten ist dadurch gewährleistet dass keine Öffnung größer als 0,5 mm ist. Ich denke bisher läuft das ganz gut. Mir ist nichts gegenteiliges bekannt.

Vielleicht ist das bisher gewachsene Gehäuse-Design etwas speziell - aber man muss immer sehen dass es preiswert, einfach aufzubauen, jederzeit zugänglich (Wartungsarbeiten) und dennoch funktional sein soll. Und das sind Dinge wie komplett verschließen und Silica-Gel für den normalen Anweder eben schwierig.

ThomasWaldmann, 2020-01-16:
Power suppy: as in top post.

10m cable: as in top post.

Multigeiger V1.4 with BME280.

Measured voltage (at uC): 4.85V (display on, speaker on, wifi on, standard background radiation, Si22G tube).

Measured voltage (at power supply DC plug, no load): 4.98V

ThomasWaldmann, 2020-01-16:
Measured with better(?) DVM:

4.88V (at uC, as above)

5.02V (at power supply, no load).

ThomasWaldmann, 2020-01-16:
Same measurements, same type of power supply (bought 2 pieces):

4.92V (better DVM: 4.96V, at uC, load)
5.05V (better DVM: 5.08V, at power supply, no load)

ThomasWaldmann, 2020-02-01:
@WwwBoehriDe I see you updated the hardware assembly docs about the power supply idea.

https://github.com/ecocurious/MultiGeiger/blob/master/docs/hardware/MultiGeiger_Partlist.ods

But the parts are not on the part list yet, update the list also?

ThomasWaldmann, 2020-02-11:
@WwwBoehriDe did you see my last comment?

ThomasWaldmann, 2020-02-14:
c3a7207da7976c26f723ffa6f408cc6b2d0bf88f looks like this was fixed 3d ago.

ThomasWaldmann, 2020-02-14:
guess "all done" here, closing.

Closed 2020-02-14.

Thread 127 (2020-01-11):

Frage: Ist es möglich die Platine um einen Stepdownwandler zu erweitern?

Nordrunner01, 2020-01-11:
Moin

Bezug auf: https://github.com/ecocurious/MultiGeiger/issues/122

Wenn man auf der Platine des Multigeiger einen Stepdownwandler integrieren würde, dann wäre eine Spannungsversorgung aus dem Bereich Netzwerk (PoE) möglich.
Beispielhaft wäre hier ein Wandlermodul LM2596 ( https://www.google.de/search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 ).
Dieser ist natürlich mit seinen 3A völlig überdimensioniert und dient nur als Beispiel.

Gruß

ThomasWaldmann, 2020-01-11:
Wir verwenden ja momentan nur WiFi oder LoRa, also kein Ethernet-Kabel.

Die verwendeten EPS32-Boards haben auch (so wie sie sind) keinen Ethernet-Anschluss.

Abgesehen davon gute Idee, wenn man eh 1 Kabel verlegen muss, koennte man das natuerlich fuer Ethernet UND Power verwenden.

ThomasWaldmann, 2020-01-11:
@Nordrunner01 waer es sinnvoll, den Issue Title auf "LAN / PoE - Support?" zu aendern?

Nordrunner01, 2020-01-11:
@ThomasWaldmann
Warum? Es geht nicht um PoE. Habe ich auch so nie geschrieben. Die Technik stammt von dort und es gibt dort entsprechende Injektoren. Es geht lediglich um die Übertragung der Betriebsspannung.

ThomasWaldmann, 2020-01-11:
BTW, auf den ESP32-Boards ist bereits ein 5V -> 3.3V Wandler/Regler drauf.

Wieviel Spielraum dadurch bei den 5V nach unten besteht waere aber zu klaeren.

Nordrunner01, 2020-01-11:
Na ja, bei den Feinstaubsensoren wird ja auch über ein 5m USBflachbandkabel der Betriebsstrom geschickt. Und es funzt.
Ich bin aber eher ein Freund von ein wenig mehr und Luft nach unten, als schon von Anfang an auf Kante zu nähen.

ThomasWaldmann, 2020-05-11:
Guess this should be answered by @rexfue and @WwwBoehriDe.

Considering the silence, I guess there is no interest to add a stepdown converter?

WwwBoehriDe, 2020-05-12:
Hi, Ich habe mal nachgeschaut: An den Modulen müsste man eine Spannung bis runter auf 4,0 V einspeisen können. Ab dann gerät der USB-Seriell-Chip "out of Spec" - was aber vermutlich unkritisch ist. Praktisch kann man vermutlich runter gehen auf 3,6 V - dann geht dem Spannungsregler die Puste aus. Aber gehen wir von 4,0 V aus dann kann 1,0 V auf der Leitung verlorengehen - bei 0,1 A. Sprich wir können 10 Ohm Leitungswiderstand erlauben. Mit unserem derzeitigen Kabel haben wir 360 mOhm pro Ader - sprich zusammen 720 mOhm (pro 10 m Stück). Sprich somit wären 130 m Kabel möglich. Allerdings könnte das mit dünnem LAN-Kabel und den zusätzlichen PoE-Komponenten ganz anders aussehen.

ThomasWaldmann, 2020-05-12:
@WwwBoehriDe The power injectors used in PoE context provide about 50V.

ThomasWaldmann, 2020-05-22:
Seems like the answer is "no" or "no interest", thus I am closing this.

I might be wrong, so just answer differently and re-open if that is the case.

Closed 2020-05-22.

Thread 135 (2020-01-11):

amount of hv charge pulses seen?

ThomasWaldmann, 2020-01-11:
I just noticed that I am seeing "1000" as usual hv counts value on both my devices (one with standard si22g 400V, one with my experiment with the lnd712 500V).

As this is the max value, it basically means that the hv cap full is not triggering.

@rexfue @WwwBoehriDe what do you see with current master branch firmware?

ThomasWaldmann, 2020-01-11:
Ignore this.

I've accidentally compiled/uploaded the firmware while having a different esp32 board selected in the arduino ide. After switching to the correct one, it works again normally (seeing usually "1" hv pulse in serial output).

Well, at least I was motivated to unhide the error of a non-working hv generation, see PRs. :-)

Closed 2020-01-11.

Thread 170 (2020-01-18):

silence?

ThomasWaldmann, 2020-01-18:
I have the MultiGeiger running since a while and usually it is ticking normally.

But sometimes, there are multiple seconds silence, not a single tick. Why? I have a source with ~250 CPM close by, so no GM event for multiple seconds is highly unlikely.

Not sure if it is related, but I noticed this since flashing a binary (V1.12.0) that has sending to madwifi and sensor.community enabled (but I did not register / configure anything special related to that). Is there some buffer filling up and then blocking somehow?

rexfue, 2020-01-19:
Yes, this seems to be a timeout in the http library.  But this does not affect the count ( interrupt !! ).

t-pi, 2020-01-20:
Indeed, I noted the same tonight (2020-01-19 evening). Madavi was not responding and the Multigeiger seemed stuck while "Sending to Madavi...". But if the counts are still registered, guess it's not critical...

ThomasWaldmann, 2020-05-08:
To be more precise:

The root cause for the intervals of silence is that the ticking in current firmware is done in main loop.

If the main loop is stuck in some data transmission call (and waits until some timeout in there), it won't call the code doing the speaker/led tick. PR #251 is ongoing work on this, doing the tick sound via PWM (works already) and later also turning tick sound on from GM pulse ISR and off by a timer ISR (TODO).

The HV charging is also done from within main loop (will be changed by PR #254 to be timer interrupt driven), but at low radiation levels a few seconds with no hv charge is no problem AFAIK.

As @rexfue noted, the GM pulse counting is already interrupt driven, so counts won't be missed.

ThomasWaldmann, 2020-05-12:
Should be solved by the mentioned PRs, see previous comment.

Closed 2020-05-12.

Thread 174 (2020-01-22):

Porting to Olimex ESP32-POE

hagenbuch, 2020-01-22:
Hi all,

great device, great software, thanks very much!

However, where I'd like to use the device, I will have no Wifi but Ethernet and POE (if you have to run a cable anyway, why send more than one?) so I bought a Olimex ESP32-POE

https://www.olimex.com/Products/IoT/ESP32/ESP32-POE/open-source-hardware

The hardware is also very "slender" so it would fit into a tube perfectly.

(Yes there is a more expensive version with a better ETH transformer but I guess IM fine with the "old" one, I have revision B).

I managed to flash the simple ethernet demo

https://github.com/OLIMEX/ESP32-POE/blob/master/SOFTWARE/ARDUINO/ESP32_PoE_Ethernet_Arduino/ESP32_PoE_Ethernet_Arduino.ino

on the Olimex but I'm not sure where to start to merge their code with yours. Does someone have a starting point?

Would be awesome. I think cabling can be made by dupont cables.. I also would like to read from an BME280 at the same time.

Andreas

rexfue, 2020-01-23:
I think if you use the same PINs as our board (also for the I2C bus), our software should work 'out of the box' with WLAN.  An adaptation to ethernet should then be quite easy. Since I don't have such hardware, I can't try that.
Please keep the connection with Dupont cables as short as possible - the inputs are very high impedance and crosstalk is easy.
Btw. BME280 is included in the software.

ThomasWaldmann, 2020-02-21:
The (wireless)LAN related code is now in `webconf.*`.

`transmission.*` expects a working network connection (but does not care whether it is wireless or wired or LoRa).

ThomasWaldmann, 2020-05-11:
As there was no activity in here, guess we can close this.

Closed 2020-05-11.

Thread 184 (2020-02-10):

Use TLS (https) for API access?

justinotherguy, 2020-02-10:
Moin,

If I'm not mistaken, currently we're using (unencrypted) http only to access the APIs:
https://github.com/ecocurious2/MultiGeiger/blob/master/multigeiger/multigeiger.ino#L198

What's the reason for this? The ESP32 should have enough power - do the libraries we use support TLS? Have we done a test for this yet?

Regards, J.

ThomasWaldmann, 2020-02-10:
Yeah, that's the current state.

https would be better of course, but needs some infrastructure / environment:
- https on server side
- precise time on client side (ntp)
- https on client side (space requirements = ?)
- actually checking the server's authenticity (because I guess we mostly are after that, not primarily after encrypting data which will be published anyway)

justinotherguy, 2020-02-10:
- https on server side
-> a quick test showed that all 3 currently used APIs also provide https; and the cert setup looks proper, too -> that should not be a problem, so

- precise time on client side (ntp)
-> ok - we do need a source for time to assess the validity of the certificates, true; we should be able to obain that via ntp; but - that needs to be implemented first, too - correct

- https on client side (space requirements = ?)
-> true; I had only thought of CPU power - but we also need RAM for the code

- actually checking the server's authenticity (because I guess we mostly are after that, not primarily after encrypting data which will be published anyway)
-> true; checking data integrity or authenticity of the client doesn't make sense in this setup, either :)

ThomasWaldmann, 2020-02-10:
Well, checking authenticity of the client and data integrity actually would make sense, IMHO.

But I do not know whether / how authenticity check is done by these APIs (username / password maybe?).

Data integrity would be only done on the TCP level currently, which is ok against accidental corruption, but not against attacks.

ThomasWaldmann, 2020-02-10:
And if it is done by username/password, that is of course an additional reason to use https.

ThomasWaldmann, 2020-02-10:
https://github.com/espressif/arduino-esp32/blob/master/libraries/HTTPClient/examples/BasicHttpsClient/BasicHttpsClient.ino

https://github.com/espressif/arduino-esp32/blob/master/libraries/HTTPClient/examples/HTTPClientEnterprise/HTTPClientEnterprise.ino

Note: HTTPCLIENT_1_1_COMPATIBLE api functions are deprecated.

ThomasWaldmann, 2020-02-10:
# MADAVI "http://api-rrd.madavi.de/data.php"

# SENSORCOMMUNITY "http://api.sensor.community/v1/push-sensor-data/"

# TOILET "http://ptsv2.com/t/enbwck3/post"

ThomasWaldmann, 2020-02-10:
Found some timing data on the web and they say a https (tls) connect takes ~2s.

So, we could optimize the client so it tries to keep the connection open, putting additional burden on the server (lots of connections if there are lots of geigers). Also, the server might still disconnect.

Or we don't and wait 2s...

ThomasWaldmann, 2020-02-10:
BTW, we maybe should avoid loading firmware updates over https / tls - otherwise we could run into a dead lock situation:
- assuming we need to update the CA cert (because it expired or CA change or ...).
- if the update is fetched via https (tls) and we can't connect due to a cert issue, we can't update the CA cert that is in the firmware either.

So rather fetch firmware via http and use a signed firmware image, see #120.

ThomasWaldmann, 2020-02-10:
Debugging TLS: on Arduino IDE, set core debug level to verbose.

ThomasWaldmann, 2020-02-11:
btw, it doesn't look like the arduino-esp32 lib checks for certificate expiry. at least it had no problem with the certs when i set the esp32 time to y2038.

ThomasWaldmann, 2020-02-11:
another issue is that the CA certs aren't valid for a very long time.
so, if we include them into our firmware we must not forget to update them 2021.

how the cert rollover should work best is not totally clear to me yet.

ThomasWaldmann, 2020-02-11:
[https_test.txt](https://github.com/ecocurious2/MultiGeiger/files/4183635/https_test.txt)

ThomasWaldmann, 2020-02-16:
https://letsencrypt.org/certificates/

http://esp32-server.de/wificlientsecure/

https://esp32.com/viewtopic.php?t=7585#p31952
https://www.esp32.com/viewtopic.php?t=3870#p17576

https://www.sslshopper.com/certificate-decoder.html

ThomasWaldmann, 2020-02-16:
So the solution might be to concatenate all root CAs we need (misc CAs, old certs, new certs, ...).

And really use the root certs, not the letsencrypt X3 intermediate CA cert.

ThomasWaldmann, 2020-02-16:
[https_test.txt](https://github.com/ecocurious2/MultiGeiger/files/4211018/https_test.txt)

Looks like that works! \o/

justinotherguy, 2020-02-16:
excellent - sounds like a good approach \o/

ThomasWaldmann, 2020-02-21:
TODO: update release making checklist:

Check whether some CA certificate will expire soon and whether we already can add their next valid cert.

ThomasWaldmann, 2020-04-14:
there's some code in #236 to review and practically test.

Closed 2020-05-08.

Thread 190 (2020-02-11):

platformio compile issues seen on travis-ci

ThomasWaldmann, 2020-02-11:
```
CONFIGURATION: https://docs.platformio.org/page/boards/espressif32/heltec_wifi_kit_32.html

PLATFORM: Espressif 32 1.11.1 > Heltec WiFi Kit 32

HARDWARE: ESP32 240MHz, 320KB RAM, 4MB Flash

DEBUG: Current (esp-prog) External (esp-prog, iot-bus-jtag, jlink, minimodule, olimex-arm-usb-ocd, olimex-arm-usb-ocd-h, olimex-arm-usb-tiny-h, olimex-jtag-tiny, tumpa)

PACKAGES: toolchain-xtensa32 2.50200.80 (5.2.0), framework-arduinoespressif32 2.10004.191002 (1.0.4), tool-esptoolpy 1.20600.0 (2.6.0)

Converting multigeiger.ino

/home/travis/build/ecocurious2/MultiGeiger/multigeiger/multigeiger.ino:135:0: warning: "PIN_SWI_0" redefined

 #define PIN_SWI_0 39

 ^

/home/travis/build/ecocurious2/MultiGeiger/multigeiger/multigeiger.ino:130:0: note: this is the location of the previous definition

 #define PIN_SWI_0 36

 ^

/home/travis/build/ecocurious2/MultiGeiger/multigeiger/multigeiger.ino:136:0: warning: "PIN_SWI_1" redefined

 #define PIN_SWI_1 38

 ^

/home/travis/build/ecocurious2/MultiGeiger/multigeiger/multigeiger.ino:131:0: note: this is the location of the previous definition

 #define PIN_SWI_1 37

 ^

/home/travis/build/ecocurious2/MultiGeiger/multigeiger/multigeiger.ino:137:0: warning: "PIN_SWI_2" redefined

 #define PIN_SWI_2 37

 ^

/home/travis/build/ecocurious2/MultiGeiger/multigeiger/multigeiger.ino:132:0: note: this is the location of the previous definition

 #define PIN_SWI_2 38

 ^

/home/travis/build/ecocurious2/MultiGeiger/multigeiger/multigeiger.ino:138:0: warning: "PIN_SWI_3" redefined

 #define PIN_SWI_3 36

 ^

/home/travis/build/ecocurious2/MultiGeiger/multigeiger/multigeiger.ino:133:0: note: this is the location of the previous definition

 #define PIN_SWI_3 39

 ^

/home/travis/build/ecocurious2/MultiGeiger/multigeiger/multigeiger.ino:933:66: warning: missing terminating " character

   String body = "{\"software_version\":\"" + String(revString) + "\",\"sensordatavalues\":[\

                                                                  ^

/home/travis/build/ecocurious2/MultiGeiger/multigeiger/multigeiger.ino:934:79: warning: missing terminating " character

 {\"value_type\":\"" + temp + "\",\"value\":\"" + String(bme_temperature, 2) + "\"},\

                                                                               ^

/home/travis/build/ecocurious2/MultiGeiger/multigeiger/multigeiger.ino:935:76: warning: missing terminating " character

 {\"value_type\":\"" + humi + "\",\"value\":\"" + String(bme_humidity, 2) + "\"},\

                                                                            ^

/home/travis/build/ecocurious2/MultiGeiger/multigeiger/multigeiger.ino:936:77: warning: missing terminating " character

 {\"value_type\":\"" + press + "\",\"value\":\"" + String(bme_pressure, 2) + "\"}\

                                                                             ^

/home/travis/build/ecocurious2/MultiGeiger/multigeiger/multigeiger.ino:937:3: warning: missing terminating " character

 ]}";
```

ThomasWaldmann, 2020-02-11:
The #define issues seem false positives as the originals and duplicates are in a #if / #else.

The string assembly looks a bit ugly anyway, should be solved in another way that needs less escaping and + operators, sprintf maybe?

rexfue, 2020-02-11:
I work on this at the moment - I will pack it into a function

ThomasWaldmann, 2020-02-18:
Seems like #200 fixed that.

Closed 2020-02-21.

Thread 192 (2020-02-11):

HV pulse every sec using a timer

rexfue, 2020-02-11:
It seems, that if Wifi connection has problems, the HV will not be charged for many seconds.
So we should use a hardware timer and timer interrupt to charge HV every second.

ThomasWaldmann, 2020-02-11:
Would a `GM pulse interrupt` be able to interrupt the `HV load ISR code`?

rexfue, 2020-02-11:
Don't no at the moment, will investigate. But I think, it should be possible.

jwoelk, 2020-02-25:
I made an experiment this evening, replacing the GM tube by a 1s pulse generator at GMZ_COUNT (3.3V amplitude, 99% duty cycle). Please find the serial protocol attached. The equidistant pulses cause the SW to run very smoothly. 10 s are always accurate for +- 1 ms. As you can see, sending measurement values of two sensors (SI-22G + BME280) sometimes takes up to 12 s in normal cases. If a transmission times out, this adds about 6 s. The extreme case seen was 42 s, where both transmissions to madavi crashed with a "socket error" message.
2 weeks ago I had connected my scope via a 1 GOhm resistor for some time, as advised by Juergen. During WiFi transmissions the HV plateau region was then left after about 10 s (rough estimation), suppressing further tube pulses. This resistance corresponds to an additional ambient dose rate of 8.4 uSv/h according to my calculation. I think the Multigeiger should be able to measure such a dose rate. So I would appreciate when the HV would be charged regularily each second.

[putty-ESF32-20200225-with_1s-pulse-gen.log](https://github.com/ecocurious2/MultiGeiger/files/4252102/putty-ESF32-20200225-with_1s-pulse-gen.log)

Best Regards
Joachim

P.S.: meine Nebenrechnung zur Belastung der Hochspannung durch den 1 GOhm-Widerstand:

Vorwiderstand am GMZ:                             10 MOhm
Spannungseinbruchtiefe während der GMZ-Entladung: 60 V
Restspannung am GMZ während der GMZ-Entladung:   340 V
Dauer der GMZ-Entladung (nach Umformung in ein äquivalentes Rechteck mit gleicher Höhe): 0,4 ms
GMZ-Widerstand während der Entladung: 340/60 * 10 MOhm = 57 MOhm
Zahl der Entladungen/s bei 100 nSv/h: ca. 1,7
resultierender mittl. GMZ-Widerstand bei 100 nSv/h: 57 MOhm / (1,7/s * 0,0004s) = 84 GOhm

Max. Zahl der Entladungen/s: 1 / 0,0004 = 2500 ~= 150 uSv/h
Praktikabel: 100 uSv/h = 1700 cnt/s
resultierender mittl. Widerstand: 57 MOhm / (1700 * 0,0004) = 84 MOhm

Tastkopf mit 1 GOhm Vorwiderstand entspricht einer ODL: 84 GOhm / 1 GOhm * 0,1 uSv/h = 8,4 uSv/h

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

ThomasWaldmann, 2020-02-25:
See my comments there: #184

Keeping the connections might speed up transmission significantly (IF the server doesn't close before we transmit next measurement), especially in case of a TLS connection. I'll do the tls changes / connection keeping changes after next release.

rexfue, 2020-05-04:
Maybe HTTP/TLS connection can be speeded up, but LoRa needs about 4sec (at the moment). So we should use timer interrupt to charge every sec.

ThomasWaldmann, 2020-05-07:
@jwoelk I don't have an oscilloscope here - can you test the PR #254 code and see how the HV recharging / HV voltage looks like (maybe at different radiation levels)?

jwoelk, 2020-05-08:
Hi Thomas,

I will do that, but need some days because of other duties. Maybe two
weeks. I also never downloaded SW to the ESP32, but remember to have
seen instructions somewhere. I think I should be able to get on,
otherwise I will ask someone.

I can only simulate two different radiation levels: 1. the natural level
at home, 2. the same with an additional 1 GOhm resistor in parallel with
the GM tube that emulates an effective level of about 8.4 uSv/h. I need
the resistor to attach the scope probe to the HV.

Cheers

Joachim

Am 08.05.2020 um 00:34 schrieb TW:
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
--
Joachim Wölk
Luisenstraße 19
74354 Besigheim
Tel. 07143 31097

jwoelk, 2020-05-13:
@ThomasWaldmann

Tested 2020-05-12 on Windows 10 Pro 1909 with HW Node esp32-7936340 (Sensor IDs 40369 / Si22g + 40370 / BME280), SW 1.13.1-dev on branch pr/254 and the following libs:
 - Adafruit BME280 2.0.2
 - Adafruit Unified Sensor 1.1.2
 - Adafruit ADXL343 1.2.0
 - IoTWebConf 2.3.1
 - MCCI LoRaWAN LMIC library 3.1.0
 - U8g2 2.27.6

Measurements Part 1: Normal operation, steady state. About 0,11 uSv/h.

HV_FET_OUT (1 V/div): about 3.3 V amplitude and 1.6 ms duration per single pulse. Occurs in terms of pulse trains each 3.8 seconds (measured manually with a stop watch). A pulse train comprizes two pulses in most cases, but sometimes one pulse or three pulses, with a pulse repetition rate of 2.7 ms.
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

HV_CAP_FULL (1 V/div): about 1.6 V amplitude or more and 10 us pulse duration. Pulse trains with two pulses in most cases, as above. The screenshot shows a train of three pulses with staggered amplitudes (1.3 V, 1.6 V, 2.0 V). Amplitude of 1st pulse varies between 1.3 and 2.0 V. If it is > 1.8 V, no more pulses follow. Amplitude of 2nd pulse is 1.6 ... 2.0 V. Amplitude of 3rd pulse 1.9 ... 2.1 V.
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

Here a single HV_CAP_FUL pulse:
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

Measurements Part 2: added a 1 GigOhm resistor between HV (tube + pole) and a second 10 MOhm probe.

HV_FET_OUT: pulse train repetition rate is now about 0.3 s. Pulse trains still have two, sometimes one or three pulses. In one single case a 4-pulse train was seen.
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

HV_CAP_FULL: pulse train repetition rate is again the same as HV_FET_OUT. Other characteristics remain.

HV (100 V/div, yellow trace in the following screenshot): is stable, also during the HTTP transmission phase. Unfortunately there is a 50 Vpp 50 Hz hum overlaid, of which I cannot tell the source. Nevertheless one can see that the first HV_FET_OUT pulse within a pulse train augments HV by maybe 10 V.
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

If I may add a jadgement: I think the FW update is working rather satisfying.

ThomasWaldmann, 2020-05-13:
Pulse repetition rate 2.7ms (expected: 1500us + 1000us = 2.5ms, 100us ISR timer) uncovered another off-by-one error, see #288. Thanks!

jwoelk, 2020-05-13:
My serial log (normal operation):
[putty-ESF32_20200512_1.13.1-dev.log](https://github.com/ecocurious2/MultiGeiger/files/4624464/putty-ESF32_20200512_1.13.1-dev.log)

The serial log with HV+ connected to a 2nd scope probe via 1 1GigOhm resistor:
[putty-ESF32_20200512(+HV)_1.13.1-dev.log](https://github.com/ecocurious2/MultiGeiger/files/4624471/putty-ESF32_20200512.%2BHV._1.13.1-dev.log)

ThomasWaldmann, 2020-05-13:
The HV_CAP_FULL pulse **trains** are a bit unexpected.

Instead of slightly increasing amplitudes from first to third pulse in such a train, I had rather expected no 1st and 2nd pulse (or very very low amplitude) and only a final (and definitely high enough) pulse when the cap is full.

Can you say something about the time distance between:
- first HV_FET rising edge and first HV_CAP_FULL rising edge?
- first HV_FET falling edge and first HV_CAP_FULL rising edge?

jwoelk, 2020-05-14:
Hi Thomas, here are two new screenshots: HV_FET_OUT is green, HV_CAP_FUL is yellow. Both 1 V /div.

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

The 2nd screenshot shows in detail a falling HV_FET_OUT edge and the corresponding HV_CAP_FUL pulse.

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

ThomasWaldmann, 2020-05-14:
OK, so when comparing this to algorithm:
- rise HV_FET_OUT
- pause 1500us (via timer)
- lower HV_FET_OUT
- ~10us later HV_CAP_FULL pulse while pausing 1000us (via timer)
- check whether there was a HV_CAP_FULL event

So it looks like there are ~990us time (within the "low phase" of the charge pulse) for the ISR to set the hv_cap_full variable, which is way more than enough.

So, it seems we are doing analogue stuff here: "is the HV_CAP_FUL rising high enough to actually trigger an interrupt" rather than (what I expected) digital stuff "is the HV_CAP_FUL" pulse happening or not.

ThomasWaldmann, 2020-05-14:
Idea (please check): how much is the measurement equipment influencing the HV_CAP_FUL signal height? I mean e.g. the oscilloscope probe's capacitance and cable inductivity.

ThomasWaldmann, 2020-05-14:
Reopening this until discussion finished for better visibility.

ThomasWaldmann, 2020-05-15:
We'll have timer interrupt driven charging in V1.14.0 release, code is already merged.

jwoelk, 2020-06-01:
An oscilloscope probe has an impedance of about 1 or 10 Mohm in parallel with 10 pF. Connected to node HV_CAP_FUL, the probe is in parallel with R1 (10k +- 5%) and C2 (10n, 10%), hence the additional load is small, even below the parts' tolerances. I would not expect any influence from probing this signal.

As an experiment, I connected two probes, one of 1 MOhm and one of 10 MOhm, in parallel. Then I removed one probe or the other. I cannot tell any difference, because the pulses vary slightly anyway from one occurence to the next.

On the other hand, the tolerances of the ZY200 diodes are quite large, from 188 to 212 V, at 5 mA current. When the HV_CAP_FUL signal reaches 2 V, only 0.2 mA flow through R1. According to the old General Semiconductor datasheet

https://cdn-reichelt.de/documents/datenblatt/A400/ZY1-THRU-ZY200_ENG_DATASHEET.pdf

the dynamic resistance is about 850 ohms at 0.2 mA, going down to about 150 ohms at 5 mA. At 2.5 mA it is 200 ohms. This means the smaller current reduces the zener voltage further by roughly estimated 2.5 mA * 200 ohms = 0.5 V.

This means the HV of two diodes in series can be as low as 375 V or as high as 423 V. Fortunately the plateau region of the Si22G tube goes from 350 V to 450 V. Ditto SBM-19 and SBM-20.

---

When I remove the tube, then I see one HV_FET_OUT pulse every 10 s. It is always one, never two or three in a train. With the Si22G tube, in steady-state a two-pulse train comes every 4 s.

ThomasWaldmann, 2021-05-15:
AFAICS, the interrupt-driven adaptive charging is working OK (at least at relatively low radiation levels), so I am closing this for now.

Closed 2021-05-15.

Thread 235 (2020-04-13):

code does not compile for wifi kit 32 any more

ThomasWaldmann, 2020-04-13:
i wanted to flash via usb and set the arduino ide to `heltec wifi kit 32`.

the code does not compile any more due to missing LoRa pin definitions (e.g. `DIO2`).

wanted to go the usb way because i needed usb logging anyway to debug some code.

besides that, for the initial flash of a new device, one needs to compile for correct hw platform to get correct partition layout.

additionally, I managed to lose OTA capability by flashing a buggy firmware onto the device that crashes and reboots all the time (thus no WiFi OTA flashing).

thus, with the current state of device, no OTA flashing and with current state of the code, no USB flashing from arduino IDE.

ThomasWaldmann, 2020-04-13:
I suggest we:
- create a branch hardware_decision from current master
- reset master to cdf88e193158e77a366d99b4b8b5de186c662290 (last changeset before the hardware_decision work)

rexfue, 2020-04-14:
It compels, if you set CPU to Heltec wireless stick in Arduino ide, as is written in the read.me. The nit compiles for both hardwares . See readme PR ! It also does the right partitioning.

ThomasWaldmann, 2020-04-14:
Just setting the IDE to wireless stick also sets it to 8MB flash size and no OTA. That for sure won't work.

For everything else I guess we do not have documentation...

It **might** maybe work when also setting to 4MB flash size and "Minimal SPIFFS", but I didn't try that yet.

rexfue, 2020-04-14:
That **does** work. Ist sets partition to default 8MB, the means 4MB app and 4MB OTA.See compilation result:
Sketch uses 1034898 bytes (30%) of program storage space. Maximum is 3342336 bytes.
And also the default_8MBV.csv:
# Name,   Type, SubType, Offset,  Size, Flags
nvs,      data, nvs,     0x9000,  0x5000,
otadata,  data, ota,     0xe000,  0x2000,
app0,     app,  ota_0,   0x10000, 0x330000,
app1,     app,  ota_1,   0x340000,0x330000,
spiffs,   data, spiffs,  0x670000,0x190000,
There are to app partitions of same size, the second used for OTA.

ThomasWaldmann, 2020-04-14:
A 8MB partition layout (intended for wifi stick device) obviously does not fit on a 4MB flash (like present on a wifi kit device).

rexfue, 2020-04-14:
Doch, der WiFi Kit hast auch 8 MB. Teste das mit dem esptool:
esptool.py --chip esp32 flash_id
Da kommt dann: Detected flash size: 8MB

ThomasWaldmann, 2020-04-14:
```
$ esptool.py --chip esp32 flash_id
esptool.py v2.5.1
Found 1 serial ports
Serial port /dev/ttyUSB0
Connecting....
Chip is ESP32D0WDQ6 (revision 1)
Features: WiFi, BT, Dual Core, 240MHz, VRef calibration in efuse
MAC: 3c:71:bf:4d:a5:e4
Uploading stub...
Running stub...
Stub running...
Manufacturer: ef
Device: 4016
Detected flash size: 4MB
Hard resetting via RTS pin...
```

rexfue, 2020-04-14:
OK, then buy a new one. The new ones have 8 MB!!

ThomasWaldmann, 2020-04-14:
That doesn't solve the issue for everybody who has a 4MB one.

rexfue, 2020-04-14:
I'd risk it - there are only a few. And they can live with the current version.
On the other hand you can of course try to solve the problem - I don't have time for that right now.

ThomasWaldmann, 2020-04-14:
Solution (Arduino IDE):
- Board: **Heltec Wifi Stick**
- Flash size: **4MB (32Mb)**
- Partition Scheme: **minimal SPIFFS (large APPS with OTA)**

```
$ cat ~/.arduino15/packages/esp32/hardware/esp32/1.0.4/tools/partitions/min_spiffs.csv

# Name,   Type, SubType, Offset,  Size, Flags
nvs,      data, nvs,     0x9000,  0x5000,
otadata,  data, ota,     0xe000,  0x2000,
app0,     app,  ota_0,   0x10000, 0x1E0000,
app1,     app,  ota_1,   0x1F0000,0x1E0000,
spiffs,   data, spiffs,  0x3D0000,0x30000,
```

As seen at the offsets/sizes used, the "minimal SPIFFS (large apps with OTA)" is a layout for **4MB** flash devices.

rexfue, 2020-04-14:
OK, that's a possible solution. But the we have two different binaries again :-(

ThomasWaldmann, 2020-04-14:
Does the .bin file exported by the Arduino IDE include a FULL image?

My impression was that it rather only has the contents for the code partition?

And that an OTA update using that .bin file **only** updates the code in 1 OTA partition.

rexfue, 2020-04-14:
No, don't think so. Arduino .bin is only the app. Therefore the long long line that the ide uses to flash (boot partition, partition scheme, app ...).

Closed 2020-04-14.

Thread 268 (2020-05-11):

tries to send after reset w/o connected to WiFi

rexfue, 2020-05-11:
after reset, the program starts more or less immediately sending to the servers, not waiting for wifi connection. This happens not at every reset, but on many (like, every other time).
I'll do a PR to wait for wifi before sending

ThomasWaldmann, 2020-05-11:
Maybe just rearrange the `wifi_status` code inside the `loop`.

Only call `transmit` if `wifi_status` or TBD `lora_status` indicates a connection.

ThomasWaldmann, 2020-05-11:
guess this might be a timing effect. before the HV charging changes, the initial charging ran within main code (and took some time to complete - maybe enough so the wifi usually had connected until afterwards).

now the HV charging always runs in background, so it reaches the transmit code earlier.

rexfue, 2020-05-11:
Yeah, that may be the reason. PR is out

ThomasWaldmann, 2020-05-11:
the `transmit` code in multigeiger.ino waits one `MEASUREMENT_INTERVAL` (150s) before sending anything. so, this issue should not happen at all except if you wifi takes longer than that to connect.

rexfue, 2020-05-11:
No, it doesn't look like that.  Measured about 2.5 sec:
```
Setting up AP: ESP32-16752040
Use password: ESP32Geiger
AP IP address: 192.168.4.1
State changed from: 0 to 2
GEIGER: -------------------------------------------------------------------------------------------------
GEIGER: Simple Multi-Geiger, Version V1.13.1-dev
GEIGER: -------------------------------------------------------------------------------------------------
GEIGER: GMC_counts Time_difference Count_Rate Dose_Rate HV Pulses Accu_GMC Accu_Time Accu_Rate Accu_Dose
GEIGER:   [Counts]            [ms]      [cps]   [uSv/h]       [-] [Counts]      [ms]     [cps]   [uSv/h]
GEIGER: -------------------------------------------------------------------------------------------------
GEIGER: current time: 1970-01-01T00:00:01
GEIGER: Measured GM: cpm= 0 HV=0
GEIGER: Sending to Madavi ...
GEIGER: http request body:
{
 "software_version": "V1.13.1-dev",
 "sensordatavalues": [
  {"value_type": "Si22G_counts_per_minute", "value": "0"},
  {"value_type": "Si22G_hv_pulses", "value": "0"},
```

ThomasWaldmann, 2020-05-11:
I don't see 2.5s there.

rexfue, 2020-05-11:
stopped time from reset to sending

ThomasWaldmann, 2020-05-11:
But maybe the `static int last = millis()` does not work like I assumed it does.
Because of the `static` I assumed that millis() call is done **once only** and **at program start time**, not at function call time.

rexfue, 2020-05-12:
And what do we do now? Can you fix that? So I can delete my PR then.

ThomasWaldmann, 2020-05-12:
I read some language docs and they confirmed that local static vars (should) work as I assumed.
I'll try to find out more later today.

rexfue, 2020-05-12:
👍

Closed 2020-05-15.

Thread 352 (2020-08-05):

Info to users about recurring reboots

t-pi, 2020-08-05:
In the Slack, there's currently a discussion about (among other topics) the reboots with a (non-developer) user. It would be good to mention the current recurring reboots in our documentation about V1.14, wouldn't it?

M-a-r-i-a-n-n-e, 2021-03-20:
@ThomasWaldmann  @WwwBoehriDe Is there already a workaround or a fix for this issue?

ThomasWaldmann, 2021-03-20:
In the last BBB meeting, we noticed that there is arduino-esp32 1.05 out now since ~3 weeks.

Maybe they fixed the problem in the updated HTTPClient code.

M-a-r-i-a-n-n-e, 2021-03-20:
I don't think so, as I already compiled it with framework-arduinoespressif32 3.10005.210308 (1.0.5) cf. https://github.com/espressif/arduino-esp32/releases

M-a-r-i-a-n-n-e, 2021-03-20:
Is there any workaround? Is the root cause already known?

ThomasWaldmann, 2021-03-20:
See #314. This issue is just about writing some docs, notifying the users - not about the crash and its root cause.

ThomasWaldmann, 2021-03-20:
I thought about this. If a user encounters an issue, expectation is that the issue tracker on github is checked whether the issue is known (which is the case here, see #314) and if not, file a new issue.

Thus, there is nothing to do here.

M-a-r-i-a-n-n-e, 2021-03-20:
@ThomasWaldmann You think that a defect that leads to a restart every second is unworthy of a line in the documentation? Interesting.

ThomasWaldmann, 2021-03-21:
I don't have restarts every second.

ThomasWaldmann, 2021-03-21:
@M-a-r-i-a-n-n-e maybe you(?) have a different issue - then we need a new github issue with tracebacks similar to the ones you see in #314 (IF they are different from the ones in #314).

M-a-r-i-a-n-n-e, 2021-03-21:
> @M-a-r-i-a-n-n-e maybe you(?) have a different issue - then we need a new github issue with tracebacks similar to the ones you see in #314 (IF they are different from the ones in #314).

Yes, unfortunately this seems to be the case, although I just followed the simple steps in https://multigeiger.readthedocs.io/en/latest/development.html#flashing-devices-creating-binaries (and of course installed the libraries using the library manager).

ThomasWaldmann, 2021-03-21:
@M-a-r-i-a-n-n-e try that: https://github.com/ecocurious2/MultiGeiger/releases/tag/V1.15.0

M-a-r-i-a-n-n-e, 2021-03-21:
@ThomasWaldmann Thank you for the new release! It first hurt my ears, because as long as I didn't erase the ESP32 memory it beeps at full volume, but after erasing the memory with the ESP32 Download Tool, it runs like a charm! 🙂👍

Closed 2021-03-20.

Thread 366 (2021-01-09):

Missing BOM / Clarification for Capcitors neede (Rastermass value)

umweltsensor, 2021-01-09:
Hi There

Wonderful project you have here, thanks for all the effort you all put in!

The original (and meanwhile outdated) BOM found here http://www.boehri.de/elektronik/MultiGeiger/MultiGeiger.xls used a ceramic cap. The list found in the Aufbauanleitung https://github.com/ecocurious2/MultiGeiger/blob/master/docs/Bauanleitung/Aufbauanleitung.pdf gave me some hints, but no specific model numbers are given.

So I am searching for an up to date BOM (Bill of Material). Is there a list with detailed specifications of all parts? I'm missing the specs of the condensators C1 to C4 especially for C2 (that is RM5 = 5mm pin spacing, measured in the eagle board file).

For C2 would go for this one: https://www.reichelt.com/ch/de/folienkondensator-10nf-1000v-rm7-5-mks4-1000-10n-p172943.html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

It a 10nF / 1000V WIMA capacitor with 7.5mm pin spacing probably fitting in the holes. Couldn't find a RM5 version of C2 on reichelt.

Cheers!

ThomasWaldmann, 2021-01-10:
such stuff should live in the git repo, preferably in a non-binary format.

umweltsensor, 2021-01-10:
OK, I'm on it. I'll create a txt tab delimited BOM and create a pull request.

umweltsensor, 2021-01-10:
Pull request created (https://github.com/ecocurious2/MultiGeiger/pull/369). Please check if nothing is missing or wrong.

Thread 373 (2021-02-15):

LoRaWan Version 1.14.0 Failure

perpaul, 2021-02-15:
After installing above version on a Wireless Stick and after several loops the controller stopped with the error message "...\libraries\MCCI_LoRaWAN_LMIC_library\src\lmic\radio.c:1065". Research on google reveals that it may be a hardware problem. The Wireless Stick is new and out of the box. A second  stick shows the same error.
How can I fix the problem?
Best regards
Paul.

rexfue, 2021-02-17:
@perpaul To be able to help I need a little more information:  what do you mean with 'after several loops'? Where do you see this error message? And what is your IDE (arduino or platformio)?

perpaul, 2021-02-17:
We use Arduino IDE and see the errormessage on the serial console. By loop we mean the transmission to TTN after several measurements. The multigeiger continues to measure after the crash what we can be seen in the display and on the ticks. We are currently testing version 3.1 of the MCCI_LoRaWAN_LMIC_library to see whether this solves the problem.

rexfue, 2021-02-17:
OK.  We have never had this error. Maybe the new library helps. Please keep us up to date.

perpaul, 2021-02-21:
Following the response of Terry Moore, the developer of the MCCI LoRaWAN LMIC library for your info:

Looking at the sketch, I would say that you can remove the calls to LMIC_setupChanne(); they’re not needed, and will be overridden by TTN during join. Also, you can’t change channels 0-2 in EU868; the LMIC ignores this – it certainly won’t let you change frequencies or bands, and at least one of 0-2 is BAND_MILLI. But this is not your problem.
LMIC_setTxData2() returns errors (it returns lmic_tx_error_t); please check the docs, and use its results. The logic in lorawan_send() is trying to duplicate work that the LMIC already does, and therefore is risky. In older versions of the LMIC, it might have been required, but with v3.3.0 it’s not advisable or required. In my experience, the LMIC is now very good about always either transmitting your data or reporting an error status.
I would not call LMIC_setLinkCheckMode(0) – in most cases the device and the network works better if linkcheck mode is enabled. In addition, it’s very important for handling the TTN V2 -> V3 transition. Furthermore, the comment “slow data rates change max TX size” misses the key point about v3.3.0 – the LMIC automatically increases the DR on transmit if the message is too big for the current DR. (If this is not desirable, you must call LMIC_setTxData2_strict().)
Setting LMIC.dn2Dr is normally not required.
If you’re going to call LMIC_setDrTxpow(), it should be called after join complete; and it’s not a bad idea to do so.
However, the key point is this:
Always call os_runloop_once() in your loop() routine. This must be done without fail, because the MAC can keep going (and will keep going) even after a transmit completes. As far as I can tell, the code only does this while a TX is pending. Not a safe optimization because the network can keep the LMIC busy arbitrarily long. (A lot longer, I must add, in TTN V3, because the RX window is now 5 seconds – each mac downlink can cause a mac uplink, which means things can go on for quite a while.)

perpaul, 2021-02-21:
Here an additional post from Terry:

I see that the opmode is 0x118 at the point of failure; this is a rare case where the debug prints are helpful (though it’s better to print these outside the LMIC). This means that a poll was pending (bit 4 is set, OP_POLL).
I think this means that the state tracking (in onEvent()) is getting confused.
This can happen if you try to send while the LMIC is busy dealing with downlink messages.
This can in turn happen after a lot of uplinks, because TTN may decide to send MAC downlinks. But the LMIC sends EV_TXCOMPLETE as soon as it knows your message has been sent and the RX slots have been process. This may be before mac processing is complete. So EV_TXCOMPLETE can’t be used as evidence that the mac is ready for a new message.
The comment says that you’re not honoring TTN fair use, so I gather that you might be transmitting fairly often?
I think you may have found a bug in the LMIC; it appears to me at the moment that LMIC_setTxData() needs to check whether any of (OP_POLL | OP_TXDATA | OP_TXRXPEND) are set.
So you should try:
if (LMIC.opmode & (OP_POLL | OP_TXDATA | OP_TXRXPEND)) {
   // don't transmit, LMIC is probably busy

Closed 2021-03-04.

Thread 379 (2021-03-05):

Reflashed device - no connection to AP possible

dl2sba, 2021-03-05:
I've reflashed my Multigeier and I'm no longer able to connect to the AP as well the ESP32 didn't connect to my WLAN.

```
19:43:28.728 -> GEIGER: Logging initialized at level 0.
19:43:29.147 -> GEIGER: Switches: SW0 speaker_on 1,  SW1 display_on 1,  SW2 led_on: 1,  SW3 ble_on: 1
19:43:29.194 -> GEIGER: BME_Status: not found
19:43:29.194 -> Config size: 179
19:43:29.194 -> Wrong config version.
19:43:29.194 -> E (688) MCPWM: /home/runner/work/esp32-arduino-lib-builder/esp32-arduino-lib-builder/esp-idf/components/driver/mcpwm.c:190 (mcpwm_set_duty_type):MCPWM DUTY TYPE ERROR
19:43:29.194 -> E (695) MCPWM: /home/runner/work/esp32-arduino-lib-builder/esp32-arduino-lib-builder/esp-idf/components/driver/mcpwm.c:190 (mcpwm_set_duty_type):MCPWM DUTY TYPE ERROR
19:43:29.241 -> GEIGER: -------------------------------------------------------------------------------------------------
19:43:29.241 -> GEIGER: Simple Multi-Geiger, Version V1.15.0-dev
19:43:29.241 -> GEIGER: -------------------------------------------------------------------------------------------------
19:43:29.288 -> GEIGER: GMC_counts Time_difference Count_Rate Dose_Rate HV Pulses Accu_GMC Accu_Time Accu_Rate Accu_Dose
19:43:29.288 -> GEIGER:   [Counts]            [ms]      [cps]   [uSv/h]       [-] [Counts]      [ms]     [cps]   [uSv/h]
19:43:29.288 -> GEIGER: -------------------------------------------------------------------------------------------------
19:43:29.336 -> AP password was not set in configuration
19:43:29.336 -> State changing from: 0 to 1
19:43:29.429 -> Setting up AP: ESP32-7936376
19:43:29.429 -> With default password: <hidden>
19:43:29.429 -> AP IP address: 192.168.4.1
19:43:29.429 -> State changed from: 0 to 1
19:43:40.493 -> GEIGER:         17           11587   1.467161  0.119483        27       17     11587  1.467161  0.119483
19:43:40.586 -> Connection to AP.
19:43:44.604 -> Disconnected from AP.
19:43:50.475 -> GEIGER:         20           10160   1.968504  0.160312         3       37     21747  1.701384  0.138558
19:44:00.482 -> GEIGER:         18            9860   1.825558  0.148671         1       55     31607  1.740121  0.141713
19:44:10.456 -> GEIGER:         20            9884   2.023472  0.164789         2       75     41491  1.807621  0.147210

```
I've tried it with an iPhone and a WindowsPC to connect to the AP - no success :-(

Any ideas?

//Dietmar

rexfue, 2021-03-05:
@dl2sba:  Which version did the multigeiger have before? The 1.15. is a developer version. Which IDE did you use to compile this? When did you download the source code?
Maybe, you use the wrong password?  We can discuss further by PM (rexfue@gmail.com), I will summarize this here later.

ThomasWaldmann, 2021-03-06:
```
19:43:29.336 -> AP password was not set in configuration
19:43:29.429 -> Setting up AP: ESP32-7936376
19:43:29.429 -> With default password: <hidden>
```

Tried that ESSID with the default password?

dl2sba, 2021-03-06:
Now used 1.14.0 from releases

```
04:53:34.645 -> rst:0x1 (POWERON_RESET),boot:0x37 (SPI_FAST_FLASH_BOOT)
04:53:34.645 -> flash read err, 1000
04:53:34.645 -> ets_main.c 371
04:53:35.015 -> ets Jun  8 2016 00:22:57
04:53:35.015 ->
04:53:35.015 -> rst:0x10 (RTCWDT_RTC_RESET),boot:0x17 (SPI_FAST_FLASH_BOOT)
04:53:35.015 -> configsip: 0, SPIWP:0xee
04:53:35.015 -> clk_drv:0x00,q_drv:0x00,d_drv:0x00,cs0_drv:0x00,hd_drv:0x00,wp_drv:0x00
04:53:35.063 -> mode:DIO, clock div:1
04:53:35.063 -> load:0x3fff0018,len:4
04:53:35.063 -> load:0x3fff001c,len:1044
04:53:35.063 -> load:0x40078000,len:8896
04:53:35.063 -> load:0x40080400,len:5816
04:53:35.063 -> entry 0x400806ac
04:53:35.620 -> GEIGER: Logging initialized at level 1.
04:53:36.080 -> GEIGER: BME_Status: not found
04:53:36.080 -> Config size: 177
04:53:36.080 -> Wrong config version.
04:53:36.080 -> E (671) MCPWM: /home/runner/work/esp32-arduino-lib-builder/esp32-arduino-lib-builder/esp-idf/components/driver/mcpwm.c:190 (mcpwm_set_duty_type):MCPWM DUTY TYPE ERROR
04:53:36.080 -> E (678) MCPWM: /home/runner/work/esp32-arduino-lib-builder/esp32-arduino-lib-builder/esp-idf/components/driver/mcpwm.c:190 (mcpwm_set_duty_type):MCPWM DUTY TYPE ERROR
04:53:36.125 -> AP password was not set in configuration
04:53:36.125 -> State changing from: 0 to 1
04:53:36.215 -> Setting up AP: ESP32-7936376
04:53:36.215 -> With default password: <hidden>
04:53:36.215 -> AP IP address: 192.168.4.1
04:53:36.215 -> State changed from: 0 to 1

```
Same behaviour with the AP no luck on ESP32-7936376 / ESP32Geiger.
In the 1.15dev version at least the GMC is running. In 1.14.0 no ticks etc.
I've build the GMC during the Session on 08.02.20 in Sindelfingen. No idea which version was flashed.

dl2sba, 2021-03-06:
Reflashed with complete new ESP32 firmware - works now again - sorry for irritation!

Closed 2021-03-06.

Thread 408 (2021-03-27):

use newer arduino-esp32

ThomasWaldmann, 2021-03-27:
short after the 1.0.5 release (~3w ago), there is now a 1.0.6 release based on IDF release/v3.3.5 85c43024c.

https://github.com/espressif/arduino-esp32/releases/tag/1.0.6

if there is no regression, we should do next release based on this.

ThomasWaldmann, 2021-03-27:
@rexfue please update with any insights after trying it out.

ThomasWaldmann, 2021-03-27:
upgraded to 1.0.6 and flashed again:
- boards.txt needed patching again (see `misc/arduino-esp32/...` in our repo) - the patch still applies cleanly
- after that, flashing from arduino ide worked again and multigeiger is ticking normally
- did not do http data uploading tests yet...

rexfue, 2021-03-27:
Don't know what happened, I can't get a stable WLAN connection with the normal Heltec Kit. Only the Wireless Stick connects easily and stable. I need to investigate further - but I cannot continue until later next week.

M-a-r-i-a-n-n-e, 2021-03-28:
@rexfue Same here. Just to be sure, I played around with delay and yield and threw the Lora-related Code out and built it with the original board environment, but it did not help. I also tried it with VSCode as well as with the Arduino IDE.
@ThomasWaldmann why should I patch the boards.txt? As far as I know I just have to configure it again and that's it?

I also tried other versions of espressif32 and they did not work either. Can someone provide an old binary that really worked on the Heltec WiFi Kit 32 v2? (The binary @WwwBoehriDe  flashed did not work very well for me and all newer versions I tried in the previous weeks lead to WiFi connection losses more or less frequently. My settings always were: no sound, local password set, WiFi set, upload to both destinations.)

ThomasWaldmann, 2021-03-28:
@M-a-r-i-a-n-n-e the patching is needed so one can set the partitioning from the arduino IDE's menu, see the .txt in the same directory as the patch (`misc/arduino-esp32/...`). It's required for the **generic** release-binary building.

M-a-r-i-a-n-n-e, 2021-03-29:
@ThomasWaldmann Which of your binaries is 100% sure to work with WiFi on the WiFi Kit?

Regarding the patch: unfortunately, it changes nothing for me. From you manual, I cannot select:

> Flash size: “4MB(32Mb)”

ThomasWaldmann, 2021-03-29:
@M-a-r-i-a-n-n-e AFAIK, selecting the flash size is not needed as it is autodetected. At least that worked for my 4MB device.

For more infos, please read: https://github.com/ecocurious2/MultiGeiger/blob/master/misc/arduino-esp32/partition-menu-1.0.5.txt

M-a-r-i-a-n-n-e, 2021-03-29:
ok, well, then I have no idea, because your binaries from github also do not lead to a stable WiFi connection (tried it down to 1.13.0 already).

ThomasWaldmann, 2021-04-09:
From last meeting: people have issues with 1.0.6 and wifi, so let's continue with 1.0.5 for now.

ThomasWaldmann, 2021-05-08:
So, 1.15.0 and 1.15.1 releases were / will be made with arduino-esp32 1.0.5.

Later releases should either stay on 1.0.5 or use something > 1.0.6.

Seems like arduino-esp32 devs are working on a 2.0 release (only alphas yet).

M-a-r-i-a-n-n-e, 2021-05-15:
I just tried it again with the current code and until now WiFi works well.

ThomasWaldmann, 2021-05-15:
You mean 1.15.1 release?

M-a-r-i-a-n-n-e, 2021-05-15:
Just the master branch.

M-a-r-i-a-n-n-e, 2021-05-16:
@ThomasWaldmann Out of curiosity I also tested your 1.15.1 release binary. It still fails to connect to WiFi at all, so I do not understand why framework-arduinoespressif32 <3.2.0 (1.0.5) should be better than 3.2.0 (1.0.6). Compiling with previous versions (3.1.1, 3.1.0, 3.0.0, ...) did not work for me, as WiFi was unstable for my two WiFi Kit 32.

Compiling with [framework-arduinoespressif32 3.2.0 (1.0.6)](https://github.com/platformio/platform-espressif32/releases) in VScode works for me, so I can give my Multigeigers another try.

ThomasWaldmann, 2021-05-16:
@M-a-r-i-a-n-n-e 1.0.5 being better than 1.0.6 is what i got from the first few posts in this ticket (including one from you) and also from feedback in a jitsi meeting.

t-pi, 2021-05-16:
Apparently the Arduino BLE stack also did his part in thwarting the stability... Since the move to NimBLE lib, both my MultiGeigers run rock-stable (no reboots anymore, the normally-on is currently at BLE packet counter 18424, i.e. ~51h run time and by my guess it has rolled over once already...)

M-a-r-i-a-n-n-e, 2021-05-17:
@t-pi In March, I even removed all BLE references from the code and as I wrote above, I could compile no version with stable WiFi at all and even the older version that @WwwBoehriDe initially flashed for me had issues with WiFi. So I guess that mainly the new framework-arduinoespressif32 did the trick for me. I'm really glad it works!

ThomasWaldmann, 2021-05-19:
OK, so I guess I'll make a new release soon, with:
- arduino-esp32 1.0.6 release based on IDF release/v3.3.5 85c43024c.
- nimBLE and IotWebConf update from master

I also linked a new patch from the crash-reboot ticket #314, could try to get that in also.

Does that sound good to everybody concerning WiFi stability?

ThomasWaldmann, 2021-05-20:
https://github.com/espressif/arduino-esp32/issues/4980#issuecomment-844736582 < notable.

ThomasWaldmann, 2021-06-03:
https://ecocurious.slack.com/archives/CGBLH04GJ/p1622141846004600 < t.pi: 1.0.6 + nimBLE + local alarm PR uptime >= 7d.

ThomasWaldmann, 2021-08-15:
Building release 1.16.0 with arduino-esp32 1.0.6 now...

Closed 2021-08-15.

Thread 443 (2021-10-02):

Help with a project based on this: is my Schematic wrong?

Johannes-ece, 2021-10-02:
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
Is this is not the right site for asking the question, I am sorry. I think I don´t get a high signal from the Cap_Full but I cant explain why.
Geiger in is the + pole and Geiger out the -.

rexfue, 2021-10-02:
Hello, your schematic look OK. What types (values) are the diodes D1, D2 and D3 ? They all should be zener diodes, D1 and D2  ZY200 and D3 BZX55 3V3. Hope, that helps.

ThomasWaldmann, 2021-10-02:
Tagged this as question and wontfix, because it is not an issue of the multigeiger.

ThomasWaldmann, 2021-10-02:
C2: 10 or 100nF? Same for C3.

R1: 1W, really? for what?

If you measure resistance over R1, is it really 10kOhm?

Johannes-ece, 2021-10-03:
Ok, so I checked all the parts values again and they math the ones in the partlist from here: https://github.com/ecocurious2/MultiGeiger/tree/master/docs/hardware
to test the circuit I tried to use this Arduino sketch with a different baud rate: https://www.boehri.de/elektronik/Simple_Arduino_Geiger/Simple_Adruino_Geiger.ino
I put some prints in the interrupt to check when they are triggered, and the GMZ_capacitor_full interrupt never triggers, the GMZ_count interrupt subsequently also never triggers.
I know this isn´t exatly this github´s scope, but my circuit also messures co2 and fine particles so I made a custom circuit board.
So thank you so much for your help

WwwBoehriDe, 2021-10-04:
To me everything looks fine. If you have used the components we use, it should work: https://github.com/ecocurious2/MultiGeiger/blob/master/docs/hardware/MultiGeiger_Partlist.ods. The partselection is critical. For example regaring leakagecurrents of the caps and maximum voltage of our coil (happyly it widstands 400 V - even though it is not specified   :-(   ).
Do you have leakage-currents? For example weakly conductive flux from soldering? This could be one problem. If yes: Cleaning with alcohol could help. I normally debug the HV-Part like this: Remove R2 - just to be sure that no current escapes on that path. Write a sketch that generates always pulses on the HF_FET_OUT. Now you should see a voltage on C3. I use a 1 G Ohm Pre-Resistor on my voltmeter. Otherwise the Voltage could drop - our voltage-generation is quite weak. The voltage schould be about 403 V. And you should see the voltage seperation on the Z-Diodes accordingly: 200 V, 200 V, 3.3 V - so the HV_CAP_FULL should deliver a 3.3 V High-Level.
I hope this helps for the first time. Best regards  Juergen

WwwBoehriDe, 2021-10-05:
Hi,
well with a multimeter it is not easy to debug. But anyhow - it already looks like if you are on the right path.

OK, 360 V on C3 looks half-good. Yes, probably it breaks down if you touch it with your multimeter - but we don't know. I would recommend first to try to generate 203 V for a trial. So if you short circuit D1 you should see 203 V on C3.

If this works there should be a short current pulse through D1, D2, D3. And this pulse would generate a short voltage-spike on D3 (= HV_CAP_FULL). But measuring that with a multimeter is not possible. Probably, if you're happy, you would see the average voltage - so maybe 0,1 Volts - but probably you don't see anything. But these spikes should be capable to trigger the interrupt of your Arduino.

I hope this helps. Good luck. Best regards    Juergen

Johannes-ece, 2021-10-17:
I think it works!
I tried 3 diffrent pcbs and it seems like two of them had a little short somewhere.
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
Only the HV Pulses on the far right don't make sense to me, I expected more.

Thank you so much for all your help!

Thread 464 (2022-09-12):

support of platformio: E (554) spi_flash: Detected size(4096k) smaller than the size in the binary image header(8192k).

rwe17, 2022-09-12:
I'm trying to build and upload the Multigeige v1.16.0 firmware into a Heltec wifi_kit_32 device using the Platformio IDE.

Unfortunately, from the documentation i only found a way using the Arduion IDE which does not work on my Linux machine, because of several compilation issues event though i imported all required libraries and applied the patch file.

For me it seem more easy and logical to use Platformio and a `platformio.ini` file that describes all prerequisites upfront. After solving the issue with the redundant `hal_init()` function, i was able to upload the firmware into my esp32 board. Unfortunately, the defined [board configuration](https://docs.platformio.org/en/latest/boards/espressif32/heltec_wireless_stick.html) in platformio.ini `board = heltec_wireless_stick` obviously does not fit to the hardware, because this board defines a 8 MB Flash size and my board has 4MB which results in endless reboots showing this error:

```
Rebooting...
ets Jun  8 2016 00:22:57

rst:0xc (SW_CPU_RESET),boot:0x17 (SPI_FAST_FLASH_BOOT)
configsip: 0, SPIWP:0xee
clk_drv:0x00,q_drv:0x00,d_drv:0x00,cs0_drv:0x00,hd_drv:0x00,wp_drv:0x00
mode:DIO, clock div:2
load:0x3fff0030,len:1184
load:0x40078000,len:13132
load:0x40080400,len:3036
entry 0x400805e4
E (554) spi_flash: Detected size(4096k) smaller than the size in the binary image header(8192k). Probe failed.

assert failed: do_core_init startup.c:298 (flash_ret == ESP_OK)
```

Based on this results i have three questions:
a) Is it possible to configure the configuration platformio.ini to coerce the flashing tool to create 4MB fash size packages for the board heltec_wireless_stick? (applying `board_build.partitions = min_spiffs.csv` as described in #449 does not solve the issue.)
b) When changing the platformio.ini to `board = heltec_wifi_kit_32` i run into several compilation issues. Is it possible to fix that in the source code? I guess when selecting the proper board, the firmware will run and start without infinite reboots.
c) In case Platformio is not an option because its to difficult for the existing code, is it possible to upload the binary release file just via a tool from the command line? Which tool is required and how should i call that?

Any support is appreciated to get the stuff running on my heltec wifi_kit_32.

Regard
Ralf

rexfue, 2022-09-13:
Please send me (rxf@gmx.de) an email. I will try to answer your questions by mail. After solving the issues i will post the results here.

rwe17, 2022-09-18:
Ok, my board is now running - thanks to the support of rexfue!

Let's tell the long story short:

__4MB Flash size:__
* I bought an "old" heltec `wifi_kit_32` that supports only 4MB flash size.
* The platformio-example.ini specifies the `heltec_wireless_stick` that has configured a 8MB flash size
* To solve that, you need to specify the board `heltec_wifi_lora_32` (which reflects my old heltec device) and you need to add the `board_build.partitions = min_spiffs.csv`

__Endless Rebooting:__
After this was fixed and the firmware could be uploaded into my old heltec esp32, the device restarted in an infinit loop.
* The reason for that behavior was a too new _espressif32_ platform version i've used as default in my Platformio. This too new platform version caused a `Guru Meditation Error: Core  1 panic'ed (LoadProhibited)` when setting up the interrupt routines for the tube.
* To fix that you just need to specify explicitly the version 3.5.0: `platform = espressif32@3.5.0`

So at the end, my platformio.ini [env:geiger] section looks like that:

```
[env:geiger]
# select 'heltec_wifi_lora_32' to support the "old" 4Mb Heltec wifi_kit_32
board = heltec_wifi_lora_32
board_build.partitions = min_spiffs.csv
build_flags =
  -D CFG_eu868=1
  -D CFG_sx1276_radio=1
  -D ARDUINO_LMIC_PROJECT_CONFIG_H_SUPPRESS=1
  -D hal_init=LMICHAL_init # handles multiple hal_init()
# stick to 3.5.0, because newer versions cause an issue when setting up the interrupt routines
platform = espressif32@3.5.0
framework = arduino
monitor_speed=115200
lib_deps=
  U8g2
  Adafruit BME680 Library@^2.0.0
  Adafruit BME280 Library
  Adafruit Unified Sensor
  IotWebConf@^3.1.0
  MCCI LoRaWAN LMIC library
  h2zero/NimBLE-Arduino
```

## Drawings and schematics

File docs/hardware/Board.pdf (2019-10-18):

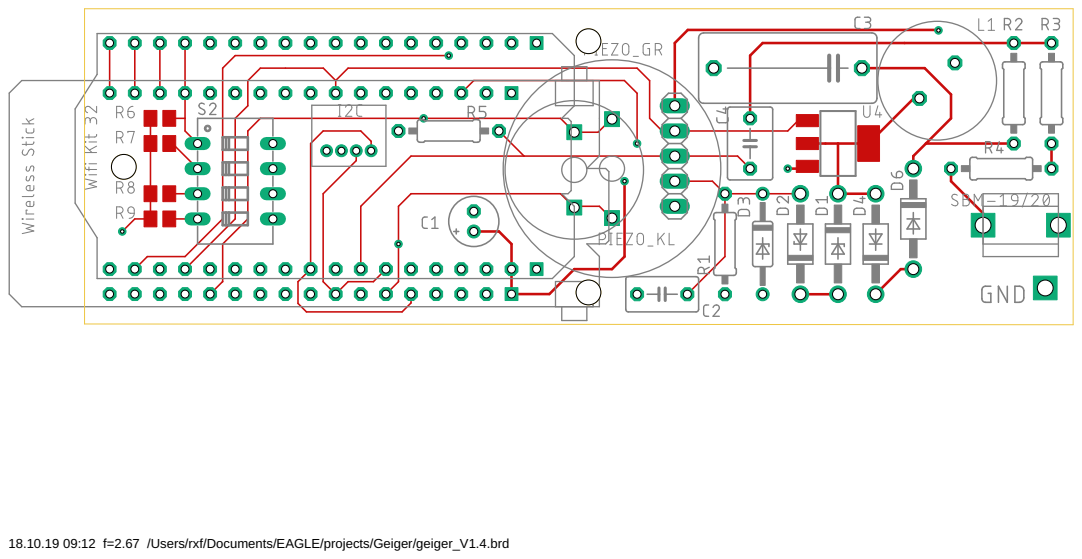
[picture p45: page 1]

18.10.19 09:12 f=2.67 /Users/rxf/Documents/EAGLE/projects/Geiger/geiger_V1.4.brd

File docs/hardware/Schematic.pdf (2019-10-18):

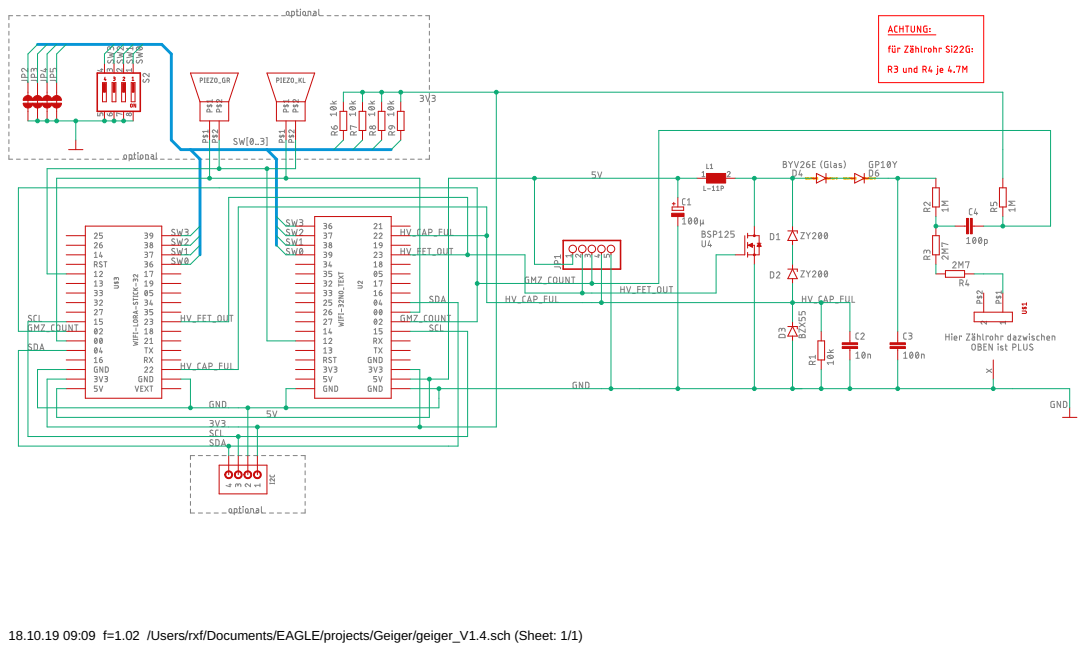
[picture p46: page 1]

18.10.19 09:09 f=1.02 /Users/rxf/Documents/EAGLE/projects/Geiger/geiger_V1.4.sch (Sheet: 1/1)

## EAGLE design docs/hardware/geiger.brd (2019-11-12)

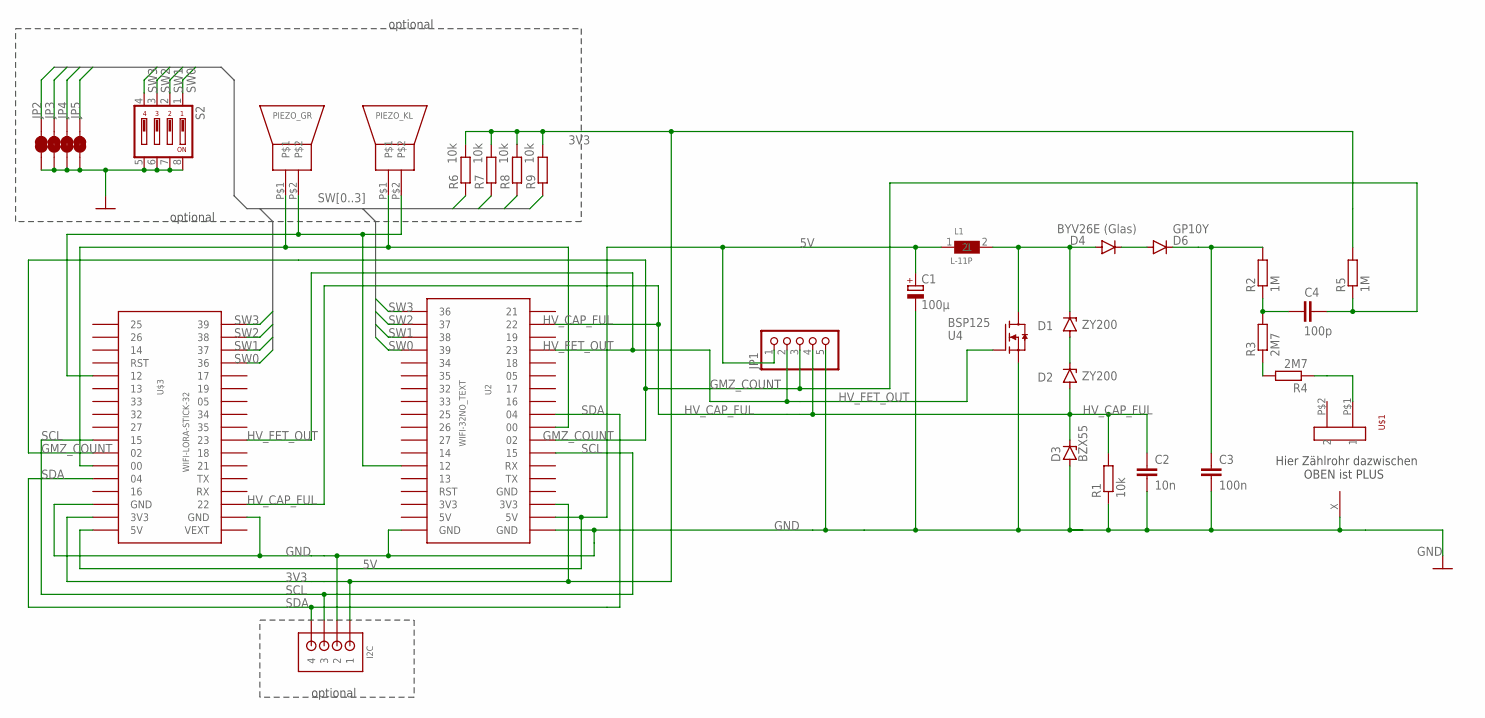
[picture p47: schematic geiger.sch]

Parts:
C1: 100µ; E2-5
C2: 10n; C050-035X075
C3: 100n; C150-072X183
C4: 100p; C050-045X075
D1, D2: ZY200; DO41Z10
D3: BZX55; DO35Z10
D4: BYV26E (Glas); DO41-10
D6: GP10Y; DO41-10
I2C: B4B-ZRSIDE_ENTRY; S4B-ZR
JP1: PINHD-1X5; 1X05
JP2: Jumper; SMT-JUMPER_2_NC_TRACE_NO-SILK
JP3, JP4, JP5: JUMPER-SMT_2_NC_TRACE_NO-SILK; SMT-JUMPER_2_NC_TRACE_NO-SILK
L1: L-11P
PIEZO_GR: PIEPSER_BIG
PIEZO_KL: PIEPSER
R1: 10k; 0207/10
R2, R5: 1M; 0207/10
R3, R4: 2M7; 0207/10
R6, R7, R8, R9: 10k; M0805
S2: DIP04YL
U2: WIFI-32NO_TEXT; 2.54MM_2X18_NOLORA_NOTEXT
U4: BSP125; SOT223
U$1: FUSE_HOLDER
U$3: WIFI-LORA-STICK-32; 2.54MM_2X18_STICK_NO_TEXT
U$5: ONE_PAD

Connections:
3V3: I2C.1, R5.2, R6.2, R7.2, R8.2, R9.2, U2.P$34 (3V3), U$3.P$33 (3V3)
5V: C1.+, JP1.1, L1.1, U2.P$35 (5V), U$3.P$34 (5V)
GMZ_COUNT: C4.2, JP1.3, R5.1, U2.P$29 (02), U$3.P$28 (02)
GND: C1.-, C2.2, C3.2, D3.A, I2C.2, JP1.5, JP2.1, JP3.1, JP4.1, JP5.1, R1.1, S2.5, S2.6, S2.7, S2.8, U2.P$1 (GND), U2.P$36 (GND), U4.3 (S), U$3.P$2 (GND), U$3.P$32 (GND), U$5.X
HV_CAP_FUL: C2.1, D2.A, D3.C, JP1.4, R1.2, U2.P$20 (22), U$3.P$3 (22)
HV_FET_OUT: JP1.2, U2.P$22 (23), U4.1 (G), U$3.P$8 (23)
unnamed: D1.A, D2.C
unnamed: D1.C, D4.A, L1.2, U4.2 (D), U4.4 (D)
unnamed: C3.1, D6.C, R2.2
unnamed: R4.1, U$1.P$1 (1)
unnamed: R3.1, R4.2
unnamed: C4.1, R2.1, R3.2
unnamed: D4.C, D6.A
unnamed: PIEZO_GR.P$2, PIEZO_KL.P$2, U2.P$6 (12), U$3.P$22 (12)
unnamed: PIEZO_GR.P$1, PIEZO_KL.P$1, U2.P$28 (00), U$3.P$29 (00)
SCL: I2C.3, U2.P$30 (15), U$3.P$27 (15)
SDA: I2C.4, U2.P$27 (04), U$3.P$30 (04)
SW0: JP5.2, R6.1, S2.1, U2.P$15 (39), U$3.P$14 (36)
SW1: JP4.2, R7.1, S2.2, U2.P$16 (38), U$3.P$15 (37)
SW2: JP3.2, R8.1, S2.3, U2.P$17 (37), U$3.P$16 (38)
SW3: JP2.2, R9.1, S2.4, U2.P$18 (36), U$3.P$17 (39)

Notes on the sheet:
Hier Zählrohr dazwischen OBEN ist PLUS
optional

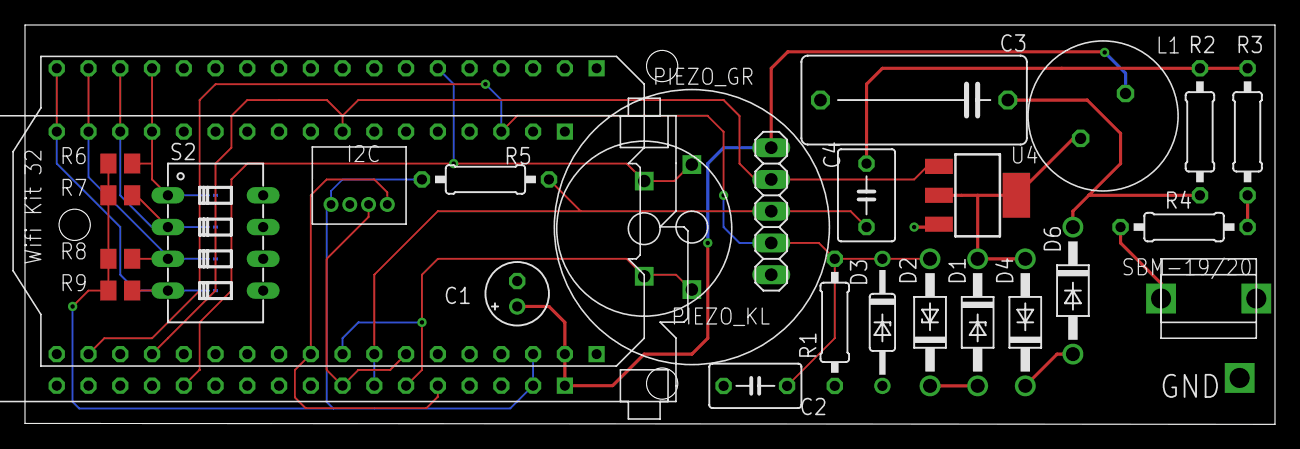
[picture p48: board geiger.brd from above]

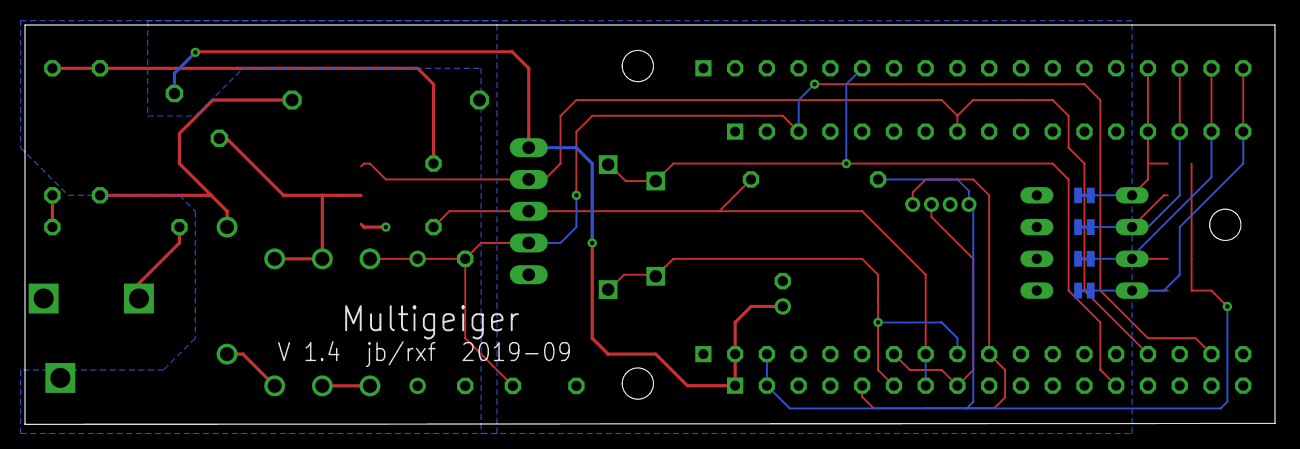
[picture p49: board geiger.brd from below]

Board: 2 copper layers, 100.0 x 31.9 mm, 33 parts (4 on the bottom side), 21 nets.

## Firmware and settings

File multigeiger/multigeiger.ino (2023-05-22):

// Project: Simple Multi-Geiger
// (c) 2019,2020 by the authors, see AUTHORS file in toplevel directory.
// Licensed under the GPL v3 (or later), see LICENSE file in toplevel directory.

#include <Arduino.h>

#include "version.h"
#include "log.h"
#include "log_data.h"
#include "userdefines.h"
#include "thp_sensor.h"
#include "tube.h"
#include "switches.h"
#include "speaker.h"
#include "webconf.h"
#include "display.h"
#include "transmission.h"
#include "ble.h"
#include "chkhardware.h"
#include "clock.h"

// Measurement interval (default 2.5min) [sec]
#define MEASUREMENT_INTERVAL 150

// Max time the greeting display will be on. [msec]
#define AFTERSTART 5000

// In which intervals the OLED display is updated. [msec]
#define DISPLAYREFRESH 10000

// Minimum amount of GM pulses required to early-update the display.
#define MINCOUNTS 100

// Target loop duration [ms]
// slow down the arduino main loop so it spins about once per LOOP_DURATION -
#define LOOP_DURATION 1000

// DIP switches
static Switches switches;


void setup() {
  bool isLoraBoard = init_hwtest();
  setup_log(DEFAULT_LOG_LEVEL);
  setup_display(isLoraBoard);
  setup_switches(isLoraBoard);
  switches = read_switches();  // only read DIP switches once at boot time
  setup_thp_sensor();
  setup_webconf(isLoraBoard);
  setup_speaker(playSound, ledTick && switches.led_on, speakerTick && switches.speaker_on);
  setup_transmission(VERSION_STR, ssid, isLoraBoard);
  setup_ble(ssid, sendToBle && switches.ble_on);
  setup_log_data(SERIAL_DEBUG);
  setup_tube();
  log(DEBUG, "All Setup done");
}

void setup_ntp(int wifi_status) {
  static bool clock_configured = false;
  if (clock_configured)
    return;

  // this is called from loop() because we do not want to block in setup().
  // it might either take a while until WiFi is ready or it might even never
  // be ready, e.g. in LoRa-based deployments or on the road using BLE.

  // a bug in arduino-esp32 1.0.4 crashes the esp32 if the wifi is not
  // configured yet and one tries to configure for NTP:
  if (wifi_status != ST_WIFI_CONNECTED)
    return;

  setup_clock(0);  // 0 == do NTP!
  // please note that time is not necessarily NTP-correct below here.
  // it might take some minutes until we have the correct time.
  // if we do not have a connection to NTP servers, it will just count up from 1970.

  clock_configured = true;
}

int update_wifi_status(void) {
  int st;
  switch (iotWebConf.getState()) {
  case iotwebconf::Connecting:
    st = ST_WIFI_CONNECTING;
    break;
  case iotwebconf::OnLine:
    st = ST_WIFI_CONNECTED;
    break;
  case iotwebconf::ApMode:
    st = ST_WIFI_AP;
    break;
  default:
    st = ST_WIFI_OFF;
    break;
  }
  set_status(STATUS_WIFI, st);
  return st;
}

int update_ble_status(void) {  // currently no error detection
  int st;
  if (sendToBle && switches.ble_on)
    st = is_ble_connected() ? ST_BLE_CONNECTED : ST_BLE_CONNECTABLE;
  else
    st = ST_BLE_OFF;
  set_status(STATUS_BLE, st);
  return st;
}

void publish(unsigned long current_ms, unsigned long current_counts, unsigned long gm_count_timestamp, unsigned long current_hv_pulses,
             float temperature, float humidity, float pressure) {
  static unsigned long last_timestamp = millis();
  static unsigned long last_counts = 0;
  static unsigned long last_hv_pulses = 0;
  static unsigned long last_count_timestamp = 0;
  static unsigned int accumulated_GMC_counts = 0;
  static unsigned long accumulated_time = 0;
  static float accumulated_Count_Rate = 0.0, accumulated_Dose_Rate = 0.0;

  if (((current_counts - last_counts) >= MINCOUNTS) || ((current_ms - last_timestamp) >= DISPLAYREFRESH)) {
    if ((gm_count_timestamp == 0) && (last_count_timestamp == 0)) {
      // seems like there was no GM pulse yet and everything is still in initial state.
      // get out of here, we can't do anything useful now.
      return;
    }
    last_timestamp = current_ms;
    int hv_pulses = current_hv_pulses - last_hv_pulses;
    last_hv_pulses = current_hv_pulses;
    int counts = current_counts - last_counts;
    last_counts = current_counts;
    int dt = gm_count_timestamp - last_count_timestamp;
    last_count_timestamp = gm_count_timestamp;

    accumulated_time += dt;
    accumulated_GMC_counts = current_counts;

    float GMC_factor_uSvph = tubes[TUBE_TYPE].cps_to_uSvph;

    // calculate the current count rate and dose rate
    float Count_Rate = (dt != 0) ? (float)counts * 1000.0 / (float)dt : 0.0;
    float Dose_Rate = Count_Rate * GMC_factor_uSvph;

    // calculate the count rate and dose rate over the complete time from start
    accumulated_Count_Rate = (accumulated_time != 0) ? (float)accumulated_GMC_counts * 1000.0 / (float)accumulated_time : 0.0;
    accumulated_Dose_Rate = accumulated_Count_Rate * GMC_factor_uSvph;

    // ... and update the data on display, notify via BLE
    update_bledata((unsigned int)(Count_Rate * 60));
    display_GMC((unsigned int)(accumulated_time / 1000), (int)(accumulated_Dose_Rate * 1000), (int)(Count_Rate * 60),
                (showDisplay && switches.display_on));

    // Sound local alarm?
    if (soundLocalAlarm && GMC_factor_uSvph > 0) {
      if (accumulated_Dose_Rate > localAlarmThreshold) {
        log(WARNING, "Local alarm: Accumulated dose of %.3f µSv/h above threshold at %.3f µSv/h", accumulated_Dose_Rate, localAlarmThreshold);
        alarm();
      } else if (Dose_Rate > (accumulated_Dose_Rate * localAlarmFactor)) {
        log(WARNING, "Local alarm: Current dose of %.3f > %d x accumulated dose of %.3f µSv/h", Dose_Rate, localAlarmFactor, accumulated_Dose_Rate);
        alarm();
      }
    }

    if (Serial_Print_Mode == Serial_Logging) {
      log_data(counts, dt, Count_Rate, Dose_Rate, hv_pulses,
               accumulated_GMC_counts, accumulated_time, accumulated_Count_Rate, accumulated_Dose_Rate,
               temperature, humidity, pressure);
    }
  } else {
    // If there were no pulses after AFTERSTART msecs after boot, clear display anyway and show 0 counts.
    static unsigned long boot_timestamp = millis();
    static unsigned long afterStartTime = AFTERSTART;
    if (afterStartTime && ((current_ms - boot_timestamp) >= afterStartTime)) {
      afterStartTime = 0;
      update_bledata(0);
      display_GMC(0, 0, 0, (showDisplay && switches.display_on));
    }
  }
}

void one_minute_log(unsigned long current_ms, unsigned long current_counts) {
  static unsigned int last_counts = 0;
  static unsigned long last_timestamp = millis();
  int dt = current_ms - last_timestamp;
  if (dt >= 60000) {
    unsigned long counts = current_counts - last_counts;
    unsigned int count_rate = (counts * 60000) / dt;
    if (((((counts * 60000) % dt) * 2) / dt) >= 1) {
      count_rate++;  // Rounding + 0.5
    }
    log_data_one_minute((current_ms / 1000), count_rate, counts);
    last_timestamp = current_ms;
    last_counts = current_counts;
  }
}

void statistics_log(unsigned long current_counts, unsigned int time_between) {
  static unsigned long last_counts = 0;
  if (current_counts != last_counts) {
    log_data_statistics(time_between);
    last_counts = current_counts;
  }
}

void read_THP(unsigned long current_ms,
              bool *have_thp, float *temperature, float *humidity, float *pressure) {
  static unsigned long last_timestamp = 0;
  // first call: immediately query thp sensor
  // subsequent calls: only query every MEASUREMENT_INTERVAL
  if (!last_timestamp || (current_ms - last_timestamp) >= (MEASUREMENT_INTERVAL * 1000)) {
    last_timestamp = current_ms;
    *have_thp = read_thp_sensor(temperature, humidity, pressure);
  }
}

void transmit(unsigned long current_ms, unsigned long current_counts, unsigned long gm_count_timestamp, unsigned long current_hv_pulses,
              bool have_thp, float temperature, float humidity, float pressure, int wifi_status) {
  static unsigned long last_counts = 0;
  static unsigned long last_hv_pulses = 0;
  static unsigned long last_timestamp = millis();
  static unsigned long last_count_timestamp = 0;
  if ((current_ms - last_timestamp) >= (MEASUREMENT_INTERVAL * 1000)) {
    if ((gm_count_timestamp == 0) && (last_count_timestamp == 0)) {
      // seems like there was no GM pulse yet and everything is still in initial state.
      // get out of here, we can't do anything useful now.
      return;
    }
    last_timestamp = current_ms;
    unsigned long counts = current_counts - last_counts;
    last_counts = current_counts;
    int dt = gm_count_timestamp - last_count_timestamp;
    last_count_timestamp = gm_count_timestamp;
    unsigned int current_cpm;
    current_cpm = (dt != 0) ? (int)(counts * 60000 / dt) : 0;

    int hv_pulses = current_hv_pulses - last_hv_pulses;
    last_hv_pulses = current_hv_pulses;

    log(DEBUG, "Measured GM: cpm= %d HV=%d", current_cpm, hv_pulses);

    transmit_data(tubes[TUBE_TYPE].type, tubes[TUBE_TYPE].nbr, dt, hv_pulses, counts, current_cpm,
                  have_thp, temperature, humidity, pressure, wifi_status);
  }
}

void loop() {
  static bool hv_error = false;  // true means a HV capacitor charging issue

  static bool have_thp = false;
  static float temperature = 0.0, humidity = 0.0, pressure = 0.0;

  unsigned long current_ms = millis();  // to save multiple calls to millis()

  // this is the always increasing HV pulse master counter.
  // main program: all other hv pulse counter values shall be derived from it.
  static unsigned long hv_pulses = 0;

  // this is the always increasing geiger mueller master counter.
  // main program: all other counter values for misc. purposes shall be derived from it.
  // ISR code: counters and other values there should be only short-lived and only be
  //           used to update values in main program.
  static unsigned long gm_counts = 0;

  // this is the master timestamp of the last geiger mueller event [ms]
  // main program: all other timestamp bookkeeping values shall be derived from it.
  // ISR code: only one timestamp shall be kept/updated there with the only purpose
  //           of being used to update the master timestamp.
  static unsigned long gm_count_timestamp;

  // time between last 2 geiger mueller events [us]
  unsigned int gm_count_time_between;

  read_GMC(&gm_counts, &gm_count_timestamp, &gm_count_time_between);

  read_THP(current_ms, &have_thp, &temperature, &humidity, &pressure);

  read_hv(&hv_error, &hv_pulses);
  set_status(STATUS_HV, hv_error ? ST_HV_ERROR : ST_HV_OK);

  int wifi_status = update_wifi_status();
  setup_ntp(wifi_status);

  update_ble_status();

  // do any other periodic updates for uplinks
  poll_transmission();

  publish(current_ms, gm_counts, gm_count_timestamp, hv_pulses, temperature, humidity, pressure);

  if (Serial_Print_Mode == Serial_One_Minute_Log)
    one_minute_log(current_ms, gm_counts);

  if (Serial_Print_Mode == Serial_Statistics_Log)
    statistics_log(gm_counts, gm_count_time_between);

  transmit(current_ms, gm_counts, gm_count_timestamp, hv_pulses, have_thp, temperature, humidity, pressure, wifi_status);

  long loop_duration;
  loop_duration = millis() - current_ms;
  iotWebConf.delay((loop_duration < LOOP_DURATION) ? (LOOP_DURATION - loop_duration) : 0);
}

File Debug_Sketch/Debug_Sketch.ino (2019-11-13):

//===========================================================================================
// Project: Simple Multi-Geiger, Code for Debugging
// (c) 2019 by the authors, see AUTHORS file in toplevel directory.
// License: see LICENSE file in toplevel directory.
//
// Revision History:
//const char* revString = "2019_03_25";   // Juergen Boehringer      Version 1 for ESP32-Board
const char* revString = "2019_05_07";   // Juergen Boehringer      added 1 Minute RS232-Logging-Mode
//
//===========================================================================================

// Includes
//   #include "WiFi.h"
#include <Arduino.h>
#include <U8x8lib.h>

#ifdef U8X8_HAVE_HW_SPI
#include <SPI.h>
#endif
#ifdef U8X8_HAVE_HW_I2C
#include <Wire.h>
#endif


// IOs
// ==========================================================
//  used for OLED:              4
//  used for OLED:             15
//  used for OLED:             16
//
//  used for optional LoRa    SX1276 (pin) => ESP32 (pin)
//  used for optional LoRa    ==========================
//  used for optional LoRa    SCK  = GPIO5
//  used for optional LoRa    MISO = GPIO19
//  used for optional LoRa    MOSI = GPIO27
//  used for optional LoRa    CS   = GPIO18
//  used for optional LoRa    RESET = GPIO14
//  used for optional LoRa    DIO0 (8) = GPIO26 (15)
//  used for optional LoRa    DIO1 (9) = GPIO33 (13)
//  used for optional LoRa    DIO2 (10) = GPIO32 (12)
int PIN_HV_FET_OUTPUT       =  23;  //
int PIN_HV_CAP_FULL_INPUT   =  22;  // !! has to be capable of "interrupt on change"
int PIN_GMZ_count_INPUT     =  17;  // !! has to be capable of "interrupt on change"
int PIN_SPEAKER_OUTPUT_P    =   2;
int PIN_SPEAKER_OUTPUT_N    =   0;

// Parameters
bool debug                  = false;// false: no debug output
                                    // true : debug output will be printed via RS232(USB)
bool OneMinuteLogging       = true; // false: no One Minute logging
                                    // true:  One Minute logging will be printed via RS232(USB)
bool speaker_tick           = true; // false: no GMZ-Tick, no flickering LED
                                    // true : GMZ-Tick will be sounded, LED flickers every GMZ-Tick

// Constants
const            float GMZ_factor_uSvph     = 1/2.47   ; // for SBM20
//const            float GMZ_factor_uSvph     = 1/9.81888   ; // for SBM19

									
// Variables
volatile bool          GMZ_cap_full           = 0;
volatile unsigned char isr_GMZ_counts         = 0;
volatile unsigned long isr_count_timestamp    = millis(); 
         unsigned char GMZ_counts             = 0;
         unsigned int  accumulated_GMZ_counts = 0;
         unsigned long count_timestamp        = millis(); 
         unsigned long last_count_timestamp   = millis(); 
         unsigned long time_difference        = 1000; 
         unsigned long accumulated_time       = 0; 		 
         unsigned char last_GMZ_counts        = 0;
         unsigned char speaker_count          = 0;
              uint32_t HV_pulse_count         = 0;
         float         Count_Rate             = 0.0;
         float         Dose_Rate              = 0.0;
         float         accumulated_Count_Rate = 0.0;
         float         accumulated_Dose_Rate  = 0.0;
         unsigned long lastMinuteLog          = millis();		 
         unsigned char lastMinuteLogCounts    = 0;
 
         
// ISRs
void isr_GMZ_capacitor_full() {
  GMZ_cap_full = 1;
}

void isr_GMZ_count() {
  isr_GMZ_counts++;                                     // Count
  isr_count_timestamp = millis();                       // notice (System)-Time of the Count
}


// Function Prototypes
int jb_HV_gen_charge__chargepules();
void DisplayGMZ(int TimeSec, int RadNSvph, int CPS);
void SoundStartsound();	
void jbTone(unsigned int frequency_mHz, unsigned int time_ms, unsigned char volume);






// Type of OLED-Display
U8X8_SSD1306_128X64_NONAME_SW_I2C u8x8(/* clock=*/ 15, /* data=*/ 4, /* reset=*/ 16);

void setup()
{
	// OLED-Display
    u8x8.begin();

    // set IO-Pins
    pinMode      (LED_BUILTIN,         OUTPUT);  
    pinMode      (PIN_HV_FET_OUTPUT  , OUTPUT);    
    pinMode      (PIN_SPEAKER_OUTPUT_P,OUTPUT);
    pinMode      (PIN_SPEAKER_OUTPUT_N,OUTPUT);
    
    // Initialize Pins
    digitalWrite (PIN_SPEAKER_OUTPUT_P, LOW);
    digitalWrite (PIN_SPEAKER_OUTPUT_N, HIGH); 
    
    // set Interrupts (on pin change), attach interrupt handler
    attachInterrupt (digitalPinToInterrupt (PIN_HV_CAP_FULL_INPUT), isr_GMZ_capacitor_full, RISING);// Capacitor full
    attachInterrupt (digitalPinToInterrupt (PIN_GMZ_count_INPUT), isr_GMZ_count, FALLING);          // GMZ pulse detected
	
    // set and init Serial Communication (if required)
    if (debug == true) {
      noInterrupts();
      Serial.begin(115200);
      while (!Serial) {};
  	                              // while(1){
                                  //   digitalWrite(PIN_HV_FET_OUTPUT, HIGH);
	                              //   delayMicroseconds(1500);              									
                                  //   digitalWrite(PIN_HV_FET_OUTPUT, LOW); 
	                              //   delayMicroseconds(1500);              									
                                  // };
                                 // pinMode      (0,         OUTPUT);  
                                 // pinMode      (2,         OUTPUT);  
								 // while(1){
                                 //   digitalWrite(0, LOW);  
                                 //   digitalWrite(2, HIGH);  
                                 //   delayMicroseconds(1000);
                                 //   digitalWrite(0, HIGH);   
                                 //   digitalWrite(2, LOW);   
                                 //   delayMicroseconds(1000);	                        
                                 // }

	
      // Write Header of Table	
      Serial.println("----------------------------------------------------------------------------------------------------------------------------------------------------");	  
      Serial.print  ("Simple Multi-Geiger, Version ");
      Serial.println(revString);
      Serial.println("----------------------------------------------------------------------------------------------------------------------------------------------------");	  
      Serial.println("GMZ_counts\tTime_difference\tCount_Rate\tDose_Rate\tHV Pulses  \tAccu_GMZ  \tAccu_Time \tAccu_Rate         \tAccu_Dose");
	  Serial.println("[Counts]  \t[ms]           \t[cps]     \t[uSv/h]  \t[-]        \t[Counts]  \t[ms]      \t[cps]             \t[uSv/h]");
      Serial.println("----------------------------------------------------------------------------------------------------------------------------------------------------");	  
      interrupts();	  
    }
	
    // set and init Serial Communication (if required)
    if (OneMinuteLogging == true) {
      noInterrupts();
      Serial.begin(115200);
      while (!Serial) {};
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

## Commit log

2019-05-14 Start des Projektes auf GitHub
    [MultiGeiger.xls]
2019-08-30 Sending to 'luftdaten' and 'madavi' OK IoTWebConfig instead of WiFiManager first piblic version
    [MultiGeiger.xls]
2019-08-30 Revision string adapted Readme corrected
    [multigeiger.ino]
2019-09-01 Build SSID from MAC corrected Readme.md adapted Moved IoTWebConfig to src path Added setThingName to IoTWebConfig More user selctable #defines
    [multigeiger.ino]
2019-09-02 Sendstring to madavi corrected
    [multigeiger.ino]
2019-10-01 - use switch for speaker and display off/on - cleardisplayline added
2019-10-27 renamed userdefines.h to userdefines-example.h
    people shall not edit a version controlled file to adapt to
    their use case / hardware.
2019-10-27 fix SBM20 conversion factor selection, support Si22G GM tube
    SBM20: the correct conversion factor was not set up due to a code bug
    Si22G: was not dealt with at all in previous code.
    now correct dummy code is in place, but the conversion factor value
    needs to be fixed still, see XXX FIXME.
    [multigeiger.ino]
2019-11-03 fix indentation / spacing
    no code changes.
    trying to be at least "locally consistent".
    [multigeiger.ino]
2019-11-03 language consistency: ANZEIGE_ON -> DISPLAY_ON
    Had to rename the DISPLAY_ON pin definiton to PIN_DISPLAY_ON,
    this is also better consistent with other pin defs.
2019-11-03 language consistency: rohr -> tube, ROHRNAME -> TUBE_TYPE
2019-11-12 added EAGLE Files fixed Readme.md added GPL cps_to_uSvph for unknown tube factors now 0.0 sending software_version to luftdaten again
    [geiger_V1.4.brd, geiger_V1.4.sch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]
2019-11-12 fixed spelling, deleted price information
    [MultiGeiger_Partlist.ods]
2019-11-12 removed trailing blanks (again)
    can we configure our editors to avoid this creeping in
    again and again?
    [multigeiger.ino]
2019-11-12 fix typos in src comments
    [multigeiger.ino]
2019-11-12 removed bundled MCCI_LoRaWAN_LMIC_library
    it can be installed like all the other libraries,
    via the arduino IDE's library manager.
    the docs already mention that.
2019-11-13 README: fix typos, update for current code, rephrase
2019-11-14 remove pointless comments, fixes #27
    [multigeiger.ino]
2019-11-16 fix typo: chargepules -> chargepulses
    [multigeiger.ino]
2019-11-16 fix some more typos in output and commented code
    [multigeiger.ino]
2019-11-16 fix language: GMZ -> GMC
    Geiger-Mueller-Zaehler/Zaehlrohr -> GM-Counter
    GMT (like Geiger-Mueller-Tube) was not chosen due to the similarity to
    the old UTC timezone name.
    [multigeiger.ino]
2019-11-17 fix code indentation, no functional changes
    that GMC_cap_full indentation let me think it is a local variable
    declaration (and thus, a bug) for a while, due to it being indented
    with the variable declaration directly above it.
    but it is not, it is correctly resetting the global flag.
    also append the while() to the do-block, better understandable like
    that.
    also fix some minor de-alignments.
    [multigeiger.ino]
2019-11-17 unknown tube: use 0.0 conversion factor
    (see also current conversion factor of Si22G tube, we also use
    0.0 there, for the same reason)
2019-11-18 add a FIXME comment asking for sources for the conversion factors
    and also how they were determined / how they are computed.
    [multigeiger.ino]
2019-11-18 the internal temp sensor is obsolete / unsupported
    see https://github.com/espressif/arduino-esp32/issues/2422
    (and it seems they really had a typo "temprature" in the
    API function while it was supported...)
    [multigeiger.ino]
2019-11-19 move hw docs into docs/hardware/, fixes #63
    [MultiGeiger_Partlist.ods]
2019-11-19 isr routines now esp32 conform removed all "nointerrupt()/interrupt()" fixed a few global variables changed char variables to int
    [multigeiger.ino]
2019-11-23 Serial_Logging: fixed output format / consistency, fixes #81
    [multigeiger.ino]
2019-11-23 One_Minute_Log: fixed output format, related to #81
    [multigeiger.ino]
2019-11-24 added comment concerning isr
    fixed portEXIT
    [multigeiger.ino]
2019-12-05 GMC_cap_full -> isr_GMC_cap_full, fixes #89
    [multigeiger.ino]
2019-12-05 make time_difference local, fixes #69
    [multigeiger.ino]
2019-12-07 correct Si22G conversion factor, fixes #20
    thanks for Juergen for determining the factor!
    [multigeiger.ino]
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2019-12-08 fix not working speaker and led tick, fixes #97
    [multigeiger.ino]
2019-12-08 LED/speaker tick: fix conditions for alternative delay
    if we want the speaker tick, the tick generation does a delay of 4ms total.
    else we need to do an alternative delay of 4ms (so that the LED is on
    for 4ms) - but ONLY if the LED is enabled.
    this fixes 2 inconsistent conditions for speaker and LED.
    [multigeiger.ino]
2019-12-08 only reset isr_GMC_counts if the display will be updated, fixes #101
    also: move some not so timing critical stuff to the end of the loop.
    [multigeiger.ino]
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2019-12-16 display for wireless stick fixed
    defaults in userdefines_example.h changed
    software version for lora now 2 bytes
    gitignore flash directory
    [multigeiger.ino]
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2019-12-25 changed luftdaten.info to sensor.community
    changed sbm-20 to si22g
2019-12-25 added how to change name for other tubes
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2020-01-11 add TUBE_UNKNOWN 0 to have a specific value for experimenting
    if one experiments with a not-yet-supported tube, one wants to
    select the entry at index 0 in the tubes array (which is "Radiation
    unknown" with a CPM to uSv/h conversion factor of 0.0).
    Not sure whether sensor.info and other sites can deal yet with that
    sensor type (if values are accidentally submitted), but I guess they
    should ignore type 0 tube measurements.
    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
2020-01-11 output error msg on Serial if HV charging fails
    also: add a constant MAX_CHARGEPULSES
    [multigeiger.ino]
2020-01-11 MAX_CHARGEPULSES 1000 -> 333, fixes #134
    As this is usually ~1 (as seen in serial output), this can be
    significantly lowered.
    For now, I only lowered it a little bit, so that the "less than 1s"
    condition is satisfied: 333 * 2.6ms < 1000ms
    Also, 333 can be easily spotted in serial output. :)
    [multigeiger.ino]
2020-01-11 cosmetic: rename to (gen_|max_|)charge_pulses, fixes #132
    [multigeiger.ino]
2020-01-12 use more charge pulses for initial charge call
2020-01-12 Revert "add simple OTA (via browser upload) functionality, see #120"
    This reverts commit 10d928dbfc6c971a6bb0b59f66b1071783eef871.
    IotWebConf has a builtin updater (which is a bit more simple-looking,
    has no jQuery based progress display, but also no jQuery loading
    issues). So we will use that.
    [multigeiger.ino]
2020-01-12 add OTA based on IotWebConf
    IotWebConf has a builtin OTA updater, which lets the user
    upload firmware updates on the configuration web page of
    the MultiGeiger.
    It's quite similar to the code I implemented, so less own code
    is better. ;-)
    It also does not have the problematic jQuery based progress display.
    [multigeiger.ino]
2020-01-13 dirty hack for replacing IotWebConf.setThingName()
    seen there:
    https://github.com/prampec/IotWebConf/issues/69#issuecomment-560154627
    [multigeiger.ino]
2020-01-19 improved documentation for people without prior Arduino/ESP experience
    1. Eine "U8g2 von Oliver, Version 2.16.14" gibt es nicht. 2.26.14 dagegen schon und das Projekt compiliert damit.
    2. Link für die Heltec Board-Repositories in die Doku gepackt. Wo man das herbekommt, ist sonst nicht offensichtlich.
2020-01-24 Updated, mainly because TWs better 5 V Supply is used
2020-02-11 new log(level, format, ...) function, fixes #161
    - printf-style call
    - only outputs for level >= log_level
    - levels: DEBUG, INFO, WARNING, ERROR
    - internally prepends "GEIGER: " to differentiate our output from other
    - adds correct line endings by using Serial.println()
    [multigeiger.ino]
2020-02-11 output the whole log line in one Serial.println() call
    not sure if it would otherwise mix up our messages with esp32 messages.
2020-02-11 fixup: do va_end earlier
    [multigeiger.ino]
2020-02-11 fixup: increase log level of HV charging issue to CRITICAL
    [multigeiger.ino]
2020-02-11 fix indentation issue found by astyle on travis
    [multigeiger.ino]
2020-02-11 platformio on travis has issues with the U8g2 entry
    try if multi-line and some addtl. blanks help.
    error message:
    LDF: Library Dependency Finder -> http://bit.ly/configure-pio-ldf
    LDF Modes: Finder ~ chain, Compatibility ~ soft
    Looking for U8g2@> library in registry
    Warning! Library `{'name': 'U8g2@>', 'requirements': '>=1.0.2,'}` has
    not been found in PlatformIO Registry.
2020-02-12 New 5V Power Supply (including adapters and cables)
    ... based ot TWs Idea
    [MultiGeiger_Partlist.ods]
2020-02-14 use bump2version tool for version bumps, fixes #169
    derive everything from VERSION_STR, kill VERSION_DATE
    bump2version can only deal with the string, not with dates.
    the lora_software_version value is now computed from the string.
    the date of a release can be looked up in the changelog (or in git).
    for the version string, we display as much of it as possible
    on the specific display (by just truncating it).
    so if the display is wide enough, even the "release" part,
    like "-dev" for development versions will be displayed or
    partly displayed.
    move version to version.h
    [.bumpversion.cfg]
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2020-02-17 fix logging in tube module
    [tube.cpp]
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2020-02-20 slight cleanup, group stuff together, astyle fixes
    [display.cpp, display.h, multigeiger.ino]
2020-02-20 loraWan: fix datatype name typo
    [loraWan.cpp]
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2020-02-20 loraWan: remove F() from strings
    @rexfue noted:
    On ESP32 it is not necessary, ESP32 always puts const
    (literal) strings into flash and handles it transparently.
2020-02-20 loraWan: fix unhandled cases in switch-statement
    not sure this is the most correct way to deal with that case,
    but i did not change behaviour, just fixed the compiler warning:
    loraWan.cpp:299:18: error: enumeration value 'TX_STATUS_ENDING_ERROR'
    not handled in switch [-Werror=switch]
    switch ( txStatus ) {
    same for TX_STATUS_TIMEOUT.
    [loraWan.cpp]
2020-02-20 loraWan: log_event: fix timestamp type
    [loraWan.cpp]
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2020-02-20 fix preprocessing, standard include ifndef-define-endif dance
    [display.h, multigeiger.ino]
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2020-02-21 remove bme/BME from variable names, fixes #210
    [multigeiger.ino]
2020-02-21 use a bitfield for the dipswitches, fixes #209
    [multigeiger.ino, switches.cpp]
2020-02-21 loraWan: cleaned up comments / style, fixes #155
    [loraWan.cpp]
2020-02-22 cleanup div-by-zero avoiding code fragments
    [multigeiger.ino]
2020-02-22 fix 1-minute timing condition
    [multigeiger.ino]
2020-02-22 shorter expression to avoid div-by-zero
    [multigeiger.ino]
2020-02-22 replace long license legalese by a shorter version.
    [multigeiger.ino]
2020-02-22 fixup: int is enough for dt
    [multigeiger.ino]
2020-02-22 use a separate boot_timestamp for the AFTERSTART display
    the transmission_timestamp has nothing to do with that,
    except that it is also initialized to millis() at boot time.
2020-02-24 send to MADAVI in one single request both geiger and thp
    add sensor name if sending to MADAVI
    define magic numbers for XPIN
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2020-03-02 Use webpage to to set configuration, fixes #140
    lorawan.cpp:
    - only compile, if CPU==STICK, i.e if we have LoRa Hardware
    - fetch LoRa credentials from config variables
    multigeiger.ino:
    - use config variables instead of userdefines
    transmission.cpp:
    - replace SEND2LORA by CPU==STICK
    - use config variables to decide where to send
    - send to LoRa only, if LoRa credentials are known
    webconf.cpp
    - add all config variable to web page
    - do restart after saving config
    userdefines-example.h
    - remove now unnecessary #defines
    [loraWan.cpp, multigeiger.ino]
2020-03-11 #define reintroduced and use bool variables
    display.cpp
    - fixed 10sec on/off if display is swiched off by #define
    lorawan.cpp
    - included webconf.h
    multigeiger.ino
    use bool variables instead of function
    transmission.cpp
    also use bool variables
    utils.cpp/utils.h
    new - holds div. utilities
    - define the bool variables
    - init config variables
    - load config varables after config save and after init
    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
    [display.cpp, loraWan.cpp, multigeiger.ino]
2020-03-12 fixed some oddities - restored #defines in userdefines-example.h
    [loraWan.cpp]
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2020-04-08 check if LoRa chip or not by hardware pin
    test, if pin 26 (LoRa DIO) is low. If yes, then it is LoRa hardware.
    Change in every file the "#if CPU == STICK" to "if (isLoraBoard) {}"
    wifi_connected variable is now static.
2020-04-14 Bump version: 1.12.1-dev → 1.13.0
    [.bumpversion.cfg]
2020-04-14 bump to 1.13.1-dev, add new changelog section
    [.bumpversion.cfg]
2020-04-16 Name of boards manager fixed
2020-05-02 dip switches: only read once at boot time, fixes #207
    [multigeiger.ino]
2020-05-03 slow down main loop
    it doesn't need to spin once every 1-2ms, but otoh it also must
    not spin too slow as the speaker tick (and also led tick) is done
    in main loop.
    [multigeiger.ino]
2020-05-03 do not use test pin except when enabled, see #220
    having a test pin that is toggled while the ISR for GM pulse counting
    is active is nice for hardware debugging (e.g. with oscilloscope), but
    not needed for production use.
    by using a preprocessor #if block, the 2 digitalWrite() calls are not
    done in production, which likely speeds up the ISR processing quite a
    bit.
2020-05-03 simplify ISR, bookkeeping in main loop, fixes #220
    [multigeiger.ino, tube.cpp]
2020-05-04 refactor pulse counting, fixed debouncing, fixes #248
    fix: dead time computation was wrong: the dead time starts after last
    VALID pulse, but the code was comparing to ANY last pulse.
    refactor: used simpler variable names, got rid of 1 unneeded variable,
    made deadtime condition easier to read.
    [tube.cpp]
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2020-05-04 removed "Fixme" and more
    [loraWan.cpp]
2020-05-04 add clock module, use NTP to set the clock
    for correct TLS support, we need correct time.
    [multigeiger.ino]
2020-05-07 display.cpp - new font for status, prepare BLE connectivity, CPS->CPM (#253)
    display: prepare for BLE connectivity
    - new font (u8x8 uses 8px width anyway)
    - bugfix: changed parameter name from CPS to CPM
    [display.cpp, display.h, multigeiger.ino]
2020-05-09 display.cpp adaptions also for Lora board (#255)
    adapt display code for LoRa board, too
2020-05-09 timer interrupt driven, adaptive hv charging, fixes #192
    [multigeiger.ino, tube.cpp]
2020-05-10 fix/refactor clearDisplayLine
    the old code put the terminating \0 at the wrong place,
    so the result was 9 chars wide instead of the desired 8.
    the new code avoids this issue and is also simpler.
    [display.cpp]
2020-05-11 implement status display, fixes #257
    [display.cpp, display.h, multigeiger.ino]
2020-05-11 fix "time in between" init
    this is a time **difference** not an absolute timestamp.
    [tube.cpp]
2020-05-11 pulse counting: fix uint32 microseconds overflow, fixes #273
    [tube.cpp]
2020-05-12 timer driven audio/led sequencer, PWM sound, fixes #35
    hardware PWM (with complementary outputs) for sound (ticks and tones).
    timer driven audio sequencer, supports tones, speaker and LED "ticks".
    can be fed with a list of (frequency, volume, led, duration) integers.
    geiger mueller "tick" at 5000Hz, debug "tock" at 1000Hz.
    [multigeiger.ino, speaker.cpp, tube.cpp]
2020-05-12 add bme680 library for basic THP readout of BME680
    add bme680 library for basic THP readout of BME680
    small fixes, use type_thp instead of have_thp, updated README
    changed BME init sequence
    fix astyle issues
    [multigeiger.ino]
2020-05-13 speaker: avoid compiler warning (#282)
    the compiler warning ("... is used before initialized") is a false positive,
    but let's just initialize the vars to get rid of it.
    [speaker.cpp]
2020-05-13 status display: keep showing transmission errors
    in case of some unsuccessful transmission attempt, the error code was
    only shown for a short time and then replaced by idle status again.
    fixed, now the error code is shown until the transmission is retried.
    also removed some unneeded status display related code for BT and LoRa,
    the initial state is "NODISPLAY" anyway.
    [multigeiger.ino]
2020-05-13 fix race condition, fixes #286
    it could happen that display() was called before there was any GM event.
    in that case, there were 2 timestamps initialized to millis() at different
    times in program setup / subsystem setup time and dt could become
    negative.
    removed the millis() and just used 0 to initialize both.
    check for the special condition and do not display/log/transmit anything
    in that case.
    [multigeiger.ino, tube.cpp]
2020-05-13 fix off-by-1 error in tube ISR timing
    [tube.cpp]
2020-05-13 switches: cosmetic consistency fixes
    [switches.cpp]
2020-05-14 display: replace nullFill by sprintf
    [display.cpp]
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2020-05-14 remove "cpm" text output, fixes #298
    this gets overwritten by the status display on the smaller display.
    on the larger display we do not output "cpm" as text.
    [display.cpp]
2020-05-14 status display: add init status ("?"), docs, fixes #295
    [display.cpp, display.h]
2020-05-15 speaker/led ticks: make temporary disable possible
    the speaker/led ISR accesses some library code that is stored in flash,
    not in IRAM. this can lead to fatal exceptions.
    usually this is no big issue, because there is also a RAM cache for code
    loaded from flash, but with heavy flash access that doesn't suffice.
    tick_enable(false) will temporarily disable the led/speaker ticking and
    avoid library calls and thus makes the ISRs safe, no exceptions even when
    flashing firmware or storing settings into flash.
    tick_enable(true) will restore ticking/blinking to the state wanted by
    user / configuration.
    [speaker.cpp]
2020-05-16 Bump version: 1.13.1-dev → 1.14.0
    [.bumpversion.cfg]
2020-05-16 Bump version: 1.14.0 → 1.15.0-dev
    [.bumpversion.cfg]
2020-05-21 Board and Schematic V1.4
    [geiger.brd, geiger.sch]
2020-05-21 add locales (only "de" for now)
    translation happens on transifex, this is:
    - a backup
    - likely needed for readthedocs also
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2020-05-22 new github "front page" README
    - point to the translated docs on RTD (en + de)
    - point to legacy "README" (de)
    - point to legacy odt files (de)
2020-05-22 BLE connectivity (#311)
    add bluetooth (BLE) support, fixes #78
    - implement BLE heart rate service with notifications about current CPM rate
    - use "unused" switch for "ble_on"
    - allow configuration via webconf
    [multigeiger.ino, switches.cpp]
2020-05-22 moved links to docs -> resources, fixes #223
    also:
    - updated links
    - added wireless stick link
    - remove blog posts and links to older lora hw
    [multigeiger.ino]
2020-05-22 do async NTP/clock setup, fixes #316
    [multigeiger.ino]
2020-05-22 remove "Version:" from start screen, fixes #335
    [display.cpp]
2020-05-22 BLE: naming consistency (cosmetic), fixes #315
    [display.cpp, display.h, multigeiger.ino]
2020-05-23 docs: document dip switch usage, fixes #128
2020-05-23 docs: document esp32 board buttons, fixes #129
2020-11-21 Missing Drill-Files added
    [drill_1_16.xln]
2020-12-30 add missing drill files
    [drill_1_16.xln]
2021-01-10 Create multigeiger-bill-of-material.txt
    BOM / Bill of Material of Multigeiger. Edit this file with UTF-8 encoding activated. If you use Excel use "65001: Unicode (UTF-8)" as file origin ("Dateiursprung") in dialog. Preferably use Notepad++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
2021-03-01 work around LMIC bug #677
    [loraWan.cpp]
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2021-03-21 Update multigeiger-bill-of-material.txt
    Added optional parts as suggested in https://github.com/ecocurious2/MultiGeiger/pull/369#issuecomment-760211034
2021-03-21 speaker: init "duty_mode" member in MCPWM config
    I've seen a traceback pointing to an MCPWM issue
    and found that this member of the struct has not been
    initialized yet.
    [speaker.cpp]
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2021-03-21 Bump version: 1.15.0-dev → 1.15.0
    [.bumpversion.cfg]
2021-03-21 Update multigeiger-bill-of-material.txt
    small typo corrected see https://github.com/ecocurious2/MultiGeiger/pull/369#discussion_r598326488
2021-03-23 Bump version: 1.15.0 → 1.16.0-dev
    [.bumpversion.cfg]
2021-03-25 initialize sound and LED to "off", fixes #398
    [speaker.cpp]
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2021-04-02 Changed switch numbering, fixes #349
    [geiger.sch]
2021-04-04 Switch numbering left to right
    [geiger.brd, geiger.sch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]
2021-05-04 BLE via NimBLE-Arduino lib
    astyle issues try #1
    astyle issues try 2
    astyle issues try 3 - unary operator position
    astyle issues try 4 - if<space>(condition)
2021-05-06 Fix sensor.community domain
2021-05-13 Bump version: 1.16.0-dev → 1.15.1
    [.bumpversion.cfg]
2021-05-13 Bump version: 1.15.1 → 1.16.0-dev
    [.bumpversion.cfg]
2021-06-18 lora: replace event_log() by log()
    as log() now always adds a timestamp, there is no need for a custom event_log()
    that just adds a timestamp any more.
    [loraWan.cpp]
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2021-06-21 sequencer fix: reset playing_tick/playing_audio to false
    thanks to @t-pi for discovering this bug!
    [speaker.cpp]
2021-07-03 sequencer fix: avoid accessing global outside of mutex block
    isr_sequence is a global variable and we must not access it without holding the mux_audio mutex.
    fix: use p, it is a local variable and gets the value of isr_sequence WHILE holding the mutex.
    thanks to @t-pi for discovering this issue!
    [speaker.cpp]
2021-08-15 Bump version: 1.16.0-dev → 1.16.0
    [.bumpversion.cfg]
2021-08-15 Bump version: 1.16.0 → 1.17.0-dev
    [.bumpversion.cfg]
2021-09-12 fix uptime display - casting brackets (#441)
    uptime display: fix type casting parens
    also: change all display time variables to unsigned
    [display.cpp, display.h, multigeiger.ino]
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2022-06-25 fixed schematic/layout error with new hardware
    [geiger.brd, geiger.sch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]
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

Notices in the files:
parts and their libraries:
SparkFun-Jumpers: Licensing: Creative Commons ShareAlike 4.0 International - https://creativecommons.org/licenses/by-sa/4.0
